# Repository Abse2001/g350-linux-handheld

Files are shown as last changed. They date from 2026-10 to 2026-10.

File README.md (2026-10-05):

# G350 AM3352 Linux handheld — in progress

**Cloud continuation:** start with [the complete handoff](docs/CLOUD_HANDOFF.md),
[the original user-visible chat](docs/CHAT_CONTEXT.md) and [AGENTS.md](AGENTS.md).
The full authored project and hash-indexed ignored routing evidence are preserved;
restore with `python3 scripts/restore-cloud-evidence.py`. Ubuntu cloud setup is
`bash scripts/setup-cloud.sh`, followed by `source cloud/env.sh` in each shell.
The checked default is still the eleven-signal byte0 subset. Latest byte1 source
replays and native failures are preserved separately; their aggregate/remaining
independent checks are pending. This transfer does not make the PCB order-ready.

The selected processor is a **bare TI AM3352BZCZ100**, directly on the main PCB, with **512 MB Micron MT41K256M16TW-107:P DDR3L** operated in DDR3-compatible mode. The user chose AM3352 for simple games rendered by the CPU; a 3D GPU is no longer required. The design is authored in **tscircuit**, using individually imported JLCPCB components. No complete SBC or processor module is imported.

**The integrated handheld is not ready to fabricate or order.** The current checked routing entry is [`experiments/am3352-g350-byte0-complete-bus.circuit.tsx`](experiments/am3352-g350-byte0-complete-bus.circuit.tsx): **280 placed components, four copper layers, a 76 × 118 mm shaped outline and 1.6 mm nominal thickness**. The lower speaker tab is 22 mm wide with a 19 mm extension. This routing entry and its CPU/RAM power replay both match the shared mechanical geometry; run `node scripts/check-g350-mechanical-envelope.mjs` to check them. These are provisional dimensions inside the published exterior envelope; mounting posts, shell ribs and button/port alignment remain unmeasured. The default `index.circuit.tsx` now opens this current shaped handheld. Older 212-component routing fixtures remain historical experiments; their channel counts do not qualify this layout. DDR and other critical routing, Linux provisioning and original-shell fit remain unfinished. The fabrication exporter remains blocked by `design-status.json`.

On the current shaped board, **all 101 CPU/RAM ground and DDR supply terminals** reach their correct filled reference planes through 97 physical vias. **All eleven byte0 signals** use native `bus_lanes` carriers and manually repaired routes, with their complete source-bus definition restored. Byte0 planar skew is **0.207792 mm against 0.635 mm**; strobe-pair skew is effectively zero against 0.127 mm. Numeric-pad connectivity, all-layer Gerber shorts and independent physical DRC pass for this subset. The source has **112 traces and 119 standard through-vias**. There are **38 DDR signals to route**, 403 silkscreen warnings, 818 open-port errors and 108 missing-trace errors. Bypass loops, complete timing and stackup impedance remain unqualified. [Current routing checks](checks/integrated/g350-byte0-complete-bus/check-summary.json), [bottom snapshot](checks/integrated/g350-byte0-complete-bus/g350-byte0-bottom.png), [routing notes](docs/G350_CURRENT_DDR.md). The separate byte1 experiment now has 22 manual package escapes with zero native geometry errors. Its native `bus_lanes` carrier attempt exhausted the strobe-pair search budget; the actual-source fanout replay returned the cached escapes but its implicit completion stage exceeded the external deadline. No completed byte1 source or new connected signals are qualified; the checked default is preserved. [Experimental findings](checks/integrated/g350-ddr-bootstrap/byte1-package-access-findings.json).

The completed handheld must have eleven front buttons, an FPC display, an onboard microSD holder and one USB-C connector for charging and data/provisioning. Components and copper routing are allowed on both sides. There are no analog sticks or rear buttons.

The historical command package-access study independently verifies **all 48 CPU/RAM pad-to-via exits for the 24 command/control signals**, while retaining both data bytes, reset and the clock pair. Shorts, copper/drill clearance and filled RAM reference checks pass. The diagnostic has 25 retained complete DDR channels, 48 dangling terminal-via warnings and 24 unfinished commands. Subsequent phased native routing plans six carriers; manual repair plans five more, leaving 13 unresolved. These carriers still need a combined editable replay and independent checks. The best checked complete-signal subset remains DDR42. [Package-exit evidence](checks/integrated/am3352-command-compatible-fanouts-802-check-summary.json). Fabrication remains blocked; no remote publication was made.

The latest separate **DDR42 checkpoint connects 42/49 DDR signals**, with 144 trace pieces and 187 full-depth through-vias. Independent numeric-pad connectivity, all-layer Gerber shorts and physical clearance/drill checks pass. Both byte groups and all three differential pairs pass relative planar skew. **Seven signals remain open:** A3, RASn, WEn, A2, A12, A11 and CKE. Seventeen command/clock nominal lengths and seven reduced-spacing exposures need repair; complete DDR timing and signal integrity remain unqualified. The updated `bus_lanes` phase preserves the fixed copper and physical pads but has no complete new output. [Checked evidence](checks/integrated/am3352-command-fine-782-replay-check-summary.json), [editable replay](experiments/am3352-command-fine-782-replay.circuit.tsx), [native phase entry](experiments/am3352-command-fine-782-replay-native-phase.circuit.tsx). At that historical checkpoint the default stayed DDR30; fabrication remains blocked.

The previous spacing-repaired **copper checkpoint connects 33/49 DDR signals**, with 135 trace pieces and 169 through-vias. A guarded wire-only D12 shortcut repairs its reduced class-spacing exposure from **32.176112 mm to 28.195190 mm**, within the **31.75 mm allowance**, without changing any holes or other routes. D12 is **50.983197 mm**; byte0/byte1 relative skews are **0.157421/0.496669 mm** and all three pairs retain their relative limits. Fresh native DDR/USB/filled-reference connectivity, all-layer Gerber shorts and physical DRC pass, with 418 presentation warnings, 499 reported/capped host opens and recorded ignored checks. **Sixteen DDR signals remain open**; CK/CKn/CKE/A3/A6 nominal repairs and complete spacing, impedance, return-path, termination and timing qualification remain required. [Checked copper](checks/integrated/am3352-ddr-usbc-d12-spacing-repaired-check-summary.json), [partial spacing audit](checks/integrated/am3352-ddr33-d12-repaired-class-spacing.json), [top](images/am3352-ddr-usbc-d12-spacing-repaired-top.png) and [bottom](images/am3352-ddr-usbc-d12-spacing-repaired-bottom.png). Revalidate with `npm run check:ddr-d12-spacing-evidence` and `npm run check:ddr-class-spacing`. That historical checkpoint retained the 30/49 default; fabrication remains blocked.

A separate **bottom-side RAM placement study** retains all 212 host components, 912 pads and 49 logical DDR connections. RAM references and shared USB-C copper pass fresh independent checks on four layers; fourteen small RAM bypass capacitors move to top, and all 89 existing holes remain standard 18/10 mil through-vias. DDR is entirely unrouted in this study. Native all-channel and ordered-fanout trials **704–709** prepare real endpoints but have no complete output; no partial routes are promoted. An initial eight-USB-via size failure is retained as rejected evidence, followed by a corrected, checked rebuild. [Placement checks](checks/integrated/am3352-ram-bottom-via-style-corrected-check-summary.json), [seven bound terminal trials including D12 repair 703](checks/integrated/am3352-ddr33-d12-ram-bottom-trial-status.json). Revalidate with `npm run check:ram-bottom-evidence` and `npm run check:ddr-d12-ram-bottom-trials`.

The newer bottom-RAM replay has **28/49 connected DDR signals**, comprising **19 retained native bus-lane paths and nine manual paths**. All original 102 host/USB/reference trace pieces and 89 physical holes remain exact; this candidate has 130 trace pieces and 129 through-vias. Independent numeric-pad DDR/USB and filled-reference connectivity, all-layer shorts and physical DRC pass. **21 DDR signals remain open**, both byte groups are incomplete, and command matching/nominal lengths remain unqualified. Its separate placement-derived command target is **40.62 mm**; this does not change the top-RAM target. All 28 connected paths pass the partial reduced-spacing exposure limit, with a maximum of 31.421059 mm; complete spacing and signal integrity remain unchecked. A selected-terminal-via search-model bug was corrected and regression checked. The unsolved native run is retained as provenance, rather than represented as a solved 49-channel output. [Checked replay](checks/integrated/am3352-ram-bottom-flexible-fanout-747-replay-check-summary.json), [electrical review](checks/integrated/am3352-ram-bottom-flexible-fanout-747-replay-spacing-and-nominal-review.json), [38 terminal trials](checks/integrated/am3352-bottom-manual-trial-status.json), [top](images/am3352-ram-bottom-flexible-fanout-747-replay-top.png) and [bottom](images/am3352-ram-bottom-flexible-fanout-747-replay-bottom.png). That historical study retained the 30-signal default and separate 33-signal checkpoint. Nothing was pushed or released for ordering.

The earlier **A6 copper bootstrap connects 32/49 DDR signals** in one source, with 134 trace pieces and 163 through-vias. It supplies the checked prior geometry for the CASn replay. Its A6=51.715840 mm and A3=45.411583 mm nominal failures remain required repairs. [Prior scoped checks](checks/integrated/am3352-ddr-usbc-a6-bootstrap-check-summary.json); `npm run check:ddr-a6-bootstrap-evidence`.

The earlier **A3 copper bootstrap connects 31/49 DDR signals**, with 133 trace pieces and 161 through-vias. It preserves every checked DDR30 trace and hole. Native DDR/USB/reference connectivity, all-layer shorts and physical DRC pass, but **A3=45.411583 mm fails the nominal range**. The wire-only shortcut search could not bring it into range. This checkpoint supplies the checked prior copper for the separate A6 replay. [A3 bootstrap checks](checks/integrated/am3352-ddr-usbc-a3-bootstrap-check-summary.json). Revalidate with `npm run check:ddr-a3-bootstrap-evidence`.

Earlier DQM1/D10 access trials routed native CASn and CSn0 but could not restore the two data routes. Those incomplete stages remain non-exportable and are superseded by the complete D3-coupled replay above. [Historical bound trials](checks/integrated/am3352-ddr32-casn-neighbor-replan-trial-status.json); `npm run check:ddr-casn-neighbor-replan-trials`.

The board must **fit the original G350 shell**. Its listed 81 × 128 × 22 mm outside dimensions do not establish the internal PCB outline. The working G350 outline is **76 × 118 mm**, with chamfered corners and a lower speaker tab; see the [dimensioned drawing](mechanical/g350-provisional-outline.svg). The nominal centered margins from the outside case are 2.5 mm per side and 5 mm per end; the USB-C assembly courtyard projects 0.651 mm past the top PCB edge. These are engineering allowances, not measured internal clearances or a verified original-board replacement. The historical 100 × 124 mm routing fixture does not fit the case and is not the mechanical target. Original screw posts, button centers, port openings and assembly clearances still require verification. [Shell-fit requirements](docs/G350_SHELL_FIT.md).

The historical DDR30 default was `experiments/am3352-ddr-usbc-wen-nominal.circuit.tsx`: **30/49 DDR signals connected**, with **132 trace pieces and 157 through-vias**. A native `bus_lanes` WEn carrier inside the DDR reference bounds and guarded manual package fanouts give **WEn=43.228641 mm**, within the placement-derived 41.75–44.29 mm nominal range. Every checked DDR29 trace and hole remains unchanged. A5 remains **43.020000 mm**, CSn0 **42.800714 mm**, ODT **43.018281 mm** and D14 **50.919109 mm**. Both bytes and all three differential pairs retain their checked relative planar limits. Exact native DDR/USB/reference connectivity passes, with zero all-layer Gerber shorts and reported physical DRC violations, 418 presentation warnings and 499 reported/capped host opens. All 18 RAM supply balls, 21 ground balls and 28 bypass terminals reach the connected filled reference planes. Configured ignored native checks remain recorded. CKE/clock nominal lengths still fail; the **19 remaining address/control signals**, full command matching, package/via delays, coupling/impedance, powered host/Linux and original-shell fit remain unqualified. [Checked evidence](checks/integrated/am3352-ddr-usbc-wen-nominal-check-summary.json); [top](images/am3352-ddr-usbc-wen-nominal-top.png) and [bottom](images/am3352-ddr-usbc-wen-nominal-bottom.png) snapshots. Revalidate with `npm run check:ddr-wen-evidence`. Earlier candidates below are historical evidence.

The historical DDR28 replay is `experiments/am3352-ddr-usbc-csn-joint.circuit.tsx`: **28/49 DDR signals connected**, with **130 trace pieces and 149 through-vias**. A native `bus_lanes` CSn0 carrier and guarded manual package fanouts add **CSn0 at 42.800714 mm**, within the placement-derived 41.75–44.29 mm nominal range. D10 remains unchanged; only D14's CPU prefix is repaired with two vias, giving **D14=50.919109 mm**. All 147 old holes and the other 128 traces remain unchanged. Byte0/byte1 skews remain **0.157421/0.635000 mm**; DQS1/CK skews remain **0.079409/0.076616 mm** against 0.127 mm. Exact native DDR/USB/reference connectivity passes, with zero all-layer Gerber shorts and reported physical DRC violations, 418 presentation warnings and 499 reported/capped host opens. All 18 RAM supply balls, 21 ground balls and 28 bypass terminals reach the connected filled reference planes. The configured ignored native checks remain recorded. CKE/clock nominal lengths still fail; the **21 remaining address/control signals**, complete command matching, package/via delays, coupling/impedance, powered host/Linux and original-shell fit remain unqualified. [Checked evidence](checks/integrated/am3352-ddr-usbc-csn-joint-check-summary.json); [top](images/am3352-ddr-usbc-csn-joint-top.png) and [bottom](images/am3352-ddr-usbc-csn-joint-bottom.png) snapshots. Revalidate with `npm run check:ddr-csn-evidence`.

The historical unmatched **26/49 DDR continuity candidate** adds CKE using a native bus_lanes channel and manually repaired RAM fanouts. All exact DDR/USB and RAM reference connections pass, with zero all-layer shorts and physical DRC violations. A bounded DDR power-plane clearance change restores the RAM supply island while preserving manufacturing minimums and plane boundaries. **DQS1 and byte1 skew still fail at 10.167587/10.584847 mm**, and CKE is longer than the current placement-derived nominal range. This earlier candidate remains separate from the repaired default. [Scoped evidence](checks/integrated/am3352-ddr-usbc-cke-joint-power-plane-bounded-check-summary.json); [top](images/am3352-ddr-usbc-cke-joint-power-plane-bounded-top.png) and [bottom](images/am3352-ddr-usbc-cke-joint-power-plane-bounded-bottom.png) snapshots. Revalidate with `npm run check:ddr-cke-joint-plane-evidence`.

The historical separate **25/49 DDR continuity trial** restores both strobes around a freshly routed native `bus_lanes` clock pair. All 25 exact CPU/RAM pad pairs, shared USB-C copper and RAM plane/bypass connections pass independent checks, with zero physical DRC violations and all-layer Gerber shorts. The clock pair passes its 0.127 mm planar limit at **0.076616 mm**. **Strobe and whole-byte1 matching still fail at 7.145626 mm**; strobe via counts are also unequal. This 127-trace/137-via trial does not replace the checked default. Its 24 address/control signals, full electrical timing, complete host and measured original-shell layout remain unfinished. [Scoped checks](checks/integrated/am3352-ddr-usbc-clock-strobes-unmatched-check-summary.json); [editable source](experiments/am3352-ddr-usbc-clock-strobes-unmatched.circuit.tsx); [top](images/am3352-ddr-usbc-clock-strobes-unmatched-top.png) and [bottom](images/am3352-ddr-usbc-clock-strobes-unmatched-bottom.png) snapshots. Revalidate with `npm run check:ddr-strobe-evidence`.

The newest coordinated diagnostic preserves eleven byte0 channels and independently verifies all **74 remaining byte1/command escape terminals** around them. All-layer shorts and clearance violations are zero, and RAM plane connections pass. Those reservations add no complete channels; byte0 length matching still fails, and dangling copper remains. The separately matched byte1 candidate has not been merged. [Combined reservation checks](checks/integrated/am3352-ram-rotated-180-byte0-fixed-reused-reservations-check-summary.json).

A newer whole-byte-swap alternative routes all eleven byte0 channels with **24 DDR vias**. Independent pad/plane connectivity, shorts and physical DRC checks pass, but whole-byte skew still fails at 13.889 mm against 0.635 mm. Native preparation can reserve the remaining 74 terminals around that copper; byte1 routing remains incomplete. This separate candidate does not replace or add channels to the default layout. [Swapped-byte checks](checks/integrated/am3352-ram-rotated-180-byte-swapped-byte0-pair-check-summary.json).

A separate **212-component USB-C source draft** now adds the shared charging/data socket, USB0 ESD protection, independent CC pull-downs and a VBUS sensing filter/clamp. Generated connections and all 36 exported USB numeric-pad assignments pass. Its existing eleven DDR channels and RAM plane connections pass fresh native checks; shorts and physical DRC violations are zero. **USB traces, charger current policy, VBUS temperature/transient limits and Linux provisioning remain unfinished**, along with the measured original-shell layout. No finished board was imported. [USB-C checks](checks/integrated/am3352-usbc-device-check-summary.json); source: `experiments/am3352-usbc-device-source.circuit.tsx`.

The newer **USB copper replay** routes data from the CPU through ESD protection to both connector orientations, both CC/Rd connections, local VBUS bypass and ground returns. Native `bus_lanes` supplies the pair/CC bootstrap; manual connections and tuning supplement it. Fresh source, KiCad connectivity, physical DRC and all-layer shorts checks pass. Both data orientations have **0.0635 mm planar skew**, with equal via counts within each orientation. The replay adds 23 trace pieces and 12 through-vias while preserving its eleven DDR channels. **The PMIC VBUS feed, CPU VBUS sensing, controlled impedance, current policy, remaining DDR/host routing, Linux provisioning and shell fit remain unfinished.** This candidate remains separate from the default 23-channel DDR source. [Routed USB checks](checks/integrated/am3352-usbc-routed-check-summary.json), [editable source](experiments/am3352-usbc-routed-replay.circuit.tsx), [PCB snapshot](images/am3352-usbc-routed-top.png).

## DDR routing workflow

The [tscircuit DDR routing guide](https://docs.tscircuit.com/guides/routing-ddr) was rechecked on 2026-10-04, including the complete AM3352 example. The native preset is `autorouter="bus_lanes"`. The default circuit uses this preset to generate local dogbones and route the channel. Manual fanouts, placement changes and local trace repairs may supplement it when needed; successful copper still requires independent checks.

The new fixture declares **49 actual shared DDR signals**, two 11-signal byte buses, a 26-signal command/clock timing group, and separate reset. It declares both DQS differential pairs and the CK pair. The 4 Gb x16 memory uses A0–A14; its M7 is NC. CPU DDR_A15 is therefore unused. Numeric port selectors avoid collisions between RAM ball labels such as A3 and address-function aliases with the same name.

All **324 CPU and 96 RAM balls**, functions and nominal 0.8 mm grids have been checked against the manufacturer documents. The supplier import's incomplete CPU aliases and malformed RAM aliases were corrected. CPU pads use TI's 0.4 mm example lands; RAM pads use the Micron TW drawing's 0.42 mm lands. This is a nominal geometry/function check, not complete solder-mask or assembly qualification. See `checks/integrated/am3352-import-validation.json`.

The historical repaired-strobe source connects **25/49 DDR signals**: both complete byte lanes, reset and CK/CKn. Byte0 uses bottom, byte1 top, and inner1 GND/inner2 DDR power remain reference planes. Manual RAM strobe escapes supplement the native bootstrap. Removing a redundant inward CPU/channel turn shortens DQS1 from 53.720144 to 50.953139 mm; DQSn1 is 51.001321 mm. Every other route of the checked clock source remains unchanged. Both bytes, both DQS pairs and CK pass their separate planar limits, while the complete command/clock group correctly fails because its 24 address/control signals are open. All 25 exact CPU/RAM pad pairs are independently verified in KiCad. This does not qualify full electrical timing or fabrication.

A separate fresh native bootstrap now reserves all **96 CPU/RAM breakouts for all 48 synchronous DDR signals together**, retaining the original power copper and four-layer limit. KiCad verifies all 96 pad-to-via connections and the RAM plane/bypass connections. Gerber shorts and clearance errors are zero; all 96 unfinished-via warnings remain. This creates no new complete channel and does not replace the checked 23-signal default. [Joint breakout checks](checks/integrated/am3352-joint-native-breakout-check-summary.json).

The next separate trial has **all 52 natural command/clock fanouts connected to their exact CPU/RAM pads**, with zero all-layer shorts and clearance errors. Its 47 dangling-via and 44 dangling-track warnings remain. [Natural fanout checks](checks/integrated/am3352-natural-command-fanouts-check-summary.json).

A terminal-via diagnostic also passes all 52 pad-to-terminal checks with zero all-layer shorts and clearance violations. It retains 96 dangling-via warnings and completes no new DDR channel. The current repair uses only four added clock-terminal vias, the native `bus_lanes` clock bootstrap and temporary manual bridges on top/bottom. Command-bus crossings and original timing limits must pass before accepting any routes. [Terminal checks](checks/integrated/am3352-dual-layer-command-terminal-check-summary.json).

The separate command/clock replay now connects **all 26 command signals**. Native `bus_lanes` supplies the bootstrap and two clock channels; manual fanout/channel repairs and A2 loop cleanup supplement it. The actual tscircuit source passes all-layer shorts and independent KiCad pad connectivity, RAM reference connectivity and physical DRC at every severity. It has 95 trace pieces and 199 through-vias. **Length matching still fails:** command skew is 53.182 mm against 0.635 mm, and clock skew is 2.898 mm against 0.127 mm. Its two bytes and reset are open. A merge screen finds five via/hole conflicts with the active byte routes, so these separate results do not make a 49-signal DDR board. [Command checks](checks/integrated/am3352-command-unmatched-pruned-check-summary.json), [editable replay](experiments/am3352-command-unmatched-pruned-replay.circuit.tsx).

The newer command-first diagnostic verifies all **44 native CPU/RAM byte breakouts** against that command copper, with zero all-layer shorts and clearance violations. It preserves all 26 command channels but adds no complete byte channel. Its 22 dangling-via and 22 dangling-track warnings remain. A separate local-access trial opens WEn, RASn and ODT to plan compatible byte routing; those nets still require complete rerouting and matching. [Byte-breakout checks](checks/integrated/am3352-command-first-native-byte-check-summary.json).

An earlier placement trial rotates RAM by **180°**, with explicitly transformed and checked supply escapes. Its joint native bootstrap verifies all 96 synchronous pad-to-terminal connections and preserves all 39 RAM supply/ground and 28 bypass-plane connections. The pruned reservation retains 74 dangling-via and 22 dangling-track warnings and adds no complete channel. [Rotated breakout checks](checks/integrated/am3352-ram-rotated-180-pruned-breakout-check-summary.json).

A separate editable replay of that placement now connects **all eleven byte0 signals through native `bus_lanes` channels and manual fanouts**. Actual tscircuit and KiCad checks confirm zero all-layer shorts, zero physical DRC violations, and preserved RAM plane connections. DQS skew is zero, but whole-byte skew is **16.105 mm against 0.635 mm**. It has 80 trace pieces and 99 through-vias; 38 DDR signals remain open. This candidate is separate from the active 23-signal layout, and routes from the old RAM orientation cannot be combined with it. [Rotated byte0 checks](checks/integrated/am3352-ram-rotated-180-byte0-pair-check-summary.json), [editable replay](experiments/am3352-ram-rotated-180-byte0-pair-replay.circuit.tsx).

## Build and verify

Versions reverified against the registry on 2026-10-05: **tscircuit 0.0.2744**, **tsci CLI 0.1.2237**, **capacity-autorouter 0.0.958**, and **core 0.0.2088**, **props 0.0.687** and **checks 0.0.239**. The project pins one core version, Circuit JSON 0.0.515 and React 19.3.0 so clean installs load compatible peers. Both lockfiles are synchronized; use `bun install --frozen-lockfile` or `npm ci --legacy-peer-deps`. The selected byte0 phase completes and typechecking and all-layer Gerber shorts pass. The whole-board build still reports its unfinished connections. The latest core audit preserves all physical records outside the explicitly reviewed D3 bend and sub-picometre handoff-coordinate repairs, and restores all eleven byte0 bus members. Previously checked circuit/board files remain fixed evidence. [Current upgrade and source checks](checks/integrated/g350-byte0-complete-bus/core-upgrade-and-bus-check.json).

Run direct CLI commands with **`node_modules/.bin/tsci`**; npm scripts already select the project binary. The shell's older global `tsci` reports runtime 0.0.2444 and omits the microSD keepouts in KiCad exports. Affected new exports and shorts checks were rerun with the project CLI. Latest-project-CLI builds reproduce every non-metadata record of both new clock/strobe replays; frozen earlier source snapshots remain intact.

```sh
npm ci --legacy-peer-deps
npm run typecheck
npm run check:am3352-imports
npm run check:am3352-swizzle
npm run build:host-netlist
npm run check:power-netlist
npm run check:boot-netlist
npm run check:storage-netlist
node_modules/.bin/tsci build index.circuit.tsx --disable-parts-engine --autorouter-phase G350_BYTE0_MATCHED --autorouter-timeout 180s
npm run check:memory-connectivity
npm run check:shorts
```

The legacy peer option is required by the current upstream packages' circuit-json peer versions. All-layer Gerber shorts, full signal connectivity, end-to-end skew measurements and independent KiCad copper/drill checks must be run on actual exported AM3352 copper. The completed handheld requires fresh checks after power and peripherals are integrated.

`build:host-netlist` disables automatic routing. Source audits accept only the exact documented package reference escapes and bypass loops, including same-net drill separation; they do not approve arbitrary copper. The checks cover voltage domains, power/reset controls, internal-output isolation, DDR VREF/VTP/ZQ, bypass placement, boot straps and the actual microSD pinout/keepouts. The current shaped-board DDR audit reports eleven connections and still fails on 38 open signals. The historical DDR30 audit fails on 19 open signals; the latest separately checked DDR42 replay has seven opens and still fails command nominal lengths and reduced-class spacing. Both completed byte groups pass their relative planar and physical checks. Remaining host copper and full electrical qualification are unfinished. The partial physical summary rejects copper/drill violations even when KiCad reports them as warnings.

## Repositories and records

- [GitHub](https://github.com/Abse2001/g350-linux-handheld)
- [tscircuit: AM3352 experimental source v1.3.3](https://tscircuit.com/abse/g350-linux-handheld?version=1.3.3-integrated-experimental)
- [Current integrated-host record](docs/INTEGRATED_HOST.md)
- [Historical RK3566 host investigation](docs/RK3566_HOST_RECORD.md)
- [Historical RK3566 memory experiments](docs/RK3566_MEMORY_EXPERIMENTS.md)
- [Historical Revision B carrier](docs/REV_B_CARRIER.md)

Work remains local; GitHub and tscircuit are pushed only on a meaningful breakthrough, as requested. Registry publication is not fabrication approval. `tsci push` ignores `.gitignore`; use the tracked source allowlist in `scripts/stage-registry-source.mjs` and verify every published file hash. Reference PDFs, temporary files and historical manufacturing archives are excluded.

Historical RAM180 milestone: a separate RAM180 replay connects **all eleven byte1 signals**, using native `bus_lanes` channels and manually tuned local fanouts. Actual tscircuit and independent KiCad checks pass shorts, copper/drill clearance, correct numeric pad connectivity and every RAM supply/ground/bypass connection. Whole-byte planar skew is **0.000759 mm against 0.635 mm**, and strobe skew is effectively zero against 0.127 mm. This replay has 81 trace pieces and 111 through-vias. Its other 38 DDR signals remain open; full host routing, impedance, Linux startup and original-shell fit are unfinished. It is not order-ready. [Editable replay](experiments/am3352-ram-rotated-180-byte1-matched-replay.circuit.tsx), [checks](checks/integrated/am3352-ram-rotated-180-byte1-matched-check-summary.json), [snapshot](images/am3352-ram-rotated-180-byte1-matched-top-detail.png). Revalidate with `npm run check:rotated-byte1-matched-evidence`. Other candidate channel counts cannot be added to this result.

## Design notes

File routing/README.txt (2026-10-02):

Revision B routing provenance

The local capacity-autorouter 0.0.951 Pipeline 9 generated all three phases using tscircuit 0.0.2715. The original complete run is in initial-autorouter-run.log. Its final geometry had clearance errors, subsequently corrected without lowering any clearance rule.

Manual corrections after that run:
- Moved the DOWN input via to (-0.9,-0.9), clear of adjacent pads, the reset path and the B-button route.
- Jogged the A-button inner2 bridge through y=-1.7 to clear that full-depth via.
- Jogged the CC1 route around the USB data via, with a vertical entry to its fine-pitch connector pad.
- The source reset path crosses the controller above these vias at y=0.
- The source I2S frame-clock path bends around the Pi mounting hole while clearing the FPC anchor.

rev-b-routes.json contains only each phase's own retained solver routes, including those manual corrections. Ground contacts are regenerated from current pads. SavedRouting.ts checks the SHA256 of every full phase input, including earlier copper, and the pinned versions before reuse. A mismatch runs the live solver. No draft-cache bypass exists in the released code. Final native, shorts and independent KiCad checks are in checks/, with the exported artifact hashes in fabrication/SHA256SUMS.

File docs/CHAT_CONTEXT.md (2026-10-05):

# G350 complete user-visible chat context

Exported 2026-10-05T23:45:49.782756+00:00 from the original project task, starting 2026-10-01.
All 1115 recorded human messages and visible assistant replies through
this snapshot are included below in chronological order. The user's structured
question answers are retained verbatim. Later messages from the transfer itself
are recorded separately in the handoff status.

System/developer instructions, private reasoning, raw tool payloads, automatic
goal prompts and machine environment messages are excluded. Engineering sources,
commands, results and remaining work are indexed in [CLOUD_HANDOFF.md](CLOUD_HANDOFF.md)
and the committed project evidence. Historical assistant claims must be assessed
against their matching source and check reports; they do not qualify today's PCB.

## 1. User — 2026-10-01T20:56:00.849Z

Make the G350 Gameboy Linux using tscircuit make sure to import any needed components from jlcpcb use autorouting phases and manual traces if needed but still uses autorouter also make sure it's fabrication ready we don't need the analog sticks or the back buttons make sure to update tscircuit to the latest version use tsci make both github and tscircuit repo for it also make sure to use check shorts and checks

## 2. Assistant — 2026-10-01T20:56:03.576Z (commentary)

I’ll check the workspace and current tscircuit tooling, then identify the G350 hardware requirements and build the board with autorouting, fabrication exports, and electrical checks. I’ll also set up the GitHub and tscircuit repositories.

## 3. Assistant — 2026-10-01T20:56:52.610Z (commentary)

The workspace is empty. The commercial G350 uses an RK3326, but I haven’t found a complete public schematic to reproduce it reliably. I’m checking documented Linux module options while you choose the architecture.

I also found tscircuit’s current workflow for phased autorouting and Gerber-based short checks, and I’m updating the project tooling.

## 4. Assistant — 2026-10-01T20:58:08.724Z (commentary)

Both GitHub and tscircuit logins work with network access. Unless you choose the RK3326 replica, I’ll proceed with a G350-style carrier for a Raspberry Pi Zero 2 W, a documented 3.5-inch display, and front buttons only.

I’m following the [tscircuit design skill](https://github.com/tscircuit/skill/blob/main/SKILL.md). I’ll distinguish checks on the manufactured PCB from hardware and enclosure tests that require a prototype.

## 5. User — 2026-10-01T20:58:31.055Z

If the rocket chip is hard maybe pick another chip that can run Linux and have gpu or maybe we use dual chips instead of gpu like two rp2350 if it's resources can handel it

## 6. Assistant — 2026-10-01T20:58:35.798Z (commentary)

I’ll use the Raspberry Pi Zero 2 W: its quad-core Cortex-A53 processor runs Linux and includes a VideoCore IV GPU. That gives us a documented processor and memory module to design around.

Two RP2350s wouldn’t provide the same Linux and GPU capabilities. I’ll keep the D-pad and front buttons, omit the sticks and rear buttons, and build the carrier with JLCPCB parts.

## 7. Assistant — 2026-10-01T20:59:49.378Z (commentary)

The architecture is set: Pi Zero 2 W for Linux and graphics, an I²C expander for the front buttons, and SPI and I²S connections for the display and audio. I’ve imported the controller, switches, and battery-signal transistor from JLCPCB with exact footprints.

I’m now placing the parts and assigning routing phases before running the netlist, placement, routing, and short checks.

## 8. User — 2026-10-01T21:02:45.815Z

Raspberry Pi Zero 2 W you will use the same chip as Raspberry Pi Zero 2 W: not the whole board right ?

## 9. Assistant — 2026-10-01T21:03:03.934Z (commentary)

I had planned to use the complete Zero 2 W board. Your clarification changes that: I’ll switch to a bare-processor design.

The Pi’s RP3A0 package isn’t a practical choice for this custom PCB. I’ll check a purchasable Linux SoC with a GPU, a public reference design, and JLCPCB availability before replacing the carrier.

## 10. User — 2026-10-01T21:03:55.751Z

you can use the whole board but make it using tsciruit don't import it ready

## 11. Assistant — 2026-10-01T21:04:06.103Z (commentary)

Understood: you want the computer circuitry drawn and laid out in tscircuit, with individual component imports. I’ll build the processor, memory, power, boot storage, display, audio, and front controls as part of the custom design.

I’m checking the H3 reference design because its bare chip is listed by JLCPCB and includes a Mali GPU.

## 12. Assistant — 2026-10-01T21:04:47.437Z (commentary)

The H3 component import is available, but its library labels identify ball locations rather than signal functions. I’m mapping those balls against the processor datasheet and published schematic; that has to be verified before wiring memory or power.

I’m using the PDF skill to inspect the reference drawings while I replace the Pi carrier circuitry.

## 13. Assistant — 2026-10-01T21:08:07.092Z (commentary)

The full computer design is much more involved because the H3 needs DDR memory routing and several power rails. Your latest message may allow a simpler design using a mounted Pi Zero 2 W, so I’m clarifying that before committing the processor layout.

## 14. Assistant — 2026-10-01T21:09:32.160Z (commentary)

I’ll proceed with the mounted Pi Zero 2 W interpretation of “whole board,” using a model we draw in tscircuit. I’m integrating the charger, 5 V boost supply, audio amplifier, and front controls into the custom PCB with JLCPCB component imports.

## 15. Assistant — 2026-10-01T21:11:44.373Z (commentary)

The USB-C input will use a conservative 500 mA limit, and the battery connector will include temperature sensing. The Pi has its own microSD slot; the custom board will provide eleven front buttons, I2S audio, battery monitoring, and the display connection.

## 16. Assistant — 2026-10-01T21:16:48.075Z (commentary)

The netlist now passes with zero errors and warnings. Placement checks found several overlaps near the Pi header and mounting holes; I’m moving those parts and tidying the schematic before routing.

## 17. Assistant — 2026-10-01T21:19:20.924Z (commentary)

I replaced the generic Pi header footprint with a drawing that explicitly pairs J8’s odd and even pin rows. I’m checking the generated geometry next, then I’ll route the power, display/audio, and control nets in phases.

## 18. Assistant — 2026-10-01T21:22:40.369Z (commentary)

The autorouter is still completing the power phase. It has progressed through routing and repair and is now widening power traces. I’ve also added assembly instructions and a Linux button-input daemon; those will need testing on a physical prototype.

## 19. Assistant — 2026-10-01T21:25:31.819Z (commentary)

The later routing phase failed because it couldn’t fit the remaining connections around fixed ground routes. I’m correcting the phase assignments and routing signals before the broad power nets, then rebuilding. The board will need a clean routing result before I can call it fabrication ready.

## 20. Assistant — 2026-10-01T21:27:52.555Z (commentary)

The new control phase has completed without routing errors, and the display/audio phase is progressing. A new tscircuit release, 0.0.2706, appeared during this work; I’m updating to it and will run the final checks with that version.

## 21. Assistant — 2026-10-01T21:31:23.832Z (commentary)

Every connection is now assigned explicitly to one of the three routing phases. This should eliminate the leftover phase that caused the earlier failure. I’m also preparing the fabrication export to reject unresolved assembly rotations rather than guessing them.

## 22. Assistant — 2026-10-01T21:32:32.290Z (commentary)

I’m moving to four layers to provide a dedicated ground plane and more room for the battery and boost-supply connections. I’m also widening those rails. This changes the PCB stackup, so I’ll rerun routing, placement, and shorts checks.

## 23. User — 2026-10-01T21:43:11.536Z

keep going

## 24. Assistant — 2026-10-01T21:43:14.480Z (commentary)

I’m continuing the routing and fabrication checks. The custom tscircuit carrier uses the complete Pi Zero 2 W, with a connector and mounting layout drawn in the project.

## 25. Assistant — 2026-10-01T21:43:56.014Z (commentary)

I found and corrected an assembly-export issue: the pick-and-place converter needs hand-fitted headers excluded at the PCB-component level. I’m also requiring verified supplier rotations before it can produce an assembly file.

## 26. Assistant — 2026-10-01T21:44:55.683Z (commentary)

The controls phase routed with zero errors, and the current netlist and TypeScript checks pass. The GitHub repository is created; I’m continuing through display/audio routing, power routing, and the copper shorts check.

## 27. Assistant — 2026-10-01T21:45:54.720Z (commentary)

PCB placement passes with no errors or warnings. The pin-specification check found missing electrical-role annotations on the Pi interface, USB connector, and charger; I’m adding those so the checks cover their power and ground pins.

## 28. Assistant — 2026-10-01T21:47:04.300Z (commentary)

Display/audio routing also completed with zero errors. The updated pin-specification check now has zero warnings. Power routing is the last phase before I can run the Gerber-based shorts check and inspect the fabrication outputs.

## 29. Assistant — 2026-10-01T21:49:16.759Z (commentary)

Both repositories now exist, and I’ve published the source as a draft with a clear “do not order yet” status. The power phase is still progressing through the wider supply routes; fabrication files will remain gated on the final checks.

## 30. Assistant — 2026-10-01T21:49:56.599Z (commentary)

The power phase failed because the autorouter found a conflict with an earlier SCL route. I’m inspecting that connection and changing the routing approach; this revision remains unqualified for fabrication.

## 31. Assistant — 2026-10-01T21:55:03.791Z (commentary)

I replaced the Pi-to-fuel-gauge SCL branch with a manual outer-layer trace to remove the conflicting via cluster. The remaining connections still use the three autorouting phases. I’m checking the new trace geometry as the full reroute runs.

## 32. Assistant — 2026-10-01T21:56:42.016Z (commentary)

The new SCL trace lands on the intended pads, but the router is spending excessive time subdividing the plane boundaries. I’m simplifying those constraints and trying another tscircuit routing pipeline, then I’ll rerun the copper checks.

## 33. Assistant — 2026-10-01T21:58:41.218Z (commentary)

The Gerber shorts check caught a contact between the manual SCL trace and an I2C pull-up pad. I’m moving the trace below that pad and rerunning the check before accepting the new routing.

## 34. Assistant — 2026-10-01T22:00:44.800Z (commentary)

The corrected manual traces pass the all-layer Gerber shorts check. The new routing pipeline also completed the controls phase with zero errors. I’m continuing through display/audio and power, then I’ll check the fully routed board.

## 35. Assistant — 2026-10-01T22:04:01.206Z (commentary)

All 44 SMD assembly placements have verified JLCPCB rotation metadata, and the latest placement and pin checks pass. I’ve also added an export gate that rejects fabrication files unless the full three-phase build and final shorts check succeed.

## 36. Assistant — 2026-10-01T22:05:22.777Z (commentary)

The alternate pipeline is spending several minutes redistributing ports without advancing. I’m returning to the latest pipeline with the corrected manual branch and simpler plane constraints, using the clean shorts result as the baseline.

## 37. Assistant — 2026-10-01T22:08:10.732Z (commentary)

The latest pipeline completes controls and display/audio, but power routing still fails when it loads earlier routes as fixed geometry. I’m adjusting how those routes are preserved so later phases can route around them.

## 38. Assistant — 2026-10-01T22:16:28.412Z (commentary)

The large ground net is still slowing power routing. I’m moving its return connections to the ground pours with additional stitching vias, while the autorouter handles the supply rails. The final connectivity check must confirm that every ground pad is connected.

## 39. Assistant — 2026-10-01T22:20:29.851Z (commentary)

The revised layout passes placement checks, and both signal phases have routed cleanly again. I’ve added fiducials for both assembly sides and corrected the input daemon’s charge-state polarity and physical button mapping.

## 40. User — 2026-10-01T22:27:08.837Z

for the display pick a display with a flexbale cable connctor

## 41. Assistant — 2026-10-01T22:27:11.576Z (commentary)

I’ll switch the display to an LCD with an FPC ribbon connector and put the matching connector on the PCB. I’m also resolving the power-routing phase before running the final shorts and manufacturing checks.

## 42. Assistant — 2026-10-01T22:28:28.474Z (commentary)

I found a 3.5-inch Waveshare ST7796S display with an 18-pin, 0.5 mm ribbon connector and imported a matching JLCPCB connector. I’m verifying its power and pin mapping against the manufacturer’s schematic. The project is now on tscircuit 0.0.2709.

## 43. Assistant — 2026-10-01T22:30:15.120Z (commentary)

The display change needs two layout updates: an 18-pin FPC connector and a separate 3.3 V regulator to match the Pi’s logic levels. I’ve widened the carrier to 100 mm so the selected display fits in landscape above the controls.

## 44. Assistant — 2026-10-01T22:31:45.639Z (commentary)

The revised display netlist has no electrical errors or warnings, and TypeScript checks pass. The connector now includes capacitive-touch wiring and holds the unused display microSD slot deselected. Autorouting is running on the updated board; full-board shorts and connectivity checks will follow.

## 45. Assistant — 2026-10-01T22:34:14.332Z (commentary)

The control phase has completed without routing errors. The display/audio phase is now working through the fine-pitch FPC connections. Fabrication export remains gated on a successful full route, the all-layer shorts check, and an independent KiCad DRC.

## 46. Assistant — 2026-10-01T22:35:10.607Z (commentary)

Both signal phases are advancing through the updated layout. I’ve verified the manufacturer’s 18-pin mapping and documented the ribbon’s pitch, thickness, power rail, and GPIO assignments. The display’s power stays separate from the Pi’s 3.3 V output.

## 47. Assistant — 2026-10-01T22:36:40.901Z (commentary)

Both signal phases have completed without routing errors, and power routing has started. A new local issue needs attention: the disk is full. I’m checking this project’s temporary files for space I can safely recover so validation can continue.

## 48. Assistant — 2026-10-01T22:37:57.343Z (commentary)

I recovered about 1.2 GB by clearing npm’s regenerable download cache, so the build can write its results again. Power routing is still progressing. Next I’ll check the resulting copper across all four layers, including ground connectivity.

## 49. Assistant — 2026-10-01T22:41:14.705Z (commentary)

KiCad is running successfully now. A preflight check on the earlier draft found ground copper inside the fiducials’ solder-mask openings, so I’ve added copper keepouts around them. The updated power phase has reached detailed routing; I’ll rebuild with those keepouts before qualifying the final files.

## 50. Assistant — 2026-10-01T22:45:13.782Z (commentary)

Power routing has reached its cleanup and DRC-repair stages. I’ve also turned the FPC connector toward the left edge for cable access and cleaned up labels that overlapped parts. Those changes will go through a fresh build before the final checks.

## 51. Assistant — 2026-10-01T22:47:24.670Z (commentary)

The FPC display source is committed to GitHub. The routing candidate has passed the detailed routing stages and is finishing power-trace expansion. I’m publishing the updated tscircuit draft while final fabrication validation continues.

## 52. Assistant — 2026-10-01T22:48:29.852Z (commentary)

The power routes solved, but my custom routing wrapper was missing a shutdown method required by tscircuit. That prevented the completed routes from being applied to the board. I’ve fixed the wrapper and am rebuilding with the final connector orientation and copper keepouts.

## 53. Assistant — 2026-10-01T22:50:31.925Z (commentary)

The manufacturing-rule check also caught undersized annular rings in tscircuit’s default testpoint footprint. I’ve replaced them with explicit 1.5 mm pads and 0.6 mm drills. The board is rebuilding with that correction and the routing-wrapper fix.

## 54. Assistant — 2026-10-01T22:54:20.583Z (commentary)

The display now uses an 18-pin, 0.5 mm flexible cable connector. I selected Waveshare’s 3.5-inch capacitive LCD and added its connector and 3.3 V supply in tscircuit. Controls and display/audio routing have passed; power routing and manufacturing checks are still running.

## 55. Assistant — 2026-10-01T22:55:15.101Z (commentary)

The geometry check is clear after correcting how tscircuit exports the fiducial keepouts to KiCad. I’m now checking the fully routed board for shorts and disconnected pads; those checks must pass before I release fabrication files.

## 56. Assistant — 2026-10-01T22:58:25.522Z (commentary)

The final source, pin, netlist and PCB placement checks report zero errors and warnings. Power routing is still progressing. I’m keeping the fabrication export gated on the completed routing, all-layer shorts check and independent connectivity check.

## 57. Assistant — 2026-10-01T23:00:54.185Z (commentary)

I’ve also aligned the Gerbers, drill files and pick-and-place file to the same board origin. This is needed so JLCPCB’s assembly positions line up with the copper. The exported KiCad board will be hashed after DRC to catch any later changes.

## 58. Assistant — 2026-10-01T23:03:28.955Z (commentary)

Power routing has reached its repair stage, where it checks the new tracks against the earlier phases. The plot-origin check also confirms that the exported copper coordinates match the assembly datum.

## 59. Assistant — 2026-10-01T23:07:10.261Z (commentary)

All three autorouting phases have completed with zero routing errors. I’m now running the all-layer Gerber shorts check and KiCad’s independent DRC and connectivity checks on the completed board.

## 60. Assistant — 2026-10-01T23:08:42.766Z (commentary)

The completed-board checks found clearance violations around autorouter vias, including two holes overlapping pads. Fabrication export remains blocked. I’m correcting those routes and checking the ground connections, since tscircuit also reports pads connected through copper pours as missing traces.

## 61. Assistant — 2026-10-01T23:15:53.168Z (commentary)

I’m keeping signal and power routing on the outer layers and reserving both inner layers for ground. This makes every routed via a standard through-via. I also found a charger status connection that needs a manual escape trace before the remaining nets can autoroute.

## 62. Assistant — 2026-10-01T23:23:53.436Z (commentary)

The manual charger escapes have let display/audio routing advance past the earlier failures. I’ve also corrected the display capacitors’ schematic orientation and grouping; the revised source checks are running alongside routing.

## 63. Assistant — 2026-10-01T23:31:02.371Z (commentary)

Controls and display/audio routing now pass. Power routing stopped at the amplifier’s small supply and gain pins. I’m drawing short local connections to its bypass capacitors so the autorouter can finish the wider supply network.

## 64. Assistant — 2026-10-01T23:40:48.168Z (commentary)

I’m continuing with the 18-pin flex-cable display. I’m fixing the amplifier’s local power connections and charger routing, then rerunning the routing phases, shorts checks, and manufacturing checks.

## 65. Assistant — 2026-10-01T23:41:57.091Z (commentary)

The display connector and pin map are in place, including leaving the module’s reserved pin 12 open. I’m also giving the amplifier’s bypass capacitor a short return to a ground via; the remaining checks will verify the actual copper connections.

## 66. Assistant — 2026-10-01T23:42:54.391Z (commentary)

The controls phase and display/audio phase have completed without routing errors. The power phase is running now. After it finishes, I’ll check all copper layers for shorts and verify clearances and connectivity in KiCad before releasing fabrication files.

## 67. Assistant — 2026-10-01T23:45:52.135Z (commentary)

Power routing is getting stuck at the charger’s closely spaced pins, where the wide rail traces need short, narrower escapes. I’m drawing those connections to the nearby capacitors and keeping the longer power branches on the autorouter.

## 68. Assistant — 2026-10-01T23:51:43.136Z (commentary)

I’ve moved the critical bypass capacitors closer to the charger and boost converter and added ground vias beside them. I’m checking that local geometry separately first, so the next autorouting run starts from a verified layout.

## 69. Assistant — 2026-10-01T23:53:00.394Z (commentary)

KiCad’s preflight found no copper or clearance violations in the manual geometry. The full autorouter is now rerunning around those connections. The display remains the Waveshare 480×320 module with an 18-pin, 0.5 mm flex-cable connector.

## 70. Assistant — 2026-10-01T23:57:03.304Z (commentary)

The local feedback divider now also passes KiCad’s geometry checks. I’ve connected it manually to keep its sense traces short. The autorouter is rerunning the display/audio phase around the updated power layout.

## 71. Assistant — 2026-10-02T00:00:48.460Z (commentary)

The router diagnostic identified the charger timer connection as the current blockage: the router’s conservative via margin cannot fit beside a ground via. I’m adding a manual trace that meets the board’s declared clearance rules and checking it independently.

## 72. Assistant — 2026-10-02T00:04:02.081Z (commentary)

The new timer and boost-enable traces pass KiCad’s geometry check. The controls phase has progressed through routing and is checking clearances. I’m also checking that the Gerbers, drill files, and assembly coordinates use the same origin.

## 73. Assistant — 2026-10-02T00:06:28.516Z (commentary)

The display/audio phase has finished routing and is checking clearances. The file-origin preflight also passed: all 217 SMT pad centers and 86 current drill features match the tscircuit design, including the USB connector slots.

## 74. Assistant — 2026-10-02T00:10:00.890Z (commentary)

Both signal phases passed. Power routing stopped at a 5 V branch. I’m locating that connection so I can add only the short escape it needs and preserve autorouting for the wider supply network.

## 75. Assistant — 2026-10-02T00:18:34.981Z (commentary)

That branch connects the amplifier’s two bypass capacitors. Its new 0.6 mm manual feed passes the geometry preflight, and both signal phases have passed again. The power phase is now running with that connection completed.

## 76. Assistant — 2026-10-02T00:21:36.224Z (commentary)

I’ve added battery and speaker polarity markings. The release checks now compare actual drill positions, diameters, and USB slot directions with the tscircuit design. The next routing run includes a narrow feed for the battery-alert pull-up, crossing the I2C clock on the opposite outer layer.

## 77. Assistant — 2026-10-02T00:22:48.347Z (commentary)

The preflight caught a crossing before the new trace reached its via. I’ve moved the via so the crossing happens entirely on the bottom layer. I’m checking that correction before restarting the full route.

## 78. Assistant — 2026-10-02T00:25:38.300Z (commentary)

The corrected crossing passes the geometry check, and both signal phases have passed again. Power routing is still stopping on a 3.3 V branch. I’m checking its updated endpoints before making another change.

## 79. Assistant — 2026-10-02T00:28:33.571Z (commentary)

The remaining 3.3 V blockage is at the button controller’s supply pin. I’ve moved its bypass capacitor closer and connected that local path manually. I also found a newer tscircuit release, 0.0.2711, and will update before the next full build.

## 80. Assistant — 2026-10-02T00:32:21.736Z (commentary)

The display now uses an 18-pin FPC connector for its flexible cable. The tscircuit update and TypeScript checks pass; I’m checking the revised layout before running the autorouter again.

## 81. Assistant — 2026-10-02T00:33:13.192Z (commentary)

The revised component placement and manual traces have no physical DRC violations. The full three-phase route is running now; its result still needs shorts and connectivity checks before I can release ordering files.

## 82. Assistant — 2026-10-02T00:34:21.271Z (commentary)

The controls and display/audio routing phases have completed without router errors. The power phase is now running around those traces and the manual connections.

## 83. Assistant — 2026-10-02T00:35:04.860Z (commentary)

All power connections have been routed, and the autorouter is repairing clearances. I’m also rerunning the source, pin and netlist checks against this revision.

## 84. Assistant — 2026-10-02T00:36:05.630Z (commentary)

All three autorouting phases completed without router errors. I’m now checking the resulting copper for shorts, clearance violations and unconnected pads—the checks that determine whether the board can be released for fabrication.

## 85. Assistant — 2026-10-02T00:37:36.601Z (commentary)

The final checks found remaining clearance violations and four disconnected ground regions. I’m correcting those and a supply-feed length check that was incorrectly applied to the controller’s bypass capacitor.

## 86. Assistant — 2026-10-02T00:45:26.625Z (commentary)

The previous route passed the all-layer shorts check, but it still failed clearance and ground-connectivity checks. I’ve added ground vias and moved the USB and battery feeds onto manual paths. The autorouter will continue handling the remaining connections around them.

## 87. Assistant — 2026-10-02T00:47:20.009Z (commentary)

The revised manual paths pass the geometry check, and JLCPCB placement rotations are verified for all 48 assembly parts. The carrier now takes 3.3 V from Pi pin 1 only, removing an unnecessary connection across the GPIO header.

## 88. Assistant — 2026-10-02T00:50:57.938Z (commentary)

I also found a width-format issue: the native checker reads some autorouter width changes more conservatively than the KiCad export. Making those transitions explicit removed five reports in a diagnostic copy while preserving the exported copper widths. The final board will still need fresh checks.

## 89. Assistant — 2026-10-02T00:54:39.052Z (commentary)

The next routing pass failed at the amplifier’s I2S frame-clock connection. I’ve drawn that path manually around the GPIO holes and am checking its geometry before rerunning the remaining routes.

## 90. Assistant — 2026-10-02T00:57:19.249Z (commentary)

The controls phase has completed again with the new manual paths in place. I’ve also added an export check that compares every KiCad track’s position, width and layer with the tscircuit model.

## 91. Assistant — 2026-10-02T01:02:58.022Z (commentary)

The power route is blocked at the fuel gauge’s tiny supply pins. I’m adding narrow local bypass traces and a separate low-current feed from the battery connector so the wide battery rail can clear that area.

## 92. Assistant — 2026-10-02T01:08:46.585Z (commentary)

I’m continuing with the 18-pin flexible-cable display. The latest routing run includes the battery-monitor fixes; I’ll check its copper clearance and shorts before generating fabrication files.

## 93. Assistant — 2026-10-02T01:09:25.805Z (commentary)

The controls and display/audio phases routed successfully. The power phase got stuck joining the LCD supply to its unused microSD select pin. I’m adding manual power connections there and keeping the autorouter for the remaining nets.

## 94. Assistant — 2026-10-02T01:11:54.086Z (commentary)

The new LCD power traces pass the independent geometry check, and the source, pin, netlist and schematic checks pass. The full autorouter is running again. The selected 480×320 SPI display also has a refresh-rate limit, which I’ve documented for game testing.

## 95. Assistant — 2026-10-02T01:13:39.083Z (commentary)

All six source and layout checks pass with zero reported errors or warnings. The completed board still needs the full-route clearance check, all-layer shorts check and independent KiCad connectivity check before it can pass the fabrication gates.

## 96. Assistant — 2026-10-02T01:14:35.557Z (commentary)

The controls and display/audio phases are complete. The power phase is now routing around their copper, including the manual FPC supply connections.

## 97. Assistant — 2026-10-02T01:16:19.076Z (commentary)

The power router hit congestion on the feed to the LCD regulator. I’m drawing that low-current branch manually and moving power routing to the first phase, so the wider supply traces get space before the signal traces.

## 98. Assistant — 2026-10-02T01:18:19.746Z (commentary)

The manual LCD feed passes KiCad’s geometry check. With power routing moved first, the autorouter has reached the final stage of the supply routes; controls and display/audio will route around them next.

## 99. Assistant — 2026-10-02T01:20:36.596Z (commentary)

Power routing completed successfully. The next phase got stuck on the charger’s power-good signal near the GPIO header. I’m drawing that narrow status branch manually, then checking its geometry before rerunning the remaining phases.

## 100. Assistant — 2026-10-02T01:22:07.700Z (commentary)

I found an electrical issue in the button mapping: Microchip’s updated datasheet lists GPA7 and GPB7 as output-only. I’m moving the Y button to GPB3 and updating the Linux input mapping. [Current Microchip datasheet](https://ww1.microchip.com/downloads/aemDocuments/documents/APID/ProductDocuments/DataSheets/MCP23017-Data-Sheet-DS20001952.pdf)

## 101. Assistant — 2026-10-02T01:24:48.682Z (commentary)

The corrected mapping passes TypeScript and a software check for all eleven buttons, including simultaneous presses and ignoring the output-only pins. I’m rebuilding the board with that mapping and the FPC display connections.

## 102. Assistant — 2026-10-02T01:25:55.894Z (commentary)

J_LCD is an 18-pin, 0.5 mm bottom-contact connector with a dedicated 3.3 V supply. The display’s reserved pins stay open, and its unused microSD select pin is held inactive. The routing run is still working through power-clearance repairs.

## 103. Assistant — 2026-10-02T01:27:19.471Z (commentary)

The power-clearance repair stage has finished, and the router is now widening the supply traces. After all three phases finish, I’ll use both tscircuit and KiCad to check the complete copper rather than relying on router success alone.

## 104. Assistant — 2026-10-02T01:28:45.117Z (commentary)

Power routed, but its placement blocked the host-to-button-controller I2C data connection. I’m adjusting the phase order to controls/I2C, then power, then display/audio. That should reserve space for both the sensitive bus and the wider supply traces.

## 105. Assistant — 2026-10-02T01:30:23.328Z (commentary)

The corrected controls and I2C phase completed with zero routing errors. Power is now routing around those connections; display and audio remain after that.

## 106. Assistant — 2026-10-02T01:32:00.118Z (commentary)

The latest blockage is a low-current 3.3 V branch between the controller’s bypass capacitors. I’m turning the bulk capacitor so its power pad faces the feed and reducing that branch to 0.2 mm, which is sufficient for the controller load.

## 107. Assistant — 2026-10-02T01:33:27.675Z (commentary)

The revised controller supply layout passes the independent geometry check. The full build is running again. I’m saving the current source and validation tools to GitHub, with the fabrication status still marked “do not order” until the complete route passes.

## 108. Assistant — 2026-10-02T01:35:03.457Z (commentary)

GitHub now has the revised source, including the corrected button mapping and fabrication checks. The matching tscircuit validation draft is uploading. In the current build, controls have routed successfully and power routing is underway.

## 109. Assistant — 2026-10-02T01:37:08.641Z (commentary)

The router still couldn’t join the controller’s two bypass capacitors, so I’ve drawn that short connection manually. The autorouter will handle the longer 3.3 V feed and the remaining rails. This also gives the controller a direct local bypass path.

## 110. Assistant — 2026-10-02T01:38:45.767Z (commentary)

The manual controller capacitor link passes KiCad’s geometry check. The current build has reached cleanup of the control routes; the complete board still needs the power and display/audio phases and final copper checks.

## 111. Assistant — 2026-10-02T01:40:01.204Z (commentary)

Controls have completed, and power has passed the path-finding stage that blocked the earlier runs. The router is now repairing supply clearances before starting display/audio.

## 112. Assistant — 2026-10-02T01:41:29.330Z (commentary)

Controls and power have both completed with zero routing errors. The final display/audio phase is now running around their copper. Once it finishes, I can check the full board for shorts, clearances and disconnected pads.

## 113. Assistant — 2026-10-02T01:44:24.878Z (commentary)

Display/audio routing stopped on a conflict in an earlier 5 V route. The router had widened a low-current boost-feedback feed as part of the main supply net. I’m replacing the feedback and enable feeds with short manual connections to the nearby capacitors.

## 114. Assistant — 2026-10-02T01:47:16.047Z (commentary)

The geometry check caught a crossing between the new sense feed and the feedback trace. I’m moving the sense feed across the bottom copper with two through-vias, then checking it again before rerouting.

## 115. Assistant — 2026-10-02T01:48:49.296Z (commentary)

The two-via sense bridge passes the geometry check, and TypeScript passes too. I’m rerunning the full board with those local feeds removed from the wide-load autorouting targets.

## 116. Assistant — 2026-10-02T01:51:07.220Z (commentary)

The build found that the capacitor length limits were also being applied to the sense and enable feeds. I’ve given those separate feeds explicit limits while keeping the regulator’s local bypass limits short. I’m rechecking the manual copper at the requested widths before routing again.

## 117. Assistant — 2026-10-02T01:52:20.207Z (commentary)

The manual copper now passes KiCad’s geometry check at the requested widths, including the 0.8 mm battery feed and wider supply connections. The full phased build is running again.

## 118. Assistant — 2026-10-02T01:53:37.541Z (commentary)

Controls have completed again, and power routing is underway. I also rechecked npm: tscircuit 0.0.2711 and capacity-autorouter 0.0.951 are still the latest published versions, and the project pins both.

## 119. Assistant — 2026-10-02T01:54:58.321Z (commentary)

Power has completed with zero routing errors. Display/audio routing is now running with the feedback and enable feeds drawn manually. If it completes, I’ll run the all-layer shorts check and KiCad connectivity check on the full board.

## 120. Assistant — 2026-10-02T01:57:13.143Z (commentary)

The final phase now reaches the audio clock connection, where BCLK is blocked near the amplifier pads. I’m drawing BCLK and audio data alongside each other, with their layer changes placed away from the GPIO status trace. Other display/audio connections will remain autorouted.

## 121. Assistant — 2026-10-02T02:00:24.599Z (commentary)

The check caught a mistake in my first audio-data escape: I used the wrong location for the DIN pad. I’m moving that trace below the amplifier and farther from the BCLK via, then checking the routes again.

## 122. Assistant — 2026-10-02T02:01:54.714Z (commentary)

The corrected I2S routes pass KiCad’s geometry check. I’m checking the manual copper against tscircuit’s routing rules as well, then rerunning the complete board.

## 123. Assistant — 2026-10-02T02:04:05.293Z (commentary)

The control phase completed with the new I2S routes in place. Power routing is next, followed by the remaining display/audio connections. The manual copper passes both native and KiCad geometry checks; the full board remains unqualified until the final checks pass.

## 124. Assistant — 2026-10-02T02:07:01.931Z (commentary)

Power completed successfully, and the remaining display/audio connections are in path-finding. The new I2S routes have also passed both geometry checks. I’ll run the complete-board shorts and connectivity checks when this phase finishes.

## 125. Assistant — 2026-10-02T02:09:21.331Z (commentary)

The remaining routing failure is the battery thermistor connection. I’m drawing it around the charger capacitors and across the other copper side, so it clears the wide battery feed while keeping the NTC connected to the charger’s temperature input.

## 126. Assistant — 2026-10-02T02:13:58.815Z (commentary)

I’m continuing with the 18-pin flex cable display connector. I’m fixing the thermistor route’s clearance, then rerunning the phased autorouter and fabrication checks.

## 127. Assistant — 2026-10-02T02:14:50.262Z (commentary)

The manual traces now pass both native geometry checks and KiCad clearance checks. The full build is running through controls, power, then display/audio routing; afterward I’ll check shorts and electrical continuity.

## 128. Assistant — 2026-10-02T02:15:44.788Z (commentary)

TypeScript, source, pin and netlist checks have passed. The final export will also verify that the Gerbers, drill files and assembly placements agree with the tscircuit board’s coordinates.

## 129. Assistant — 2026-10-02T02:16:20.851Z (commentary)

The controls phase completed with zero routing errors, and placement checks also passed. The power phase is now routing around those connections.

## 130. Assistant — 2026-10-02T02:17:37.514Z (commentary)

The power phase passed with zero routing errors. JLCPCB rotations are verified for all 48 SMD components, and the assembly files now exclude the headers that will be fitted by hand.

## 131. Assistant — 2026-10-02T02:18:39.821Z (commentary)

The remaining routes are in the display/audio phase. The selected screen supports the flex cable connection, though its SPI interface limits full-frame refresh speed; I’ve documented that limit for hardware bring-up.

## 132. Assistant — 2026-10-02T02:20:32.260Z (commentary)

The autorouter could not complete the LCD reset connection in the crowded connector area. I’m adding a manual route across the two outer layers and will rerun the full build.

## 133. Assistant — 2026-10-02T02:23:35.460Z (commentary)

The LCD reset route now uses a short layer crossing near the GPIO header to clear the existing signal traces. I’m checking the generated copper before another full routing pass.

## 134. Assistant — 2026-10-02T02:25:00.863Z (commentary)

The manual LCD reset route passed both geometry checks. The full three-phase rebuild is running again; I’ll qualify the board only after the shorts and continuity checks pass too.

## 135. Assistant — 2026-10-02T02:26:17.855Z (commentary)

The controls phase passed again. I also rechecked npm: tscircuit 0.0.2711 and capacity-autorouter 0.0.951 remain the latest versions.

## 136. Assistant — 2026-10-02T02:27:49.770Z (commentary)

I’ve saved and pushed the manual routing improvements to GitHub. The current board is still marked “do not order” while the full routing and fabrication checks are in progress.

## 137. Assistant — 2026-10-02T02:29:20.411Z (commentary)

The power phase is spending longer on clearance repair around the new route. I’m letting the solver finish before deciding whether the layout needs another adjustment.

## 138. Assistant — 2026-10-02T02:30:27.681Z (commentary)

The power phase completed with zero routing errors. The display/audio phase is now running around the completed power and control routes.

## 139. Assistant — 2026-10-02T02:32:54.665Z (commentary)

The remaining routing failure is at the amplifier enable pins. I also found that the solver narrowed part of the Pi’s 5 V feed to 0.2 mm, so I’m adding a wider manual path for that load connection.

## 140. Assistant — 2026-10-02T02:36:02.581Z (commentary)

The 0.8 mm Pi supply path and amplifier enable routes pass both geometry checkers. The next full autorouting pass is running.

## 141. Assistant — 2026-10-02T02:38:13.757Z (commentary)

The updated controls phase passed, along with source, pin and netlist checks. Power routing is now running with the Pi’s load feed fixed at 0.8 mm.

## 142. Assistant — 2026-10-02T02:39:04.724Z (commentary)

The new routes pass geometry checks, but the full build has exposed a blocked 3.3 V branch. I’m identifying that connection and checking solder-mask clearances before the next pass.

## 143. Assistant — 2026-10-02T02:42:23.861Z (commentary)

JLCPCB’s current rules allow pad-sized solder-mask openings. I’ve kept those openings, raised visible labels to 1 mm, and tightened the drill-spacing check to 0.45 mm. I’m now checking the manual 3.3 V branch.

## 144. Assistant — 2026-10-02T02:44:04.935Z (commentary)

I found an export error in the new supply path: a redundant via was emitted with only one copper layer, so KiCad could not read the board. I’m removing it and making the check script discard old reports before each run. The previous KiCad report did not validate that new path.

## 145. Assistant — 2026-10-02T02:46:06.779Z (commentary)

I’ve adjusted the 3.3 V route to cross the charger and 5 V traces on separate layers. The fresh geometry checks are running now.

## 146. Assistant — 2026-10-02T02:47:26.675Z (commentary)

The corrected manual copper now passes fresh native and KiCad geometry checks, including the tighter drill-spacing rule. The full board is rebuilding; the remaining 43 open connections in the manual-only check are autorouter work.

## 147. Assistant — 2026-10-02T02:49:39.176Z (commentary)

The manual copper passes, but the router’s connection guard stopped because it wasn’t expecting the new manual 3.3 V branch. I’m updating that guard and rerunning the build.

## 148. Assistant — 2026-10-02T02:51:20.332Z (commentary)

PCB placement checks passed with zero errors or warnings, and schematic placement passed too. The connection guard is updated; the three-phase routing rebuild is still running.

## 149. Assistant — 2026-10-02T02:52:45.892Z (commentary)

Control routing is in its final clearance cleanup. The fabrication exporter will stay blocked until the full build, shorts check and KiCad continuity check all pass.

## 150. Assistant — 2026-10-02T02:56:07.283Z (commentary)

The router is blocked on the 3.3 V feed to the charger-status pull-ups. I’m connecting those pull-ups directly to Pi pin 1 with a short manual route, while leaving the other 3.3 V branches for the autorouter.

## 151. Assistant — 2026-10-02T02:57:46.842Z (commentary)

The status pull-up routes passed both geometry checks, and the connection guard passed its precheck. I’m running the complete board build again with those connections fixed.

## 152. Assistant — 2026-10-02T02:58:57.982Z (commentary)

Both repositories now have the routing improvements. The tscircuit upload is labelled `1.0.0-power-routing-draft` and remains marked “do not order” while full validation continues.

## 153. Assistant — 2026-10-02T03:00:41.287Z (commentary)

Controls passed with zero routing errors. The power phase is routing the remaining rail connections, with the Pi supply and status pull-up paths already drawn manually.

## 154. Assistant — 2026-10-02T03:02:19.677Z (commentary)

Controls and power both passed. The remaining failure is the MCP23017 reset pull-up connection. I’m drawing that local trace manually and will keep the remaining display/audio routes on the autorouter.

## 155. Assistant — 2026-10-02T03:04:06.197Z (commentary)

The controller reset trace passed both geometry checkers. The next full build is running; after it completes, I’ll run the all-layer shorts and KiCad checks on that exact board output.

## 156. Assistant — 2026-10-02T03:07:48.818Z (commentary)

The controls and power phases have completed without routing errors. The display uses an 18-pin FPC connector for its flexible cable; I’m checking the remaining display and audio routes before running the full shorts and fabrication checks.

## 157. Assistant — 2026-10-02T03:08:49.743Z (commentary)

The router stopped at the amplifier enable signal. I’m adding a manual trace for that connection, then rerunning routing and both geometry checkers.

## 158. Assistant — 2026-10-02T03:10:54.628Z (commentary)

The amplifier enable trace passes tscircuit and KiCad geometry checks. The full three-phase build is running again. I’m keeping the fabrication export blocked until the complete board passes routing, shorts and connectivity checks.

## 159. Assistant — 2026-10-02T03:11:52.030Z (commentary)

The controls phase is now in its clearance-repair stage. I’m also refreshing the source, pin, netlist and placement checks for the latest traces.

## 160. Assistant — 2026-10-02T03:13:23.291Z (commentary)

Source, pin, netlist, schematic placement and PCB placement checks have passed. The controls routing phase has also completed without errors; power routing is next.

## 161. Assistant — 2026-10-02T03:14:42.640Z (commentary)

All six pre-routing checks have completed successfully. Power routing is still working through the crowded area near the Pi header; the manual amplifier enable trace has already passed both geometry checks.

## 162. Assistant — 2026-10-02T03:15:39.362Z (commentary)

Power routing has completed without errors. The display and audio phase is now running; the main Pi supply remains on the manually drawn 0.8 mm traces.

## 163. Assistant — 2026-10-02T03:17:38.271Z (commentary)

The next routing failure is the LCD chip-select connection at the fine-pitch FPC connector. I’m drawing its escape and checking clearance around the neighboring reset and SD-select traces.

## 164. Assistant — 2026-10-02T03:18:57.658Z (commentary)

The checks found two clearance problems in the FPC escape. I moved the nearby SD-select via and adjusted the LCD chip-select via, and I’m checking the revised geometry before another full build.

## 165. Assistant — 2026-10-02T03:20:27.226Z (commentary)

The revised LCD chip-select escape passes both geometry checkers. I’m rerunning all three routing phases with it in place.

## 166. Assistant — 2026-10-02T03:21:58.134Z (commentary)

The full build is progressing through controls again with the new FPC escape. The display connector and its neighboring supply traces now pass geometry checks, but the complete board is still unqualified.

## 167. Assistant — 2026-10-02T03:22:55.132Z (commentary)

The manual-copper preflight also passes the all-layer Gerber shorts check. The full autoroute is still running; I’ll repeat that check on the completed board.

## 168. Assistant — 2026-10-02T03:24:12.294Z (commentary)

Controls routing has passed again, and power routing is underway. The manual-copper preflight is clear of geometry errors and shorts; the completed autoroute still needs its own validation.

## 169. Assistant — 2026-10-02T03:25:41.005Z (commentary)

Power routing is in its final cleanup stage. Once display and audio routing finishes, I’ll check the complete output for shorts and verify every connection in KiCad.

## 170. Assistant — 2026-10-02T03:27:06.751Z (commentary)

Display and audio routing has advanced past the connection that failed in the previous build. The router is working through the remaining dense routes near the connector and GPIO header.

## 171. Assistant — 2026-10-02T03:28:32.118Z (commentary)

The final routing phase is still searching for a valid solution. I’m leaving it running while I refresh the source and pin checks after the FPC changes.

## 172. Assistant — 2026-10-02T03:29:47.021Z (commentary)

The router has found the remaining paths and is now repairing clearances. The refreshed source, pin, netlist and TypeScript checks also pass.

## 173. Assistant — 2026-10-02T03:30:53.305Z (commentary)

All three autorouting phases have completed without routing errors. I’m now checking the complete board output for native PCB errors, all-layer shorts and independent KiCad connectivity and clearance issues.

## 174. Assistant — 2026-10-02T03:32:07.333Z (commentary)

The complete route has 19 native PCB issues, including two traces crossing unrelated header pads. I’m checking the shorts and KiCad results to locate the faults, then I’ll correct the affected routes before exporting fabrication files.

## 175. Assistant — 2026-10-02T03:34:44.436Z (commentary)

The shorts check confirms faults in the widened audio supply trace and the boost input feed. I’m replacing those power routes with manual copper while retaining phased autorouting for the other connections.

## 176. Assistant — 2026-10-02T03:38:28.066Z (commentary)

The manual power feeds are drawn. I’m checking that their vias stay outside the component pads and that the wide traces clear the battery, USB and GPIO connections.

## 177. Assistant — 2026-10-02T03:41:34.797Z (commentary)

The first power-route preflight found crossings with existing signal traces. I’ve adjusted those paths around the signal bridges and fiducial keepouts, and I’m checking the revised copper now.

## 178. Assistant — 2026-10-02T03:42:41.018Z (commentary)

The revised power routes are down to two clearance faults in the preflight, both near ground vias. I’ve moved those segments and am checking them again before the next full autoroute.

## 179. Assistant — 2026-10-02T03:43:46.696Z (commentary)

The manual power copper now passes both geometry checkers, and KiCad shows no open 3.3 V or charger-output connections. I’m also making earlier-phase routes fixed obstacles so later phases cannot move them during repair.

## 180. Assistant — 2026-10-02T03:45:39.740Z (commentary)

The revised manual copper passes the all-layer shorts check as well as both geometry checkers. The full build is now running with earlier-phase routes preserved as fixed copper.

## 181. Assistant — 2026-10-02T03:47:14.129Z (commentary)

Controls routing is in its clearance-repair stage. The manual power feeds have passed preflight; the remaining validation is whether the autorouted controls and display signals also pass the final checks.

## 182. Assistant — 2026-10-02T03:48:29.405Z (commentary)

Controls passed, but the power phase stopped at a connection guard: it counted a new via as another capacitor or resistor terminal. I’ve corrected that classification and verified the updated guard against the failed build’s input.

## 183. Assistant — 2026-10-02T03:49:41.105Z (commentary)

The new full build is underway. I’m saving the checked manual power changes to GitHub as work in progress; the repository will remain marked “do not order” until the complete-board checks pass.

## 184. Assistant — 2026-10-02T03:51:19.307Z (commentary)

The source changes are now saved to [GitHub](https://github.com/Abse2001/g350-linux-handheld) and published as a new [tscircuit draft](https://tscircuit.com/abse/g350-linux-handheld). Both remain marked as work in progress while the full-board routing and fabrication checks continue.

## 185. Assistant — 2026-10-02T03:52:43.324Z (commentary)

Controls routing has found its paths and is repairing clearances. The next phases will use those completed traces as fixed obstacles, so their repair steps cannot relocate them.

## 186. Assistant — 2026-10-02T03:54:27.782Z (commentary)

Controls routing has passed, and the corrected guard has allowed power routing to proceed. After the final phase, I’ll check that the complete board has cleared the shorts and clearance faults found earlier.

## 187. Assistant — 2026-10-02T03:56:03.579Z (commentary)

Power routing has passed. Display and audio routing is now running around the fixed control and power traces; the complete-board checks will follow when it finishes.

## 188. Assistant — 2026-10-02T03:57:03.562Z (commentary)

The final phase is still finding paths through the fixed copper. I’m checking how the router represents diagonal traces to make sure those obstacles protect the physical copper correctly.

## 189. Assistant — 2026-10-02T03:57:50.478Z (commentary)

The fixed diagonal traces use the router’s own rotated-obstacle model. Display and audio routing has found its paths and is now repairing clearances.

## 190. Assistant — 2026-10-02T03:59:08.381Z (commentary)

All three phases have completed again without routing errors. I’m waiting for the board export to finish, then I’ll rerun the native, shorts and KiCad checks on this exact output.

## 191. Assistant — 2026-10-02T04:00:21.938Z (commentary)

The build no longer reports the power-trace shorts or the supply-length error. It still has 17 native clearance issues around signal traces and vias. I’m running shorts and KiCad checks on this output to identify the remaining corrections.

## 192. Assistant — 2026-10-02T04:02:19.095Z (commentary)

KiCad now reports zero open connections and only clearance violations. I’m checking whether the installed router’s clearance-repair solver can correct the remaining signal routes before adding more manual paths.

## 193. Assistant — 2026-10-02T04:06:33.828Z (commentary)

The remaining failures are clustered around the display signals and a few status lines. I’m separating those routes with manual paths, then rerunning the autorouter and both sets of clearance checks.

## 194. Assistant — 2026-10-02T04:07:26.889Z (commentary)

The display uses an 18-pin, 0.5 mm flexible ribbon connector. The manual power routes now pass clearance and shorts checks; I’m still resolving the complete board’s signal clearances before producing ordering files.

## 195. Assistant — 2026-10-02T04:08:49.373Z (commentary)

The router’s repair pass still leaves violations in the independent checks. I’m addressing the affected nets directly and keeping the release blocked until the full board passes.

## 196. Assistant — 2026-10-02T04:12:18.789Z (commentary)

I’m moving the crowded SPI and display-control routes onto an inner signal layer. Standard through-vias will connect them to the ribbon connector, while the other inner layer provides a continuous ground plane.

## 197. Assistant — 2026-10-02T04:14:22.987Z (commentary)

The new display paths use four short ribbon escapes and standard through-vias. I’m checking their pad clearance and layer transitions before running the complete routing build again.

## 198. Assistant — 2026-10-02T04:18:21.148Z (commentary)

The current tscircuit release creates inner-layer access ports incorrectly for through-vias. I’m adding a small compatibility fix for the display vias, then checking that the exported board still uses ordinary full-depth holes.

## 199. Assistant — 2026-10-02T04:20:31.585Z (commentary)

The through-vias now export correctly on all four layers. I’ve adjusted two crossings with existing copper, and I’m checking the revised manual layout before the next complete autorouting run.

## 200. Assistant — 2026-10-02T04:21:12.589Z (commentary)

The revised manual layout passes native clearance checks and independent KiCad geometry checks. The full three-phase autorouter is running now; its output still needs fresh connectivity, shorts, and fabrication checks.

## 201. Assistant — 2026-10-02T04:22:30.007Z (commentary)

The manual layout passes the all-layer Gerber shorts check too. The refreshed source, pin, schematic, and placement checks are clean. The complete autorouter is still processing the control routes.

## 202. Assistant — 2026-10-02T04:24:04.842Z (commentary)

The display-source update is saved in GitHub and published as a labelled draft in tscircuit. The full-board qualification is still running; it has not produced approved manufacturing files yet.

## 203. Assistant — 2026-10-02T04:26:24.848Z (commentary)

A newer release appeared during the checks: tscircuit 0.0.2715 and tsci 0.1.2220. I’ll update to those versions after this diagnostic run, then rebuild and revalidate the board.

## 204. Assistant — 2026-10-02T04:32:10.226Z (commentary)

The diagnostic run could not finish the last routing phase. I’m completing the remaining ribbon escapes and a few crowded control paths manually so the autorouter has fewer conflicts to resolve.

## 205. Assistant — 2026-10-02T04:36:00.957Z (commentary)

The display now uses an 18-pin flexible cable connector. I’m checking the latest manual routes before rerunning all three autorouting phases; the board still needs to pass the fabrication checks.

## 206. Assistant — 2026-10-02T04:37:19.402Z (commentary)

The checks caught crossings and tight clearances in the new manual routes. I’m correcting those now, including the display’s backlight escape and the button paths near the power rail.

## 207. Assistant — 2026-10-02T04:39:47.040Z (commentary)

The repaired display, I²C clock and button paths now pass the native clearance checks and the all-layer shorts check. I’m also drawing the charger-status path manually to resolve a clearance problem found in the previous autorouted candidate.

## 208. Assistant — 2026-10-02T04:41:39.023Z (commentary)

KiCad found two additional issues: the Select trace touched an unused switch pad, and two vias served only as junctions on one copper layer. I’ve rerouted Select and removed those unnecessary vias. The source, pin, netlist and placement checks have passed.

## 209. Assistant — 2026-10-02T04:44:38.188Z (commentary)

The charger area is tight: its status signal needs to clear both the battery feed and the system power feed. I’m adjusting that local escape and the nearby enable connection, then checking the resulting copper again.

## 210. Assistant — 2026-10-02T04:46:16.669Z (commentary)

The manual layout now has zero KiCad geometry violations and passes the all-layer shorts check. I’ve started the full three-phase autoroute with the latest tscircuit version. The remaining connections will be checked once routing finishes.

## 211. Assistant — 2026-10-02T04:47:52.214Z (commentary)

The autorouter is working through the controls phase. The final manual preflight is clean in both tscircuit and KiCad, with no shorts detected; the complete board remains under validation.

## 212. Assistant — 2026-10-02T04:49:26.759Z (commentary)

The controls phase has reached detailed routing. The manual display connections are already drawn, and the autorouter is placing the remaining button and bus connections around them.

## 213. Assistant — 2026-10-02T04:50:37.598Z (commentary)

Source, pin, netlist, placement and TypeScript checks are all clear. Detailed routing is taking longer on this candidate; once it finishes, I’ll check the complete copper layout for shorts, clearances and connectivity.

## 214. Assistant — 2026-10-02T04:52:30.703Z (commentary)

I’m checking whether projecting the fixed inner traces onto the outer routing layers is constraining the autorouter too much. This protects against misplaced through-vias, but may be making the remaining control routes harder to complete.

## 215. Assistant — 2026-10-02T04:53:46.341Z (commentary)

I found that the latest tscircuit core supports standard full-depth vias when autorouting across all four layers. I’m switching to that approach so outer-layer traces can cross inner-layer signals while the router checks vias against the actual copper.

## 216. Assistant — 2026-10-02T04:55:35.823Z (commentary)

Four-layer routing is progressing. I also added an export check that requires every KiCad via to retain the circuit’s standard through-via span, drill size, diameter and position.

## 217. Assistant — 2026-10-02T04:58:17.166Z (commentary)

The current pass is still building routing corridors. I’m checking the obstacle geometry for avoidable complexity while the build runs, so the router spends less time processing duplicate copper shapes.

## 218. Assistant — 2026-10-02T05:00:10.626Z (commentary)

The routing input contains thousands of small rectangles representing the manual traces. I’m checking whether those repeated shapes are slowing corridor generation, and whether they can be simplified while still covering all existing copper.

## 219. Assistant — 2026-10-02T05:02:11.947Z (commentary)

I verified the simplification against the real routing input: it reduces 3,520 obstacles to 2,173 while fully covering every original obstacle on the same net and layer. Pads, holes, vias and fine-pitch escapes stay unchanged. I’m rerunning the phased autorouter with it.

## 220. Assistant — 2026-10-02T05:03:42.603Z (commentary)

The simplified input is helping: the router has reached corridor point generation sooner than the previous pass. Final acceptance still requires a completed three-phase build and clean shorts, clearance and connectivity checks.

## 221. Assistant — 2026-10-02T05:06:26.264Z (commentary)

The controls phase completed and the power phase has started. I’m checking the completed control routes now while the autorouter continues.

## 222. Assistant — 2026-10-02T05:08:23.755Z (commentary)

The power phase completed and the final display/audio phase has started. An early check found one pair of control vias closer than the 0.2 mm target; I’ll correct that before releasing fabrication files.

## 223. Assistant — 2026-10-02T05:11:38.032Z (commentary)

The remaining phases are continuing. The control issue is localized to the Down and Left inputs near the button controller, so I can fix that escape without moving the connector or changing the button mapping.

## 224. Assistant — 2026-10-02T05:14:21.307Z (commentary)

All three autorouting phases finished. Final checks found five clearance issues, including the charger’s current-setting route and one USB CC via. The KiCad export also duplicated some inner-layer transitions, so I’m correcting the export to preserve their declared full-depth vias.

## 225. Assistant — 2026-10-02T05:17:08.630Z (commentary)

I’ve added manual escapes for the Left input, charger current setting and USB CC2 connection. The rest of the Left-button run will still use the autorouter. I’m checking these changes before the next complete build.

## 226. Assistant — 2026-10-02T05:19:34.649Z (commentary)

The new manual traces pass the native geometry and all-layer shorts checks. KiCad reports one expected unconnected fanout via, which the Left-button autoroute must connect. The next full build is running.

## 227. Assistant — 2026-10-02T05:23:12.506Z (commentary)

The controls phase has finished routing. I’m checking its copper clearances while the power and display phases continue; the finished board will also need to pass shorts and KiCad checks.

## 228. Assistant — 2026-10-02T05:23:51.824Z (commentary)

The clearance check found the Left-button autoroute crossing the manual Up-button trace. I’m moving the Left fanout to the other inner layer and rerunning the phases.

## 229. Assistant — 2026-10-02T05:25:11.725Z (commentary)

The selected display uses an 18-pin, 0.5 mm flexible cable connector. Its JLCPCB footprint, pinout and separate 3.3 V supply are in the design. The corrected routing run is starting; fabrication files remain blocked until it passes validation.

## 230. Assistant — 2026-10-02T05:26:53.242Z (commentary)

The controls phase is still working through the clearances around the button controller. The toolchain is updated and TypeScript passes. I’ll check the routed copper independently before generating the production package.

## 231. Assistant — 2026-10-02T05:27:59.810Z (commentary)

I’m refreshing the source, pin, netlist, schematic and placement checks in an isolated copy while the main board routes. That keeps those checks from overwriting the routed build.

## 232. Assistant — 2026-10-02T05:29:39.650Z (commentary)

All six source and placement checks passed with zero errors. The autorouter is still working on the controls phase. Copper clearances and connectivity are the remaining gates for the fabrication package.

## 233. Assistant — 2026-10-02T05:30:41.106Z (commentary)

The corrected controls phase has finished. I’m checking its copper now. I also added a separate manual-assembly BOM for the Pi, display, cables, headers and mounting hardware.

## 234. Assistant — 2026-10-02T05:31:53.908Z (commentary)

The controls copper check passed with no geometry errors. The power phase is running, followed by display/audio. I also rechecked npm: the installed tscircuit, tsci and autorouter versions are still the latest.

## 235. Assistant — 2026-10-02T05:33:12.345Z (commentary)

The manual and autorouted control paths now pass the geometry check. I’m waiting for the remaining phases before running whole-board shorts and connectivity checks, since they can add copper near those paths.

## 236. Assistant — 2026-10-02T05:34:37.017Z (commentary)

The power phase is complete, and display/audio routing has started. Once that finishes, I’ll run all-layer Gerber shorts detection and KiCad DRC/connectivity checks on the final board.

## 237. Assistant — 2026-10-02T05:35:38.789Z (commentary)

The combined controls and power copper passes the geometry check. The final routing phase is still running. The release exporter will verify the Gerbers, drills and assembly coordinates against the checked board before saving the ordering files.

## 238. Assistant — 2026-10-02T05:36:43.548Z (commentary)

The final routing phase is still running. I also found and fixed a format-handling issue in the KiCad check script so it can read both a fresh export and a board saved by KiCad.

## 239. Assistant — 2026-10-02T05:37:55.462Z (commentary)

The KiCad format fix passed: running preparation twice leaves the saved board unchanged. The final autorouting phase is still in a long solver step. Its result will determine whether the board is ready for the final checks or needs another local trace correction.

## 240. Assistant — 2026-10-02T05:38:36.823Z (commentary)

All three routing phases are complete, and the combined copper geometry check found no errors. The build is now generating the final board exports. Next are the independent shorts and KiCad checks.

## 241. Assistant — 2026-10-02T05:39:40.353Z (commentary)

The full build passed with zero native errors. The board has 123 standard through-vias. Gerber shorts detection and KiCad DRC/connectivity checks are now running on that finished build.

## 242. Assistant — 2026-10-02T05:40:34.551Z (commentary)

The final board passed both independent checks: no shorts on any copper layer, and zero KiCad geometry or connectivity issues. KiCad’s remaining warnings concern the unavailable external footprint library; the footprints are embedded in the board. I’m generating and verifying the fabrication package now.

## 243. Assistant — 2026-10-02T05:41:28.876Z (commentary)

The fabrication package passed export verification: 217 SMT pad positions, 187 drill features and 619 tracks match the circuit model. It includes four-layer Gerbers, drills, a KiCad project and verified placements for 48 SMD components. I’m recording the release status and publishing it to both repositories.

## 244. Assistant — 2026-10-02T05:42:38.157Z (commentary)

The Gerber ZIP and both assembly BOMs are ready, and the released files pass their checksum checks. I’m publishing the checked revision to GitHub and tscircuit. The release notes record the remaining prototype bring-up work, including display drivers, power tests and FFC orientation.

## 245. Assistant — 2026-10-02T05:43:49.588Z (commentary)

GitHub now contains the checked release. The tscircuit upload is underway with the same source, PCB previews and fabrication files.

## 246. Assistant — 2026-10-02T05:45:12.664Z (commentary)

The tscircuit upload is progressing through the fabrication package and its local 3D models. GitHub is already up to date. I’ll verify that tscircuit’s published files match the checked release once the upload finishes.

## 247. Assistant — 2026-10-02T05:47:35.741Z (commentary)

Tscircuit accepted the circuit and fabrication files, but rejected two large STEP models because of its upload limit. I’m compressing those models and adding a restore command, then republishing. Their original files remain available on GitHub.

## 248. Assistant — 2026-10-02T05:48:31.053Z (commentary)

The compressed models restore correctly and match their original checksums. I’m publishing the updated package with the model archives to stay within tscircuit’s upload limit.

## 249. Assistant — 2026-10-02T05:49:43.616Z (commentary)

The compressed model uploads are succeeding so far. I also verified that GitHub’s published Gerber ZIP matches the checked local file byte for byte.

## 250. Assistant — 2026-10-02T05:51:25.114Z (commentary)

Tscircuit published version 1.0.1 successfully: all 113 files uploaded with no failures. I’m checking the published circuit, Gerber ZIP and model archives against the local release.

## 251. Assistant — 2026-10-02T05:52:24.238Z (final_answer)

Completed the custom Pi Zero 2 W carrier with a Waveshare 3.5″ display and **18-pin, 0.5 mm FPC connector**. No analog sticks or rear buttons.

Latest tscircuit/tsci, three autorouting phases and manual traces are used. Native checks, all-layer shorts checks and KiCad geometry/connectivity checks passed.

- [GitHub](https://github.com/Abse2001/g350-linux-handheld)
- [tscircuit v1.0.1](https://tscircuit.com/abse/g350-linux-handheld)
- [Fabrication files](https://github.com/Abse2001/g350-linux-handheld/tree/main/fabrication)

Ready for prototype fabrication. It requires a custom enclosure; hardware and driver bring-up remain untested.

## 252. Assistant — 2026-10-02T05:52:42.384Z (commentary)

I’m auditing the released board against the active “fully routed, zero DRC” goal. I’ll also resolve the remaining footprint-library warnings so the KiCad report can show zero violations without an exception.

## 253. Assistant — 2026-10-02T05:54:03.014Z (commentary)

The routed copper is already passing. The remaining KiCad findings are 141 references to a missing `tscircuit` footprint library. I’m exporting the actual footprints into a project-local library so KiCad can validate those references.

## 254. Assistant — 2026-10-02T05:55:35.655Z (commentary)

I found KiCad’s native footprint serializer in the installed toolchain. I’m testing the local-library export on a copy first, then running DRC before applying it to the release.

## 255. Assistant — 2026-10-02T05:57:25.170Z (commentary)

The trial board passed an unsuppressed KiCad check: **0 violations and 0 unconnected items**. I’m adding the local-library export to the project workflow and removing the old warning exception from the fabrication gate.

## 256. Assistant — 2026-10-02T05:59:08.183Z (commentary)

The library trial preserved all 1,140 physical board records exactly; only library identities and record ordering changed. I’m making that comparison part of the export workflow, then regenerating the package with a strict zero-violation DRC gate.

## 257. Assistant — 2026-10-02T06:01:00.832Z (commentary)

The integrated workflow now reports **0 DRC violations, 0 warnings and 0 unconnected items**, without a warning exception. The native errors and shorts counts remain zero. I’m refreshing the fabrication package and publishing the included footprint library.

## 258. Assistant — 2026-10-02T06:03:59.370Z (commentary)

The refreshed package passed again: 217 pad positions, 187 drill features and 619 tracks match the circuit model. The zero-DRC report and local footprint library are committed. I’m publishing this audited revision to both repositories.

## 259. Assistant — 2026-10-02T06:05:39.956Z (commentary)

GitHub has the zero-DRC revision. Tscircuit is uploading the complete footprint library. I’m checking the saved evidence against every requirement before marking the goal complete.

## 260. Assistant — 2026-10-02T06:07:27.671Z (commentary)

The local audit confirms the routing, shorts, via spans and release checksums. I’m refreshing two CLI checks whose successful output lacks a summary count. Tscircuit is continuing to upload the footprint templates.

## 261. Assistant — 2026-10-02T06:08:24.074Z (commentary)

Both refreshed CLI checks passed. The full local completion audit is now satisfied, including zero DRC warnings. I’m waiting for the tscircuit upload to finish, then I’ll verify the published files.

## 262. Assistant — 2026-10-02T06:10:37.074Z (commentary)

Tscircuit’s upload has finished successfully. I’m verifying the published zero-DRC report, fabrication ZIP and footprint library against the checked files.

## 263. Assistant — 2026-10-02T06:12:05.628Z (commentary)

Tscircuit version 1.0.2 includes the zero-violation DRC report and all 141 footprint templates. The final comparison is checking every released manufacturing file against its checksum.

## 264. Assistant — 2026-10-02T06:14:07.283Z (final_answer)

Goal complete: the board is fully routed using three autorouting phases and manual traces.

Verified **0 shorts, 0 KiCad DRC violations, 0 DRC warnings and 0 unconnected items**.

- [GitHub and fabrication files](https://github.com/Abse2001/g350-linux-handheld/tree/main/fabrication)
- [tscircuit v1.0.2](https://tscircuit.com/abse/g350-linux-handheld)

All 176 audited published artifacts match their checksums. Prototype hardware remains untested.

Tracked goal time: about 1 hour 38 minutes.

## 265. User — 2026-10-02T08:39:24.341Z

is it ready to be ordered as a prototype

## 266. Assistant — 2026-10-02T08:39:31.188Z (commentary)

I’ll check the release status and ordering files once more before confirming.

## 267. Assistant — 2026-10-02T08:41:22.228Z (final_answer)

**Yes—the files are ready for a first prototype PCB order.** Final checks show **0 shorts, 0 KiCad DRC violations, 0 DRC warnings and 0 unconnected items**.

Order a **4-layer, 1.6 mm FR-4 board** using:

- [Gerber ZIP](/Users/abdolsalamallawlabi/Documents/Codex/2026-10-01-make-the-g350-gameboy-linux-using/fabrication/g350-rev-a-gerbers.zip)
- [JLCPCB assembly BOM](/Users/abdolsalamallawlabi/Documents/Codex/2026-10-01-make-the-g350-gameboy-linux-using/fabrication/bom-jlcpcb.csv)
- [Assembly placement file](/Users/abdolsalamallawlabi/Documents/Codex/2026-10-01-make-the-g350-gameboy-linux-using/fabrication/pnp-jlcpcb.csv)

Review component rotations and polarity in the assembly preview before confirming. The Pi Zero 2 W, display, battery and other external parts require separate purchase and fitting.

**The assembled hardware remains untested.** This is ready for prototype fabrication; power, display and controls still need bench validation before production.

## 268. User — 2026-10-02T08:42:16.080Z

show me pcb snapshot

## 269. Assistant — 2026-10-02T08:42:18.198Z (commentary)

I’ll open the latest PCB snapshot.

## 270. Assistant — 2026-10-02T08:42:29.059Z (final_answer)

Latest PCB snapshot — **100 × 124 mm, four layers**, showing copper routing and component placement.

G350 Linux handheld PCB

## 271. User — 2026-10-02T08:43:29.713Z

we don't componnet on the bottom side also make sure we have an sd card holder and a way to install linux using type c or something

## 272. Assistant — 2026-10-02T08:43:33.517Z (commentary)

I’ll move the carrier’s components to the top side, check the microSD slot and Linux installation path, then reroute and rerun the fabrication checks.

## 273. Assistant — 2026-10-02T08:44:50.326Z (commentary)

The Pi Zero 2 W has the boot microSD slot. Raspberry Pi also supports USB provisioning on this model through `rpiboot`; I’m checking how to expose that connection safely. The existing carrier USB-C port is charging-only. [Raspberry Pi USB provisioning documentation](https://github.com/raspberrypi/usbboot)

## 274. Assistant — 2026-10-02T08:47:43.992Z (commentary)

I found nine SMD components and several hand-fitted headers on the bottom side. I’m moving those to the top and correcting their pin escapes and labels. This creates a new revision, so the earlier ordering files won’t qualify this layout until the new checks pass.

## 275. User — 2026-10-02T08:47:49.667Z

<send_user_message_question_reply>
[{"questionItemId":"[\"request_user_input_async\",\"call_NIuKfHNJoPuXiGACWCBWOaaU\",0]","question":"For Linux installation, is a USB-C microSD reader acceptable, or do you want an on-device USB-C data port connected to the Pi?","answer":"i don't understand the sd reader and usbc are spearete things"}]
</send_user_message_question_reply>

## 276. Assistant — 2026-10-02T08:48:12.453Z (commentary)

Yes, they’re separate things: the microSD card stores Linux; USB-C connects the handheld to a computer.

I’ll keep the Pi’s microSD slot accessible and add a USB-C data port for installing Linux. The existing USB-C charging port will stay separate.

## 277. User — 2026-10-02T08:49:09.397Z

cant we make the same usbc for charging and data

## 278. Assistant — 2026-10-02T08:49:53.365Z (commentary)

Yes—we can use one USB-C port for both charging and data. I’ll connect its data lines to the Pi and update the charger’s input-current control so it can share a computer’s USB port safely.

## 279. Assistant — 2026-10-02T08:54:21.617Z (commentary)

The shared USB-C design now has data-line protection and a connection to the Pi’s USB port. Its power goes through the charger, while the Pi stays powered by the regulated 5 V rail. I’m checking the layout and making the charger default to a lower current before Linux configures the USB connection.

## 280. Assistant — 2026-10-02T09:05:00.626Z (commentary)

The carrier now places every component on top. I’m checking the revised manual traces for shorts and clearance violations before running the three autorouting phases. The shared USB-C port will support charging and Linux provisioning; the microSD card remains the Pi’s boot storage.

## 281. Assistant — 2026-10-02T09:14:38.822Z (commentary)

The top-side placement, source, pin and netlist checks pass. Autorouting is running now. The USB-C port uses the charger for power and a short internal data cable to the Pi; the new charger controls default to 100 mA before the configured Linux gadget allows 500 mA.

## 282. Assistant — 2026-10-02T09:18:30.899Z (commentary)

Yes—the same USB-C port can charge the battery and carry data to the Pi. Linux stays on the microSD card; USB-C provides the connection for writing it.

The new routing is still running. The placement check also flagged two items I’m reviewing: a USB resistor orientation and the display connector’s inward-facing cable entry.

## 283. Assistant — 2026-10-02T09:19:51.604Z (commentary)

The display connector deliberately faces inward so its ribbon reaches the screen. The USB resistor recommendation assumes a direct route; its manually drawn route will be checked for clearance and shorts.

The same USB-C port will support first-time Linux installation through Raspberry Pi’s `rpiboot` tool. That process needs a blank microSD card and a charged battery.

## 284. Assistant — 2026-10-02T09:21:28.615Z (commentary)

The control-routing phase finished with zero routing errors. The power phase is running next. I also checked the charger software’s GPIO transitions: they avoid accidentally selecting the higher-current setting while switching modes.

## 285. Assistant — 2026-10-02T09:23:54.181Z (commentary)

The USB-C charging limit will start at 100 mA and rise to 500 mA after the configured Linux USB connection is established. A charger-only connection will charge more slowly.

The routing and manufacturing checks are still underway; Revision B is not ready to order yet.

## 286. Assistant — 2026-10-02T09:25:42.194Z (commentary)

The power router is still working through the dense connector area. Once all three phases finish, I’ll run the all-layer shorts check and independent KiCad clearance and connectivity checks before exporting the new ordering files.

## 287. Assistant — 2026-10-02T09:28:26.786Z (commentary)

The installed Linux software now uses the charger’s USB-power status to connect and disconnect the USB gadget. That matters because the Pi is powered separately by the battery boost circuit.

The microSD holder will be the Pi Zero 2 W’s existing slot, with access kept clear in the enclosure.

## 288. Assistant — 2026-10-02T09:30:49.692Z (commentary)

The power-routing phase finished with zero routing errors. The final display/audio phase is running now. All carrier components and headers are placed on top; bottom copper is still used for routing.

## 289. Assistant — 2026-10-02T09:35:12.039Z (commentary)

The full routing run finished, but it found clearance problems around some new autorouter vias near the button controller. I’m correcting those before exporting Revision B. It is still not ready to order.

## 290. Assistant — 2026-10-02T09:40:11.555Z (commentary)

The independent check confirmed the clearance issues and found zero open connections. I’ll retain the autorouter’s generated routes while adjusting the offending via and traces manually, then rerun both checkers against the corrected copper.

## 291. Assistant — 2026-10-02T09:52:16.108Z (commentary)

I’ll keep going until the corrected Revision B files pass the fabrication checks and are published in both repositories. I’m checking the latest repair build now, including top-only placement and the shared USB-C charging/data connection.

## 292. Assistant — 2026-10-02T09:54:47.559Z (commentary)

The corrected build now reports zero native PCB errors. I’m running the independent KiCad and all-layer shorts checks next, then verifying the Gerbers, drill positions and top-only assembly files.

## 293. Assistant — 2026-10-02T10:04:58.792Z (commentary)

Yes—the same USB-C port can carry charging power and USB data. I’m finishing the checks for that design, including the top-only assembly and Linux installation path, before publishing the prototype files.

## 294. Assistant — 2026-10-02T10:05:27.871Z (commentary)

Revision B now passes the all-layer shorts check and KiCad’s manufacturing and connectivity checks. All 60 carrier components are on top, and the bottom paste layer is empty. I’m updating the order instructions and publishing the checked files; USB flashing and charging still need validation on the assembled prototype.

## 295. Assistant — 2026-10-02T10:08:14.105Z (commentary)

The order bundle is ready: four-layer Gerbers, top-only assembly BOM and placement files, and a separate list of hand-fitted parts. The file checksums and archived 3D models also pass. I’m publishing Revision B to GitHub and tscircuit, then checking the downloaded release files.

## 296. Assistant — 2026-10-02T10:11:10.099Z (commentary)

GitHub now has the checked Revision B release, and the downloaded ordering files match the local files. The microSD card uses the Pi’s own holder; the same USB-C port provides the Linux installation data path. Initial flashing needs a charged battery because charging starts at a conservative 100 mA limit.

## 297. Assistant — 2026-10-02T10:13:40.973Z (commentary)

The tscircuit upload has reached the software and release scripts with no upload failures so far. Charging can rise to 500 mA after the included USB gadget is configured by a computer; a wall charger without data enumeration stays at 100 mA. Those limits are documented in the order notes.

## 298. Assistant — 2026-10-02T10:15:14.273Z (final_answer)

Yes—Revision B now uses **one USB-C port for charging, data and Linux installation**. Linux boots from the microSD card in the Pi’s holder.

The PCB files are ready for a first prototype order:

- All 60 carrier components are on top.
- Phased autorouting and manual corrections are complete.
- Shorts, clearance and connectivity checks passed.
- Both repositories contain the verified release.

[GitHub](https://github.com/Abse2001/g350-linux-handheld) · [tscircuit](https://tscircuit.com/abse/g350-linux-handheld) · [Order notes](https://github.com/Abse2001/g350-linux-handheld/blob/main/fabrication/STATUS.md)

**Hardware remains untested.** Initial USB flashing needs a charged battery; charging starts at 100 mA and can rise to 500 mA after USB configuration.

Revision B PCB

## 299. User — 2026-10-02T10:23:23.787Z

what does the board have rn

## 300. Assistant — 2026-10-02T10:23:48.411Z (final_answer)

Right now it’s a **100 × 124 mm, four-layer carrier PCB**, with all carrier components on top. It has:

- **11 front buttons:** D-pad, A/B/X/Y, Start, Select and Menu.
- **Linux host connection:** GPIO header and mounting holes for a complete Raspberry Pi Zero 2 W, which provides the CPU, GPU, RAM and wireless.
- **Display connector:** 18-pin flexible-cable connector for a 3.5-inch, 480 × 320 touchscreen.
- **One USB-C port:** charging and USB data, with a path for Linux installation.
- **Battery circuitry:** charging, load sharing, temperature sensing, battery monitoring and a regulated 5 V supply.
- **Audio:** I2S speaker amplifier and speaker connector.
- **OFF-switch connector, testpoints and mounting holes.**

Boot storage uses **the Pi’s own microSD holder**. The Pi, screen, battery and speaker are separate parts attached to this PCB.

There are **no analog sticks or rear buttons**. Fabrication checks passed; the assembled hardware is still untested.

## 301. User — 2026-10-02T10:24:27.032Z

no we need to make Pi Zero 2 W on the board  it slef not add connections

## 302. Assistant — 2026-10-02T10:24:47.867Z (commentary)

Understood—you want the Linux computer built directly into the handheld PCB. The current carrier design doesn’t meet that requirement. I’ll check the Zero 2 W chip’s availability and design documentation before changing the board, because that determines whether we can reproduce it reliably.

## 303. Assistant — 2026-10-02T10:26:10.779Z (commentary)

I found a bare-chip RP3A0 prototype, so this is technically possible. It uses a chip harvested and reballed from a donor Pi, and Raspberry Pi’s published schematic is incomplete. I haven’t verified a JLCPCB source for that chip, so I can’t yet qualify a bare-chip version for ordering. [Prototype design](https://github.com/jonny12375/rp3a0), [official schematic](https://datasheets.raspberrypi.com/rpizero2/raspberry-pi-zero-2-w-reduced-schematics.pdf).

## 304. Assistant — 2026-10-02T10:28:59.219Z (commentary)

I’ve updated the GitHub order guidance to say that Revision B is a carrier and does not satisfy the integrated-computer requirement. The processor and power design, on-board microSD holder, USB wiring and all fabrication checks need to be redone for the new architecture.

## 305. Assistant — 2026-10-02T10:30:07.045Z (final_answer)

Understood—you want **the processor, RAM, power circuitry and microSD holder directly on the main PCB**. The existing carrier doesn’t meet that requirement; I’ve updated GitHub’s order guidance accordingly.

For the exact Zero 2 W **RP3A0 chip**, I haven’t verified a JLCPCB source or complete manufacturer design documentation. The known bare-chip prototype uses harvested, reballed Pi chips. [Prototype details](https://github.com/jonny12375/rp3a0).

A possible alternative is **RK3566 with separate RAM chips on your PCB**. It has a GPU and is listed as a bare component by LCSC. [Rockchip specifications](https://www.rock-chips.com/uploads/pdf/2022.8.26/191/RK3566%20Brief%20Datasheet.pdf), [component listing](https://www.lcsc.com/product-detail/Microcontrollers-MCU-MPU-SOC_span-style-background-color-ff0-Rockchip-span-RK3566_C2943786.html).

**Must it use the exact RP3A0, or is a different Linux/GPU chip directly on the PCB acceptable?**

## 306. User — 2026-10-02T11:32:46.856Z

it might be hard to route you can try

## 307. Assistant — 2026-10-02T11:33:11.051Z (commentary)

I’ll try the RK3566 approach we just discussed, with the processor, RAM and power circuitry directly on the handheld PCB. I’ll import the actual parts, verify the power and memory connections, then work through routing. The integrated design will need new checks before it can be called ready to order.

## 308. Assistant — 2026-10-02T11:35:53.325Z (commentary)

The bare RK3566 import succeeded. I’m using the PDF skill to inspect the processor’s ball map and reference power/memory schematics before connecting it. Those connections and the BGA escape routing will determine whether this can become a working prototype.

## 309. Assistant — 2026-10-02T11:36:50.052Z (commentary)

I found published RK3566 designs that use a single LPDDR4 memory chip and RK817-5 power controller. The routing challenge is the memory bus and power delivery; I’ll check those against the reference documents and test the imported BGA geometry with the autorouter.

## 310. Assistant — 2026-10-02T11:38:55.151Z (commentary)

The RK3566 import contains all 565 ball labels listed in the manufacturer datasheet. I also updated tscircuit and tsci to the newest published versions. Next I’m checking the RAM footprint and attempting memory routing; a routed bus will still need timing and signal-integrity checks.

## 311. Assistant — 2026-10-02T11:42:54.229Z (commentary)

The first routing experiment is running with the real processor and RAM footprints and 67 verified memory connections. I’m routing clocks/strobes, data, then address/control signals in separate phases. The assembly stays top-only; inner layers and bottom copper are available for routing.

## 312. Assistant — 2026-10-02T11:45:12.846Z (commentary)

The footprint check caught 18 RAM pads offset from the manufacturer’s specified grid. I’ll correct those coordinates from the datasheet before retrying routing. This is why the supplier import needs its own geometry check.

## 313. Assistant — 2026-10-02T11:49:55.705Z (commentary)

The first memory-routing pass timed out before producing traces. I’ll try explicit BGA escape routes with smaller vias, then let the autorouter connect the escaped signals. The integrated board is still not ready to order.

## 314. Assistant — 2026-10-02T11:51:20.522Z (commentary)

The timeout report shows the router reached its final length-matching step, so I’m giving that pass more time before changing the escape geometry. I’m also importing the top-mounted microSD socket and the separate CPU regulator needed by the RK3566.

## 315. Assistant — 2026-10-02T11:54:49.434Z (commentary)

The manual BGA escape routes are now in the second experiment, and the autorouter has started connecting the clocks and strobes. I moved the RAM closer to the processor. This version uses filled, copper-capped vias in the BGA pads, which would need that fabrication option if we proceed.

## 316. Assistant — 2026-10-02T12:05:11.613Z (commentary)

The clock/strobe phase completed with the manual escapes in place. The autorouter is now routing the 32 data lines and four data-mask signals around that copper. After routing finishes, I’ll check shorts and run independent DRC before judging whether this approach is usable.

## 317. Assistant — 2026-10-02T12:09:45.689Z (commentary)

The data phase timed out while balancing routes for all 36 signals. I’ll split it into four byte groups and keep each completed group fixed for the next pass. I’m also adding the manufacturer’s drill-to-copper clearance requirement to the experiment.

## 318. Assistant — 2026-10-02T12:16:07.710Z (commentary)

The byte-group trial exposed an autorouter error: one data route changed layers without a via. I’m retrying with a fresh autorouter run for each phase, treating earlier copper as fixed obstacles. Routes with missing vias are rejected.

## 319. Assistant — 2026-10-02T12:29:05.205Z (commentary)

Clocks/strobes and both channel A byte groups routed in the fresh-solver trial. That trial also showed two details needing correction: an existing-via traversal was rejected by my validator, and the routing obstacles represented some through-vias on only part of the layer stack. I’ve corrected those checks and started a stricter retry.

## 320. Assistant — 2026-10-02T12:34:55.848Z (commentary)

The clock and first memory byte group have routed with the two plane layers reserved. I’m checking the remaining groups, then I’ll check the exported copper for shorts and disconnected signals. This is still a routing experiment; the integrated Linux board is not ready to order.

## 321. Assistant — 2026-10-02T12:35:50.805Z (commentary)

The plane restriction is working: the completed routes use only the four signal layers. The next byte group timed out. I’m moving some outer-row escape vias outside the processor footprint to give the inner signals more room, then retrying the phased autorouter.

## 322. Assistant — 2026-10-02T12:37:29.157Z (commentary)

The staggered escape routes have completed the clock/strobe phase. Both chips are on the PCB itself, with all parts on top. The RAM signal map and pad-grid checks pass; routing and DDR timing checks still remain.

## 323. Assistant — 2026-10-02T12:39:43.801Z (commentary)

The staggered layout has now routed 30 of the 67 memory signals: clocks/strobes and both channel A byte groups. I also added a connectivity check that correctly rejects the earlier aborted output with no copper, so a “no shorts” result cannot be mistaken for a routed board.

## 324. Assistant — 2026-10-02T12:43:50.763Z (commentary)

Routing has reached 39 of 67 signals. The manufacturing review also found that some 0.30 mm via lands are too large at the processor’s 0.40 mm pitch to meet drill-to-copper clearance. I’m reducing those specific escape lands to JLCPCB’s supported 0.25 mm size and will check the resulting geometry independently. [JLCPCB capabilities](https://jlcpcb.com/capabilities/pcb-capabilities/)

## 325. Assistant — 2026-10-02T12:48:20.456Z (commentary)

The last retry timed out in channel B’s second byte group. I’ve split the data routing into groups of three signals. The escape check also caught an X-coordinate rounding error I introduced; I corrected it before starting this retry.

## 326. Assistant — 2026-10-02T12:54:17.826Z (commentary)

The corrected 134 manual escapes pass the drill-clearance precheck. I’m retrying the signal routing with more solver effort and larger lands for ordinary routing vias. The power and boot circuits are still incomplete, so fabrication export remains blocked.

## 327. Assistant — 2026-10-02T12:57:48.195Z (commentary)

The smaller groups hit the router’s iteration limit. I’m returning to complete byte groups, which reached 39 signals earlier, while keeping the corrected escape clearances and plane restrictions.

## 328. Assistant — 2026-10-02T13:01:18.129Z (commentary)

The retries are failing while planning paths out of the inner ball array. I’m changing the routing order so those signals leave the processor before the outer clock and data routes occupy the available corridors.

## 329. Assistant — 2026-10-02T13:05:40.010Z (commentary)

The new order has routed 18 inner-array signals with the corrected escapes. Both inner data groups and channel A’s inner control group completed. Channel B’s control group is routing now.

## 330. Assistant — 2026-10-02T13:09:43.389Z (commentary)

All 24 inner-array signals routed. The clock phase then failed my existing-via traversal check. I’m inspecting that route to see whether the exported transition is electrically valid, and I’ll run shorts and DRC on the copper from the completed phases.

## 331. Assistant — 2026-10-02T13:20:13.888Z (commentary)

The rejected transition overlaps the existing via once the trace width is included. My check was too strict because it required the trace’s centreline to stay inside the via land. I’ve corrected that check. The diagnostic export now contains the 24 completed signals, and shorts and connectivity checks are running on that copper.

## 332. Assistant — 2026-10-02T13:29:07.617Z (commentary)

The copper check found two shorts in the 24-signal diagnostic. One involves a via near a RAM ground pad; the other involves a via touching a trace on the bottom layer. I’m adding a check for each new via across all six physical layers before the next routing phase can use it.

## 333. Assistant — 2026-10-02T13:33:17.274Z (commentary)

I’m continuing with the chip-level layout. The memory routing has reached 24 of 67 signals, but the copper checks found two shorts. I’ll fix the through-via handling before routing the remaining signals.

## 334. Assistant — 2026-10-02T13:34:49.785Z (commentary)

The KiCad export also adds duplicate vias at a default size that differs from the declared PCB vias. I’m checking that conversion against the source geometry so KiCad’s report reflects the actual layout.

## 335. Assistant — 2026-10-02T13:37:33.312Z (commentary)

The new via check catches both known shorts and six additional via positions that violate drill clearance. I’ve added rerouting retries that reject those positions while keeping the manufacturing clearances unchanged.

## 336. Assistant — 2026-10-02T13:39:47.778Z (commentary)

The first 14 signals now pass the new via check after rerouting. KiCad independently confirmed the two shorts in the earlier layout and reported drill-clearance failures too, so those routes remain rejected.

## 337. Assistant — 2026-10-02T13:44:36.627Z (commentary)

Eighteen signals have passed the updated via-clearance checks. The next group is still routing; I’m also checking the PMIC pin map while it runs. The current board is still a memory test, with power and peripherals yet to be added.
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

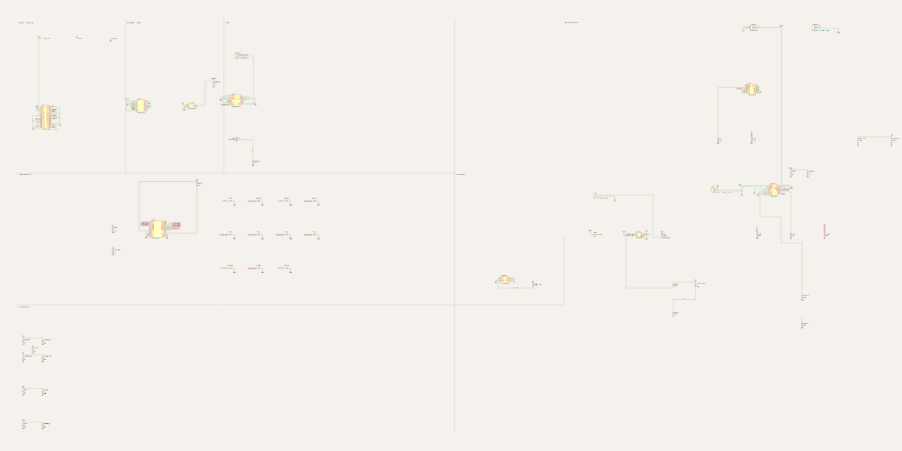
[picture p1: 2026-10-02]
images/schematic-rev-b.png

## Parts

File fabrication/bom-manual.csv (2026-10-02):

Item | Quantity | Specification | Assembly notes
J_PI | 1 | Unshrouded 2x20 male header, 2.54 mm pitch | Fit on top; match silkscreen pin 1
J_BAT | 1 | 1x3 male header, 2.54 mm pitch; battery harness rated at least 3 A | Top; pin 1 battery positive, 2 negative, 3 NTC
J_OFF, J_SPEAKER | 2 | 1x2 male header, 2.54 mm pitch | Fit on top; speaker outputs are both driven
J_USB_LINK | 1 | 1x3 male header, 2.54 mm pitch | Top; pin 1 D-, pin 2 D+, pin 3 GND; no VBUS pin
Pi USB cable | 1 | Shielded micro-B male data-only pigtail with twisted D+/D- pair, nominal 100 mm | Allow routing and plug clearance from the Pi USB port to J_USB_LINK; pin 2 to link 1, pin 3 to link 2, pin 5/shield to link 3; pin 1 VBUS disconnected and insulated, pin 4 ID open
Linux host | 1 | Raspberry Pi Zero 2 W with populated GPIO header | Complete external module on top-side insulating standoffs; preserve microSD insertion/removal access
Boot storage | 1 | microSD card sized for the selected Raspberry Pi OS image | Install in the Pi's own microSD holder; Linux installation via the carrier USB-C data path and rpiboot or a separate card reader
GPIO cable | 1 | Straight-through 40-wire female-to-female GPIO ribbon | Pin 1 to pin 1; preserve both pin rows
Display | 1 | Waveshare 3.5inch Capacitive Touch LCD, ST7796S + FT6336U | 18-pin 0.5 mm FPC host port; use custom GPIO assignments
Display cable | 1 | 18-conductor 0.5 mm pitch, 0.3 mm thick FFC | Choose contact sides for both connectors; verify pin-1 continuity
Battery | 1 | Protected 1S 4.2 V Li-ion/LiPo with attached 10 kOhm 103AT-2-compatible NTC | NTC returns to battery negative; harness rated at least 3 A
Speaker | 1 | 8 Ohm, at least 2 W | Connect between J_SPEAKER pins 1 and 2
Off switch | 1 | External SPST slide switch | Closing J_OFF disables the boost; shut Linux down first
Pi mounting hardware | 4 | Insulating M2.5 nylon screws and standoffs | Choose height to clear the Pi connectors and carrier components

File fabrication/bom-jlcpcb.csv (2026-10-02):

Comment | Designator | Footprint | LCSC Part #
MAX98357AETE+T | U_AUDIO | TQFN-16-EP(3x3) | C910544
100nF | C_AUDIO_HF,C_GAUGE,C_USB_ESD,C_KEYS | 0603 | C14663
10uF | C_AUDIO_BULK,C_BAT,C_SYS,C_BOOST_IN,C_KEYS_BULK | 0805 | C15850
1kΩ | R_AUDIO_EN | 0603 | C21190
100kΩ | R_AUDIO_PD,R_EN,R_FB_LO,R_CHG_PULL,R_GOOD_PULL,R_ALERT_PULL,R_USB_EN1,R_USB_EN2 | 0603 | C25803
TYPE-C-31-M-12 | J_USB | TYPE-C-31-M-12 | C165948
BQ24074RGTR | U_CHARGE | QFN-16-EP(3x3) | C54313
TPS61023DRLR | U_BOOST | SOT-563 | C919459
WPN252012E1R0MT | L_BOOST | 1008 | C370610
5.1kΩ | R_CC1,R_CC2 | 0603 | C23186
3.3kΩ | R_ISET,R_ILIM | 0603 | C22978
68kΩ | R_TIMER | 0603 | C23231
732kΩ | R_FB_HI | 0603 | C23239
1uF | C_USB,C_LCD_IN,C_LCD_OUT | 0603 | C15849
22uF | C_BOOST_OUT1,C_BOOST_OUT2 | 1206 | C12891
220pF | C_FEEDFORWARD | 0603 | C1603
MAX17048G+T10 | U_GAUGE | DFN-8-EP(2x2) | C2682616
USBLC6-2SC6 | U_USB_ESD | SOT-23-6 | C7519
FPC-05F-18PH20 | J_LCD | FPC-0.5-18P | C2856802
AP2112K-3.3TRG1 | U_LCD_PWR | SOT-25-5 | C51118
MCP23017-E/SO | U_KEYS | SOIC-28 | C47023
10kΩ | R_RESET | 0603 | C25804
TS-1187A-B-A-B | SW_UP,SW_DOWN,SW_LEFT,SW_RIGHT,SW_A,SW_B,SW_X,SW_Y,SW_SELECT,SW_START,SW_MENU | SMD-4P | C318884

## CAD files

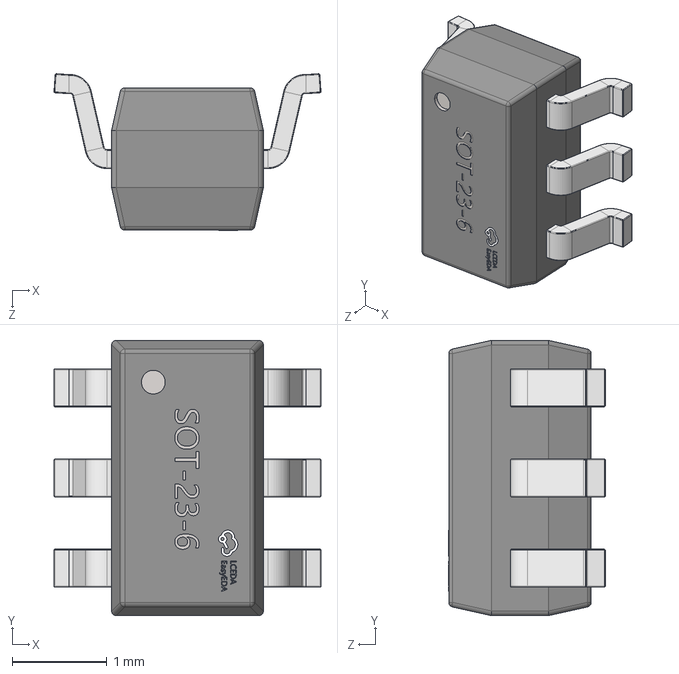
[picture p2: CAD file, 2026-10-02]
imports/USBLC6_2SC6/USBLC6_2SC6.step
2.81 x 2.90 x 1.65 mm

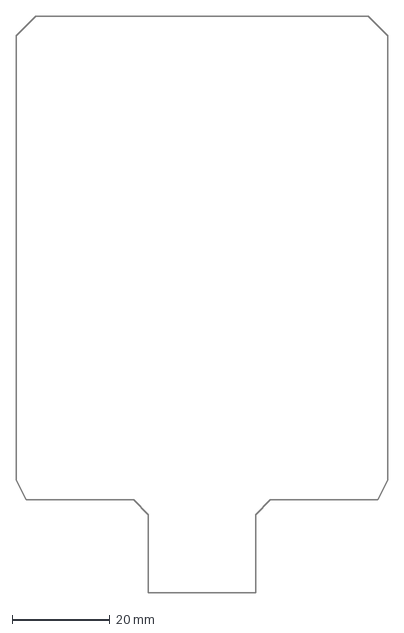
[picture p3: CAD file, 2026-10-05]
mechanical/g350-provisional-outline.dxf
76.0 x 118.0 mm

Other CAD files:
imports/USBLC6_2SC6/USBLC6_2SC6.obj

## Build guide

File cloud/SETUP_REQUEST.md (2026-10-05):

# Requested G350 cloud setup

Name this reusable environment **G350 AM3352 handheld**. This is the continuation
of the existing G350 board, not a new design. Twelve repositories are attached:
Abse2001/g350-linux-handheld plus the eleven upstream repos in
`cloud/repositories.json`.

The authoritative board is on **codex/cloud-handoff**, initially verified remote
commit **a1c21f05b10e2d7951eb153cd972a6406d2a0535**. Fetch that branch and check it
out before inspecting the project. The repository default branch is older.
Read `AGENTS.md`, `docs/CLOUD_HANDOFF.md` and `design-status.json`. The complete
recorded user-visible chat is in `docs/CHAT_CONTEXT.md`.

Setup is verified on Debian 13 with isolated official KiCad 10.0.6 tools; see
`cloud/LINUX_VALIDATION.md`. Debian and Ubuntu setup are supported. Install/run `bash scripts/setup-cloud.sh` in the board repo.
It restores all 25,814 hash-indexed evidence files, installs pinned packages,
Node 25.6.1/Bun 1.3.14/KiCad 10, applies the reviewed native checks correction,
checks out all eleven pinned upstream source references, and verifies typecheck,
native DDR solvers, current Gerber shorts, mechanical checks and KiCad Python.
Source `cloud/env.sh` in each task shell. Keep the published runtime pins and
native check patch; don't upgrade dependencies or substitute upstream HEAD builds
silently. Record the actual Linux KiCad version and fresh verification outputs.

Use the package-manager network preset plus nodejs.org, jscdn.tscircuit.com and
registry.tscircuit.com. Board research also needs docs.tscircuit.com,
tscircuit.com, ti.com, micron.com, jlcpcb.com, lcsc.com and buydisplay.com. No
personal credentials are included or needed for public source installation.

Persist the tested setup as the environment Install script and the shell
initialization/verification instructions as its Start skill. Install setup must
fetch/check out codex/cloud-handoff if the initial checkout uses main. Verify
that newly started tasks have the correct source and restored evidence, rather
than only verifying one temporary setup shell.

This is setup work: do not route hardware or promote an experiment while preparing
the environment. Keep fabricationReady false. The current checked board is
280 parts, four layers, provisional 76 × 118 mm, and only 11/49 DDR connections.
The latest seeded-strobe replay reports 13/49 but independent checks are pending.
Whole-shell fit is unverified. Failed native byte1 outputs remain failed.

The environment was published on 2026-10-06 after setup verification. See
`cloud/transfer-status.json` and the publication screenshot. The human explicitly
requested this transfer and project upload. A new platform board task has not yet
been started or independently verified; use `cloud/CONTINUE_BOARD.md` to continue.

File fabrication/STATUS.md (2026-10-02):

# Revision B fabrication status — carrier only; integrated redesign pending

**Do not order these files for the newly requested integrated-computer handheld. They describe Revision B, which requires an external Pi Zero 2 W. The Linux processor is not on this PCB.** The recorded checks qualify that carrier geometry only; no integrated-computer revision or assembled handheld has been tested. See `../docs/INTEGRATED_HOST.md` for the redesign requirements and unresolved processor sourcing.

The 100 × 124 × 1.6 mm, four-layer FR4 carrier uses a complete Raspberry Pi Zero 2 W through a hand-drawn GPIO interface and mounting layout. All 60 carrier components, including hand-fitted headers, are on top. The Pi and display mount above the carrier on insulating hardware; the carrier's back has copper and through-hole solder joints but no component bodies. The Pi's existing microSD holder supplies accessible Linux boot storage. This carrier requires a custom enclosure and is not a stock G350 replacement.

The Waveshare 3.5inch Capacitive Touch LCD connects through an 18-pin, 0.5 mm FPC host connector. Its ST7796S panel is 480 × 320; FT6336U touch shares I2C with the button controller and fuel gauge. The carrier has eleven front controls, an AP2112 3.3 V display supply, BQ24074 charging/load sharing, TPS61023 5 V boost, MAX17048 monitoring and MAX98357A I2S audio. It has no analog sticks or rear buttons.

One USB-C port carries 5 V charging input and USB 2.0 data. The data path includes an imported USBLC6-2SC6 ESD part and a hand-fitted shielded data-only micro-B pigtail to the Pi. **Disconnect and insulate the pigtail's VBUS wire**: the Pi receives boosted 5 V through J8. Follow the README's wiring and continuity checks. The included Linux gadget services select USB500 only after configuration; initial installation and non-enumerating wall chargers remain at USB100. A charged battery is required for initial USB installation. The battery may discharge while playing or installing.

## Recorded checks — 2026-10-02

- Latest versions verified against npm: tscircuit 0.0.2715, tsci 0.1.2220 and capacity-autorouter 0.0.951. TypeScript, source, pin specification, netlist, schematic placement, PCB placement and routing-difficulty checks pass. PCB placement reports one advisory for the inward-facing LCD connector, deliberately oriented toward the internal display ribbon.
- The qualified CONTROLS, POWER and DISPLAY_AUDIO build passes with **zero native errors**. The actual Pipeline 9 phase routes are retained with documented manual clearance corrections and complete-input/version checks; changed inputs invoke the live autorouter. See `routing/README.txt`. All 148 vias are standard full-depth 0.3 mm drill / 0.65 mm outer diameter; no blind/buried vias are used.
- Final all-layer Gerber-mode shorts check: **no shorts detected**.
- Independent KiCad 10.0.5 check after copper-zone refill: **zero reported DRC violations, zero reported warnings and zero unconnected items**. All 157 exact local footprint templates and `fp-lib-table` are included. Library preparation preserved all 1,253 physical board records. There are no per-item DRC exclusions. KiCad's default ignored checks for missing courtyards, via endpoint centering, tuning profiles and two footprint metadata checks remain listed in `checks/kicad-drc.json`; clearance, shorts, manufacturing geometry and connectivity checks remain enabled.
- Actual exported Gerber flashes match all 226 center-based SMT pads. All 215 drill features match position, diameter and slot direction. All 689 exported tracks match circuit geometry, width and layer within 5 µm. Assembly coordinates use the same lower-left plot datum.
- JLCPCB assembly files contain **23 BOM entries and 52 SMD placements, all on top**, with supplier-verified rotations. The bottom paste Gerber has no drawn or flashed paste. The three top fiducials have explicit 2 mm solder-mask openings and no paste. Hand-fitted headers, Pi, display, cables, battery, speaker, switch and mounting hardware are listed in `bom-manual.csv`.
- USB power software simulation passes configuration permissions, all nine GPIO mode transitions, connection/disconnection binding cases, SIGTERM cleanup and Python/shell syntax. Actual USB enumeration, card flashing, suspend timing and charging are untested on hardware.

Native reference-name, unnamed-trace, schematic-sheet, missing-courtyard and width advisories remain recorded. Width advisories include deliberate 0.15 mm signal escapes and short GND contacts inside pads; filled-zone continuity is verified independently. The release requires 0.15 mm minimum track/clearance rules, standard through-vias, 0.45 mm hole separation, 0.2 mm copper-to-drill clearance and 0.5 mm copper-to-board-edge clearance.

## Order settings and files

Select four layers, 100 × 124 mm, 1.6 mm FR4, green solder mask, 1 oz outer copper, standard 0.5 oz inner copper and top-side SMT assembly. Use the supplier's standard stackup and ordinary plated through-vias. Do not request bottom assembly. Confirm the parsed outline/dimensions, part availability, rotations and polarity in the supplier's order and assembly viewers.

- `g350-rev-b-gerbers.zip`: four copper layers, masks, paste, silk, outline and separate plated/non-plated drills.
- `bom-jlcpcb.csv` and `pnp-jlcpcb.csv`: matching top-only SMD assembly files.
- `bom-manual.csv`: remaining hand-fitted and external items; these are needed for a working handheld.
- `kicad/`: independently checked, refilled board, schematic, rules, exact local footprint library and local 3D models.
- `circuit.json`, `circuit.sha256` and `SHA256SUMS`: released circuit and file integrity records.

The tscircuit registry distributes large local STEP models as lossless `.step.gz` files because of its upload limit. Run `npm run restore:models` in the downloaded project before viewing those models or checking the complete manifest. GitHub also includes the original models. Restoration verifies SHA256 values; Gerbers and assembly files are identical in both repositories.

Circuit SHA256: `c16b7eb122e9d6c722a9fe79981c7c3800c5f57502b41e4af49df3184a85ca7d`.

Checked KiCad board SHA256: `1096c2250e4b74e81be5c1aab48c0d05a665ac2f1f51517aae9764d3931ffaa6`.

## Prototype bring-up

Follow the README's current-limited bring-up sequence, beginning without Pi or display connected. Check rails and dummy-load behavior before adding the Pi, then display, controls and audio. Start with a 1 A total 5 V load ceiling, an 8 Ω speaker and restrained volume. Use a protected 1S 4.2 V cell with its specified attached NTC. Verify FFC pin-1/contact mapping and USB pigtail VBUS isolation before applying power.

Display/touch drivers, SPI refresh performance, USB signal integrity and provisioning, power ripple/load transients, charging, thermal behavior, enclosure/stacked-part fit, cable clearance and wireless performance require hardware bring-up. PCB fabrication readiness does not establish that the assembled handheld functions correctly.

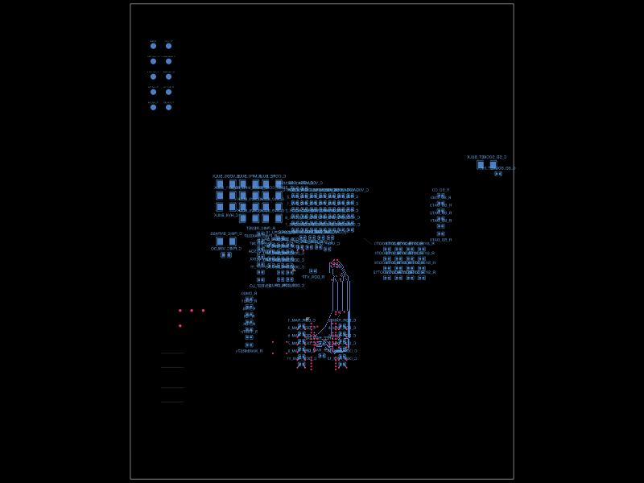
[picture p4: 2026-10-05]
images/am3352-guided-byte0-pair-matched-bottom.png

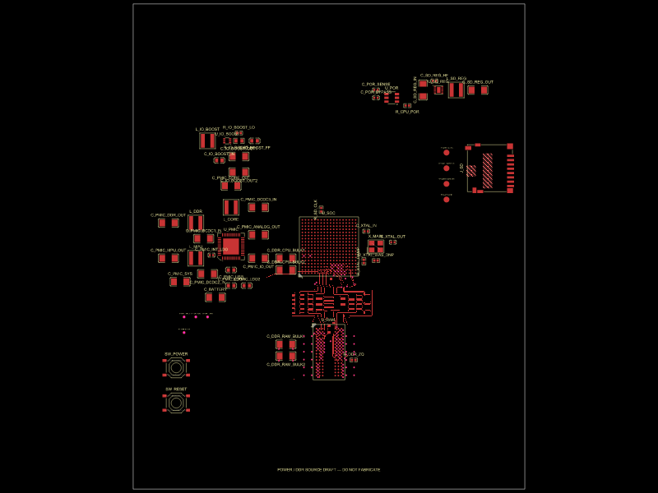
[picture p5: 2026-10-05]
images/am3352-guided-both-bytes-and-reset-top.png

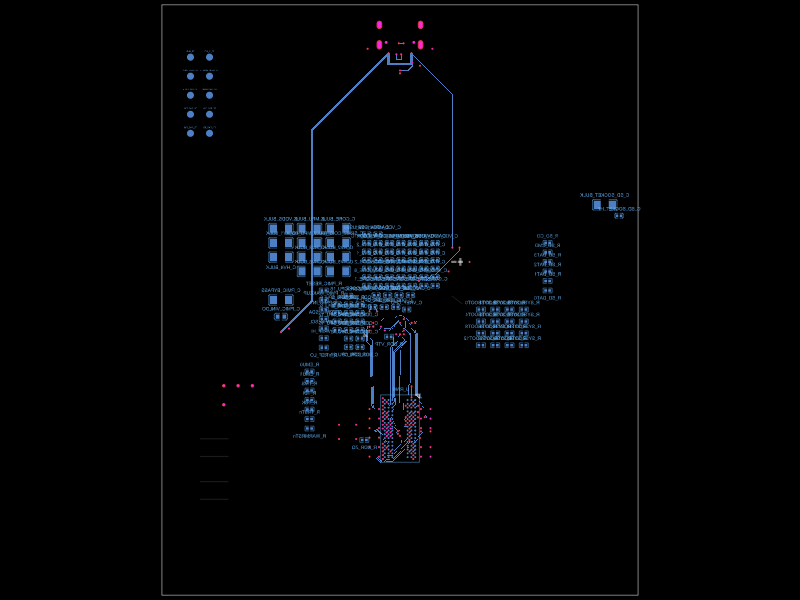
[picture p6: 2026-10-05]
images/am3352-ram-bottom-native19-manual7-replay-bottom.png

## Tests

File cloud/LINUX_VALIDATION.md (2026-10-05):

# G350 cloud Linux validation

Validated 2026-10-06 in **G350 AM3352 handheld**, on Debian 13 x86_64.
The board checkout is `codex/cloud-handoff`; the created-environment transfer
record at `15448a8` was fetched before these setup changes. All eleven attached
upstream checkouts match `cloud/repositories.json` and are inspection sources,
not substitutes for the board's published runtime.

## Tested tools and setup

- Node 25.6.1, Bun 1.3.14, TypeScript 5.9.3; board lockfile unchanged.
- tscircuit 0.0.2744, core 0.0.2088, props 0.0.687, checks 0.0.239,
  capacity-autorouter 0.0.958, CLI 0.1.2237, Circuit JSON 0.0.515,
  React 19.3.0. Shared core identity and native BusLanesSolver,
  BusLanesPipelineSolver and DogboneFanoutSolver exports pass.
- Native checks correction SHA256:
  `50b27442a32befe1fe3f4e83fa082c6efe3e00e6af71e64869778bb68b479805`.
- KiCad CLI 10.0.6 / Python binding 10.0.6+dfsg-1, installed from official
  Debian packages in a Debian sid tool image. Host KiCad 9.0.2 is not used.
  wx 4.2.5 / wxWidgets 3.2.11, Python 3.14.7, reportlab 5.0.0, pypdf 6.19.0.
- Docker 28.4.0 is required. Tool containers are disposable; the 1.5 GiB image
  archive and SHA256 file are retained only under ignored `.cloud-tools`.
  `setup-cloud-kicad.sh` reconstructs it from a digest-pinned official Debian
  base and signed APT packages, or verifies and loads the retained archive.
  It reuses platform Docker proxy settings without saving proxy credentials.

The original Ubuntu-only setup guard now supports Debian through the isolated
KiCad tool image, while retaining the Ubuntu installation path. `cloud/env.sh`
selects local tools and writable caches; `kicad-python.sh` uses headless Xvfb.
Docker `--init` is required so Xvfb can signal readiness. A narrow sitecustomize
alias supplies `SwigPyIterator.next = __next__` for Debian's generated KiCad
binding; iteration, StopIteration, board data and checker assertions are unchanged.
`checkout-cloud-upstreams.mjs` reuses attached checkouts rather than duplicating
all eleven repositories. `verify-cloud.sh` preserves frozen mechanical evidence
and retains the fresh mechanical report under ignored `checks/cloud`.

## Results

- Restored and hash verified all **25,814 evidence files**; repeated restoration
  succeeds without replacing edited evidence.
- `bash scripts/setup-cloud.sh` and the reusable Install script complete the
  pinned install, evidence restoration and cloud smoke checks.
- A fresh task shell sources `cloud/env.sh` and verifies tools, board hashes,
  patched checks, solver exports, all upstream refs and KiCad/Python imports.
- `npm run typecheck`: pass.
- Current all-layer Gerber shorts: **zero**, using the unchanged frozen circuit.
- Mechanical checks: three current outputs preserve the provisional 76 × 118 ×
  1.6 mm outline and four layers. Original-shell fit remains unverified.
- Fresh `tsci export --format kicad_pcb`: pass, output under `checks/cloud`.
- KiCad `pcb drc --refill-zones --save-board --format json --all-track-errors
  --severity-all --exit-code-violations`: executes and saves fresh board/report.
  The unqualified raw export exits **5**, with **1,296 error violations,
  699 warnings and 499 reported/capped opens**. This demonstrates tool operation,
  not physical qualification; the raw export lacks the board's release adapters.
- `prepare-kicad-library.py` on that fresh normalized export: **280 exact local
  footprints**, all **1,052 physical records unchanged**.
- Unchanged existing byte0 plane checker on frozen KiCad 10 evidence: **101
  package terminals, 119 full-depth vias, both filled planes continuous**, pass.
- Frozen DDR connectivity checker: **11/49 connected**, exactly the expected
  partial result. No additional DDR channel is qualified by setup.

Fresh reports/logs are in ignored `checks/cloud`; command logs are in
`/workspace/setup-logs`. Original frozen circuit SHA256 remains
`01815364357e0354de1089af4253e2ce2dc926f822b5f173b7ccb133e459f555`, and the byte0
KiCad board remains
`1b61379e0f651fa99527abd1721de2819ced06adbf4c4fc6269ab6ca8e2c6cfd`.

## Start and continuation

```bash
cd /workspace/g350-linux-handheld
source cloud/env.sh
node scripts/verify-cloud-state.mjs
node scripts/checkout-cloud-upstreams.mjs
kicad-cli version
scripts/kicad-python.sh -c 'import pcbnew, wx; print(pcbnew.GetBuildVersion()); print(wx.version())'
```

To refresh: `bash scripts/setup-cloud.sh`. To rerun the smoke suite:
`bash scripts/verify-cloud.sh`. Use existing checkouts; do not create a worktree
unless explicitly requested. No persistent application service is needed.

The prepared filesystem and tested scripts are ready for environment publication;
publication and restoration into a new platform task are separate user actions
and have not been claimed as completed. The retained image can load in a fresh
Docker runtime; no running container is required to survive the snapshot.

Hardware sources, dependency declarations, lockfiles and frozen evidence are
unchanged. **fabricationReady remains false**: current default is 280 parts,
four layers, 11/49 DDR channels. Seeded-strobe independent qualification, exact
shell fit and all documented release gates remain outstanding. No routing,
experimental promotion or fabrication publication was performed. Continue with
`cloud/CONTINUE_BOARD.md` after publishing the reusable environment.

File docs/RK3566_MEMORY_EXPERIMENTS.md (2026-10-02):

# Historical RK3566 routing — superseded by AM3352

# G350-style integrated Linux handheld — in progress

The Linux/GPU processor, RAM and power management must be directly on the handheld PCB. **The integrated design is not ready to fabricate or order.** The default entry displays a memory-routing experiment. Existing Revision B Gerbers and `rev-b.circuit.tsx` describe an external Raspberry Pi carrier and do not satisfy this requirement. The fabrication exporter blocks release while integration is incomplete.

The architecture under investigation is a bare **Rockchip RK3566**, **1 GB Hynix LPDDR4**, **RK817-5 PMIC** and **RK860-0 CPU regulator**, authored in tscircuit. Individual components were imported with `tsci import --jlcpcb --use-exact-footprint`. No complete computer board or processor module is imported. See [the integrated-host design record](INTEGRATED_HOST.md).

The completed handheld may use components and routing on both top and bottom, following the user's updated placement permission. It must have eleven front buttons, an FPC display, an onboard microSD holder and one USB-C connector for charging and data/provisioning. It has no analog sticks or rear buttons. Imported power ICs and the microSD socket are candidates for integration; the memory fixture does not yet contain those circuits. Existing checked fixtures still place both chips on top; their reports describe that actual geometry.

## Current routing work

`experiments/rk3566-memory.circuit.tsx` tests direct autorouting with the actual 565-ball SoC and 200-ball RAM footprints. Its first clock/strobe phase timed out at 120 seconds. `experiments/rk3566-memory-vip.circuit.tsx` adds 134 explicit full-depth escapes and moves RAM closer to the processor. Some outer-row vias are staggered outside the processor; 25 fine-pitch escapes use 0.25mm lands, and the other escapes use 0.30mm lands. All drills are 0.15mm. The latest manual geometry passes its drill-to-copper/drill-to-drill precheck.

An earlier eight-phase trial routed 39/67 signals before timing out, using escape lands that subsequently failed the drill-clearance review. Three-signal retries reached the planner's iteration limit. The current retry routes the 24 inner-array signals before clocks/strobes and the outer data/control signals. The byte-group trial hit the planner limit; the current experiment uses 31 individual outer-signal phases after six earlier phases, plus two manual fanout stages. Each phase uses the installed local Pipeline 9 autorouter with earlier copper frozen as obstacles. A four-layer routing model maps onto the four signal layers of the physical six-layer board because the current router ignored the bus layer restriction. Physical through-vias remain obstacles on every signal layer; Inner1/Inner4 are reserved for future reference planes.

The earlier 24-signal diagnostic failed Gerber shorts and independent KiCad DRC. Eight local via movements and one wire dogleg repair those routes: the repaired diagnostic passes Gerber shorts and KiCad copper/drill clearances, while retaining 43 unrouted signals and incomplete-fixture warnings. At that stage, only those checked routes were retained under a full input fingerprint. Later routing progress is described below. New vias and wires are checked against actual physical copper/drills. See `checks/integrated/repaired-check-summary.json` and `checks/integrated/phase-via-validation.json`.

The through-via terminal-access retry completed clocks/strobes, reaching 36/67 signals. Seven explicit outer traces now extend the fixture to **43/67**: DQ0_A uses a reviewed path with six points, five further traces use a supplementary constant-layer grid search, and DQ4_A uses a grid-planned detour with one full-depth layer-change via. The six initial phases retain actual Pipeline 9 routing; remaining unmatched phases still use the live Pipeline 9 autorouter. Explicit coordinates are reused only under the complete input fingerprint and fresh wire/via checks.

The actual **43-signal** diagnostic passes Gerber shorts and independent KiCad copper/drill checks. Its connectivity graph confirms 43 signals, with **24 opens and 61 dangling-via warnings** remaining. DQ8_A timed out at 134.4 seconds; bounded one- and two-via grid searches have not found an accepted continuation. See `checks/integrated/memory-43-check-summary.json`, `memory-43-connectivity.json` and `memory-43-phase-validation.json`. This is routing progress, not a manufacturing release.

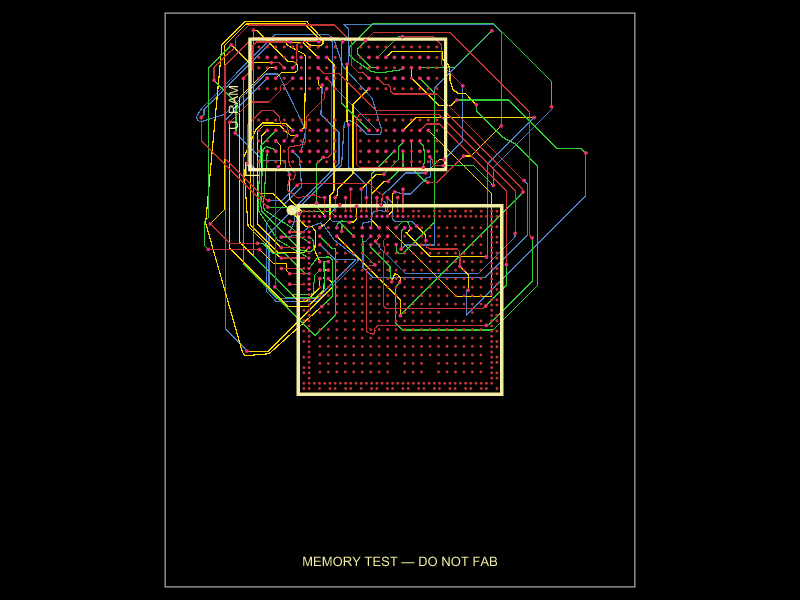
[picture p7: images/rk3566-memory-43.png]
Actual 43-signal memory diagnostic; not the completed handheld


These are **memory-routing feasibility fixtures**, containing 67 datasheet-checked signal connections. They omit host power, decoupling, clock, boot, storage, USB, display, controls and audio circuits. They cannot run Linux. DDR timing, coupled-pair geometry, reference planes, impedance, package flight times and electrical via lengths require qualification on the complete host.

Eighteen imported RAM pads were off the manufacturer's nominal grid and have been corrected. The SoC and RAM grids and all 67 signal functions pass the import checker. All 69 PMIC pin aliases were checked; internal 1.8 V filter rails must be decoupled rather than driven by another regulator. The microSD shell/contact aliases were corrected against its manufacturer drawing; full geometry comparison remains pending. Attempt sources, logs and verification evidence are in `checks/integrated/`.

## Build the memory fixture

Versions verified and pinned on 2026-10-02: **tscircuit 0.0.2727**, **tsci CLI 0.1.2227**, **capacity-autorouter 0.0.951**. The npm lock uses legacy peer resolution because the current upstream CLI and tscircuit packages request different circuit-json peer versions.

```sh
npm ci --legacy-peer-deps
npm run typecheck
npm run check:integrated-imports
npm run build:memory > checks/integrated/memory-vip-build.log 2>&1
npm run check:memory-escapes
npm run check:memory-connectivity
```

`npm run check:shorts` first requires complete memory connectivity, then runs the Gerber shorts checker on that same fixture output. Run independent DRC on the actual exported copper too. Shorts checks on an aborted render with no traces or vias do not prove routed connectivity. None of the fixture's checks qualifies the completed handheld.

The six-layer trial targets ENIG with **filled and copper-capped** 0.15mm drilled vias, no blind or buried vias, and top-only assembly. This is a proposed fabrication process. Final stackup, impedance, drill clearances and manufacturer assembly review remain required. [JLCPCB's capabilities](https://jlcpcb.com/capabilities/pcb-capabilities/) provide the fabrication limits used in this investigation.

## Repositories and earlier revision

- [GitHub](https://github.com/Abse2001/g350-linux-handheld)
- [tscircuit integrated experiment](https://tscircuit.com/abse/g350-linux-handheld?version=1.2.2-integrated-experimental)
- [Historical Revision B carrier documentation](REV_B_CARRIER.md)
- [Historical fabrication status](fabrication/STATUS.md)

Registry v1.1.0 still describes Revision B. **1.2.1-integrated-experimental** contains the checked 36-signal integrated source; all 105 stored files were verified by SHA-256 after recovering an archive-response timeout. The current 43-signal source uses **1.2.2-integrated-experimental**. Experimental versions remain explicitly incomplete; the old carrier's successful checks cannot be reused for Revision C.

`tsci push` currently ignores `.gitignore`. Use `node scripts/stage-registry-source.mjs tmp/registry-source-VERSION` to prepare the reviewed tracked source allowlist, then push from that directory. It excludes local reference PDFs, temporary work and historical fabrication archives. An aborted native render with no copper is never accepted as a shorts/connectivity pass.

The 1.2.2 publication uploaded 120 source/evidence files. `bun scripts/verify-registry-source.mjs tmp/registry-source-1.2.2` reads every file back and compares SHA-256 hashes, then checks the release is non-latest. The registry initially marked the tagged upload latest despite the CLI option; that metadata was corrected and the previous default retained. This explicit version link opens the integrated experiment. Publication does not establish successful full routing or fabrication readiness.

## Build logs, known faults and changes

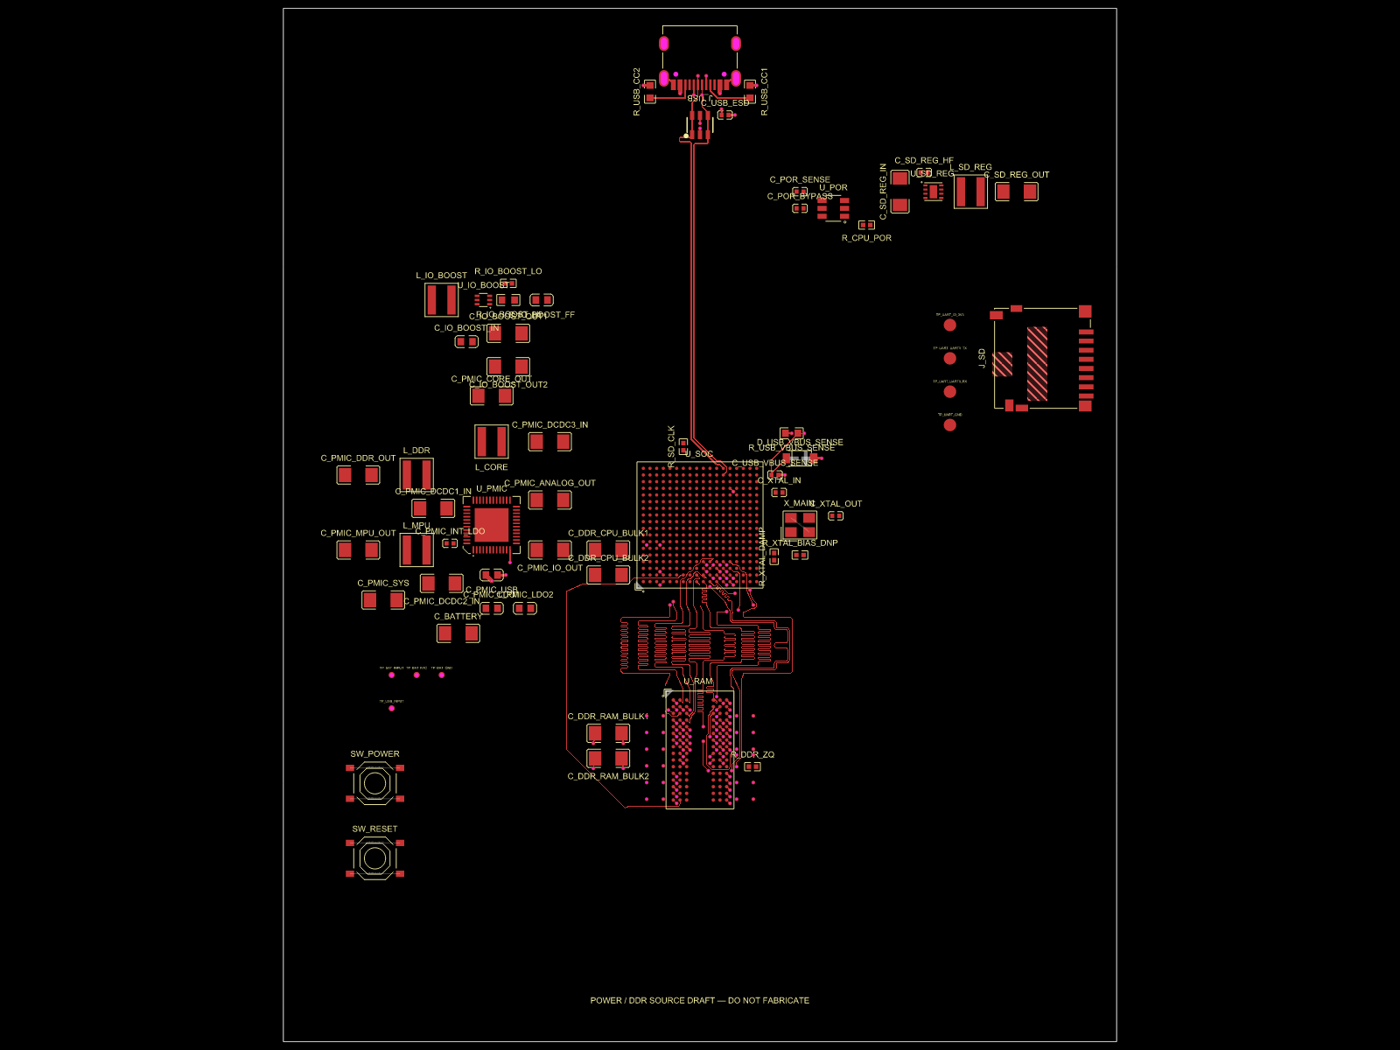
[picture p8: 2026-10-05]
images/am3352-ddr-usbc-repaired-strobes-top.png

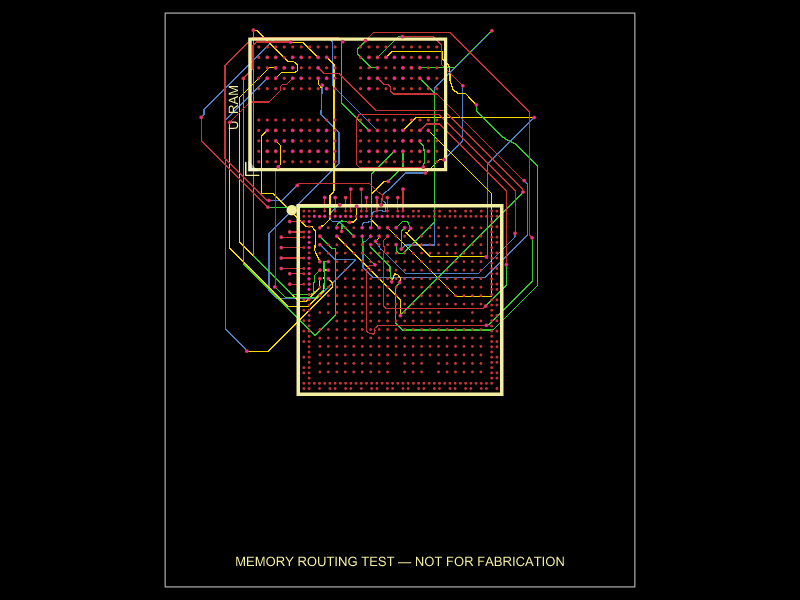
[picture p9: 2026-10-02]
images/rk3566-memory-repaired.png

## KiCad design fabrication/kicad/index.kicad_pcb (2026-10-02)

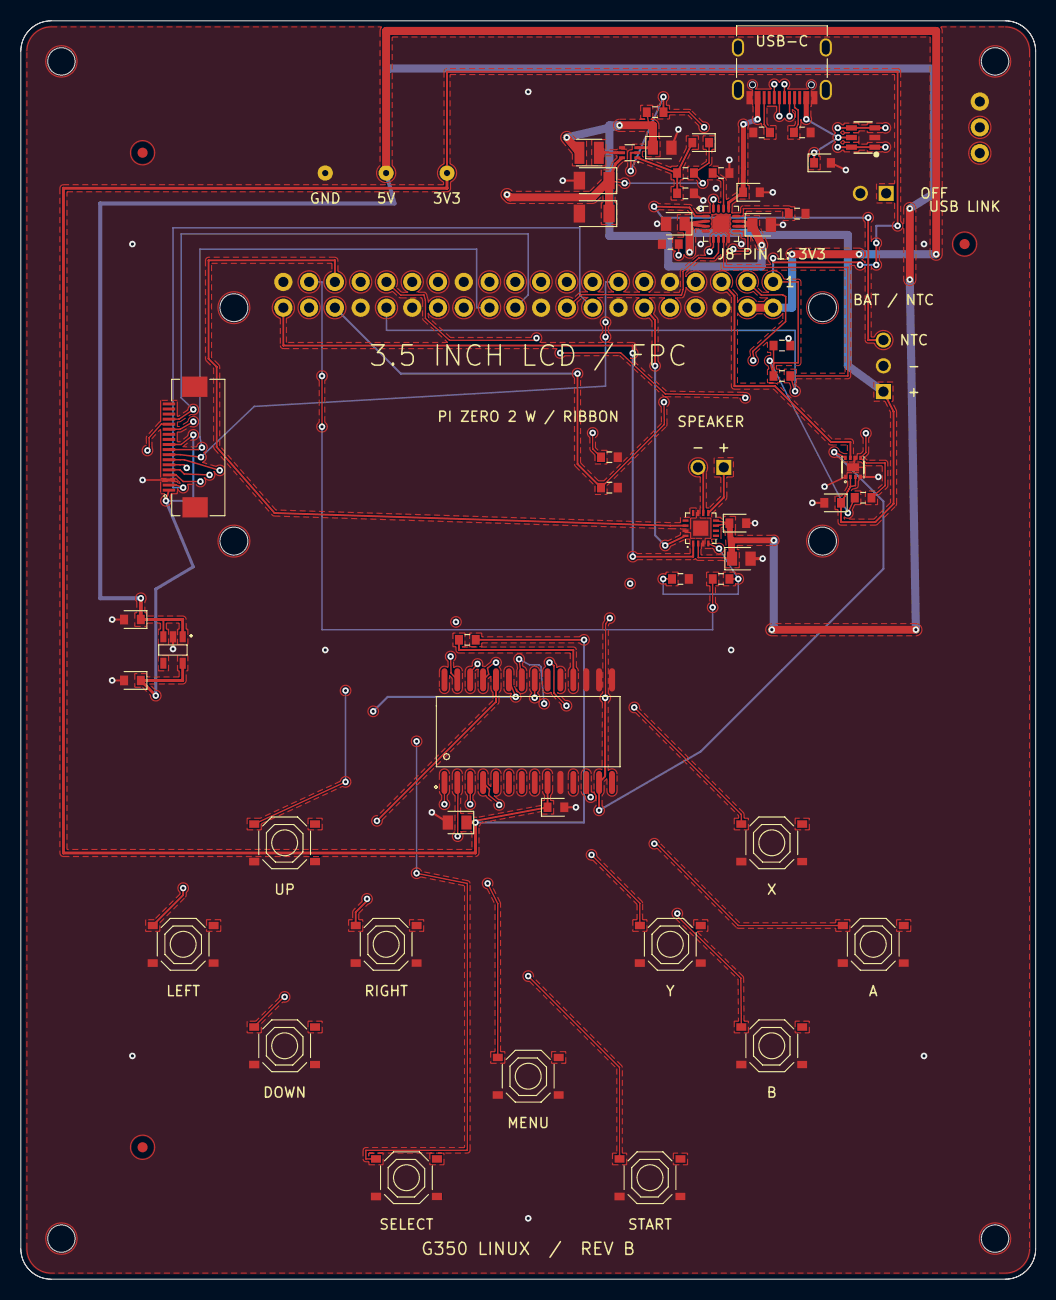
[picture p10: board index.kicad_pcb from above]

Board: 4 copper layers, 100.0 x 124.0 mm, 60 parts (0 on the bottom side), 52 nets.

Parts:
C_AUDIO_BULK: 10uF; g350_C_AUDIO_BULK_6c8053e0121015ff486027e25d2f9a3d
C_AUDIO_HF: 100nF; g350_C_AUDIO_HF_4f8718706f1c09302dbf2ad0139db390
C_BAT: 10uF; g350_C_BAT_47d06ae03787dae1491fdf5e36386663
C_BOOST_IN: 10uF; g350_C_BOOST_IN_5255146047f73ebf3d99691e333b937d
C_BOOST_OUT1: 22uF; g350_C_BOOST_OUT1_7e38f91c406a288400f2b5dc424f943c
C_BOOST_OUT2: 22uF; g350_C_BOOST_OUT2_1b885d80651f5cbf1a38e902666ed13d
C_FEEDFORWARD: 220pF; g350_C_FEEDFORWARD_16c584a07135c2813459ff9e26163e43
C_GAUGE: 100nF; g350_C_GAUGE_07aee08077a9654108fe54fe7659f0c3
C_KEYS: 100nF; g350_C_KEYS_644960c23e17dcbe1f86e5c27d25a842
C_KEYS_BULK: 10uF; g350_C_KEYS_BULK_468ee6ca3a2664ea2dbde30a2155612a
C_LCD_IN: 1uF; g350_C_LCD_IN_5be2f4460c8d09ba74fd07ba2292fa46
C_LCD_OUT: 1uF; g350_C_LCD_OUT_796ff1802c1fd09f2e506d42773f54dd
C_SYS: 10uF; g350_C_SYS_08f8654077af54ff07a8f0c278fec97d
C_USB: 1uF; g350_C_USB_6f7d3200112a883f6e2dbd821279fcbd
C_USB_ESD: 100nF; g350_C_USB_ESD_55af1c004fe0a61f0a8f97c264ffd5a3
J_BAT: J_BAT; g350_J_BAT_1c1b67e03e54d601673aec1e0ccaae3d
J_LCD: FPC-05F-18PH20; g350_J_LCD_023284580e9b06381b038818276c09f8
J_OFF: J_OFF; g350_J_OFF_72356f40335a52df2715eb027e79d71d
J_PI: 2x20 2.54mm GPIO ribbon header; g350_J_PI_45b957de51d6aa22169953de7f0951de
J_SPEAKER: J_SPEAKER; g350_J_SPEAKER_3187528028e8eb617ca6d6be223698dd
J_USB: TYPE-C-31-M-12; g350_J_USB_2a17ef222ac30dde7f9e0ade2b86f822
J_USB_LINK: J_USB_LINK; g350_J_USB_LINK_151b40200abd6a7f005f94de09fe40c3
L_BOOST: 1µH; g350_L_BOOST_162d00c0709d3ea134f2837e257dba63
R_ALERT_PULL: 100kΩ; g350_R_ALERT_PULL_3ed784801b98b9617608f7422f86cadd
R_AUDIO_EN: 1kΩ; g350_R_AUDIO_EN_00256ea05a4acf414b44f2de0f2b4b03
R_AUDIO_PD: 100kΩ; g350_R_AUDIO_PD_59fa59004b95691f0edad4c2694b12a3
R_CC1: 5.1kΩ; g350_R_CC1_1675a34070e5e12134a9e0fe25c65ce3
R_CC2: 5.1kΩ; g350_R_CC2_70956ae034fa573f2575e6a27fe62483
R_CHG_PULL: 100kΩ; g350_R_CHG_PULL_7cb2e42028dcddff31935fe273fc623d
R_EN: 100kΩ; g350_R_EN_2bedbaa0536a8b212d3d2f1e521b16a3
R_FB_HI: 732kΩ; g350_R_FB_HI_577e14c02929a57f562ea0422a7919fd
R_FB_LO: 100kΩ; g350_R_FB_LO_1fea8fa05f6db621213a041e5e1e41a3
R_GOOD_PULL: 100kΩ; g350_R_GOOD_PULL_2f2dc0202b427dc17a4d445e1fdd067d
R_ILIM: 3.3kΩ; g350_R_ILIM_21d596405ed223ff208621c26021987d
R_ISET: 3.3kΩ; g350_R_ISET_2238e4a07ca9228128e69f9e31899e43
R_RESET: 10kΩ; g350_R_RESET_1a8653a074f691813099309e29d70d43
R_TIMER: 68kΩ; g350_R_TIMER_7999bf001f29811f3b46bcc26a49055d
R_USB_EN1: 100kΩ; g350_R_USB_EN1_2d820ae02cee330178a18f1e1e31513d
R_USB_EN2: 100kΩ; g350_R_USB_EN2_18011b8072715961331e68be2751d523
SW_A: SW_A; g350_SW_A_69607ec017473b7f68110a421896affd
SW_B: SW_B; g350_SW_B_732329a00c351c2174729e1e0ae5a7a3
SW_DOWN: SW_DOWN; g350_SW_DOWN_66fbc8fa73644ada7fccccba73cab166
SW_LEFT: SW_LEFT; g350_SW_LEFT_093028fc1598aadc22012cbc2e69ae9c
SW_MENU: SW_MENU; g350_SW_MENU_4553bc603b53fddf440447e23ca3725d
SW_RIGHT: SW_RIGHT; g350_SW_RIGHT_2a1c1df636849fd642ed21b64f55a396
SW_SELECT: SW_SELECT; g350_SW_SELECT_69cf658e5d66e3ae50fe61ce4495dfee
SW_START: SW_START; g350_SW_START_4c2facc034780d7f4ae0384235c781fd
SW_UP: SW_UP; g350_SW_UP_0f36f6001b9f77e02807f9c034707ba0
SW_X: SW_X; g350_SW_X_35f9e5604aadd4df34aa70e24bfd495d
SW_Y: SW_Y; g350_SW_Y_59763d0027317d3f5826c8822880f1bd
TP_3V3: TP_3V3; g350_TP_3V3_7afe24202a919dff2fde9fe275b1223d
TP_5V: TP_5V; g350_TP_5V_19c1e4e0743222c1315d9f5e29129e83
TP_GND: TP_GND; g350_TP_GND_1bb7c0407627fe212f67c3fe2b0879e3
U_AUDIO: MAX98357AETE+T; g350_U_AUDIO_22ebc3c07d5c01a12833c07e323c7d63
U_BOOST: TPS61023DRLR; g350_U_BOOST_1f3f53c079af91a12be0307e2e900d63
U_CHARGE: BQ24074RGTR; g350_U_CHARGE_5486e04005e95da160599b824536269d
U_GAUGE: MAX17048G+T10; g350_U_GAUGE_1b637ee075d3bcc12fbc055e2ab43883
U_KEYS: MCP23017-E/SO; g350_U_KEYS_647741a01ae1042165c6b61e19918fa3
U_LCD_PWR: AP2112K-3.3TRG1; g350_U_LCD_PWR_6bb0e2e01140a4ff492f98e25c60293d
U_USB_ESD: USBLC6-2SC6; g350_U_USB_ESD_7ae7b8e0673f34e15396b0e23fee2ce3

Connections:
AMP_ENABLE: J_PI.37, R_AUDIO_EN.1
AMP_MODE: R_AUDIO_EN.2, R_AUDIO_PD.1, U_AUDIO.4
BAT_ALERT_N: J_PI.31, R_ALERT_PULL.2, U_GAUGE.5
BOOST_SW: L_BOOST.2, U_BOOST.5
BUTTON_LEFT: SW_LEFT.1, U_KEYS.23
BUTTON_MENU: SW_MENU.1, U_KEYS.3
BUTTON_SELECT: SW_SELECT.1, U_KEYS.1
BUTTON_UP: SW_UP.1, U_KEYS.21
CHARGE_ISET: R_ISET.1, U_CHARGE.16
CHARGING_N: J_PI.29, R_CHG_PULL.2, U_CHARGE.9
FB: C_FEEDFORWARD.2, R_FB_HI.2, R_FB_LO.1, U_BOOST.1
GND: C_AUDIO_BULK.2, C_AUDIO_HF.2, C_BAT.2, C_BOOST_IN.2, C_BOOST_OUT1.2, C_BOOST_OUT2.2, C_GAUGE.2, C_KEYS.2, C_KEYS_BULK.2, C_LCD_IN.2, C_LCD_OUT.2, C_SYS.2, C_USB.2, C_USB_ESD.2, J_BAT.2, J_LCD.3, J_LCD.19, J_LCD.20, J_OFF.2, J_PI.6, J_PI.9, J_PI.14, J_PI.20, J_PI.25, J_PI.30, J_PI.34, J_PI.39, J_USB.1, J_USB.2, J_USB.3, J_USB.4, J_USB.13, J_USB.14, J_USB_LINK.3, R_AUDIO_PD.2, R_CC1.2, R_CC2.2, R_FB_LO.2, R_ILIM.2, R_ISET.2, R_TIMER.2, R_USB_EN1.2, R_USB_EN2.2, SW_A.3, SW_B.3, SW_DOWN.3, SW_LEFT.3, SW_MENU.3, SW_RIGHT.3, SW_SELECT.3, SW_START.3, SW_UP.3, SW_X.3, SW_Y.3, TP_GND.1, U_AUDIO.3, U_AUDIO.11, U_AUDIO.15, U_AUDIO.17, U_BOOST.4, U_CHARGE.4, U_CHARGE.8, U_CHARGE.17, U_GAUGE.1, U_GAUGE.4, U_GAUGE.6, U_GAUGE.9, U_KEYS.10, U_KEYS.15, U_KEYS.16, U_KEYS.17, U_LCD_PWR.2, U_USB_ESD.2
I2S_BCLK: J_PI.12, U_AUDIO.16
I2S_DIN: J_PI.40, U_AUDIO.1
I2S_LRCLK: J_PI.35, U_AUDIO.14
J_SPEAKER.pin1 to U_AUDIO.OUTP: J_SPEAKER.1, U_AUDIO.9
J_SPEAKER.pin2 to U_AUDIO.OUTN: J_SPEAKER.2, U_AUDIO.10
J_USB.CC2 to R_CC2.pin1: J_USB.12, R_CC2.1
LCD_BL: J_LCD.2, J_PI.16
LCD_CS: J_LCD.9, J_PI.24
LCD_DC: J_LCD.7, J_PI.15
LCD_RESET: J_LCD.8, J_PI.13
R_CC1.pin1 to J_USB.CC1: J_USB.6, R_CC1.1
R_RESET.pin1 to U_KEYS.N_RESET: R_RESET.1, U_KEYS.18
SCL: J_LCD.13, J_PI.5, U_GAUGE.7, U_KEYS.12
SDA: J_LCD.14, J_PI.3, U_GAUGE.8, U_KEYS.13
SPI_MISO: J_LCD.6, J_PI.21
SPI_MOSI: J_LCD.5, J_PI.19
SPI_SCLK: J_LCD.4, J_PI.23
SW_A.pin1 to U_KEYS.GPA4: SW_A.1, U_KEYS.25
SW_B.pin1 to U_KEYS.GPA5: SW_B.1, U_KEYS.26
SW_DOWN.pin1 to U_KEYS.GPA1: SW_DOWN.1, U_KEYS.22
SW_RIGHT.pin1 to U_KEYS.GPA3: SW_RIGHT.1, U_KEYS.24
SW_START.pin1 to U_KEYS.GPB1: SW_START.1, U_KEYS.2
SW_X.pin1 to U_KEYS.GPA6: SW_X.1, U_KEYS.27
SW_Y.pin1 to U_KEYS.GPB3: SW_Y.1, U_KEYS.4
TOUCH_IRQ: J_LCD.15, J_PI.22
USB_5V: C_USB.1, C_USB_ESD.1, J_USB.15, J_USB.16, U_CHARGE.13, U_USB_ESD.5
USB_DN: J_USB.7, J_USB.9, J_USB_LINK.1, U_USB_ESD.1, U_USB_ESD.6
USB_DP: J_USB.8, J_USB.10, J_USB_LINK.2, U_USB_ESD.3, U_USB_ESD.4
USB_EN1: J_PI.18, R_USB_EN1.1, U_CHARGE.6
USB_EN2: J_PI.36, R_USB_EN2.1, U_CHARGE.5
USB_GOOD_N: J_PI.32, R_GOOD_PULL.2, U_CHARGE.7
U_BOOST.EN to R_EN.pin2: J_OFF.1, R_EN.2, U_BOOST.2
U_CHARGE.ILIM to R_ILIM.pin1: R_ILIM.1, U_CHARGE.12
U_CHARGE.TMR to R_TIMER.pin1: R_TIMER.1, U_CHARGE.14
U_CHARGE.TS to J_BAT.pin3: J_BAT.3, U_CHARGE.1
V3V3: C_KEYS.1, C_KEYS_BULK.1, J_PI.1, R_ALERT_PULL.1, R_CHG_PULL.1, R_GOOD_PULL.1, R_RESET.2, TP_3V3.1, U_KEYS.9
V5V: C_AUDIO_BULK.1, C_AUDIO_HF.1, C_BOOST_OUT1.1, C_BOOST_OUT2.1, C_FEEDFORWARD.1, C_LCD_IN.1, J_PI.2, J_PI.4, R_FB_HI.1, TP_5V.1, U_AUDIO.2, U_AUDIO.7, U_AUDIO.8, U_BOOST.6, U_LCD_PWR.1, U_LCD_PWR.3
VBAT: C_BAT.1, C_GAUGE.1, J_BAT.1, U_CHARGE.2, U_CHARGE.3, U_GAUGE.2, U_GAUGE.3
VSYS: C_BOOST_IN.1, C_SYS.1, L_BOOST.1, R_EN.1, U_BOOST.3, U_CHARGE.10, U_CHARGE.11
V_LCD3V3: C_LCD_OUT.1, J_LCD.1, J_LCD.10, U_LCD_PWR.5

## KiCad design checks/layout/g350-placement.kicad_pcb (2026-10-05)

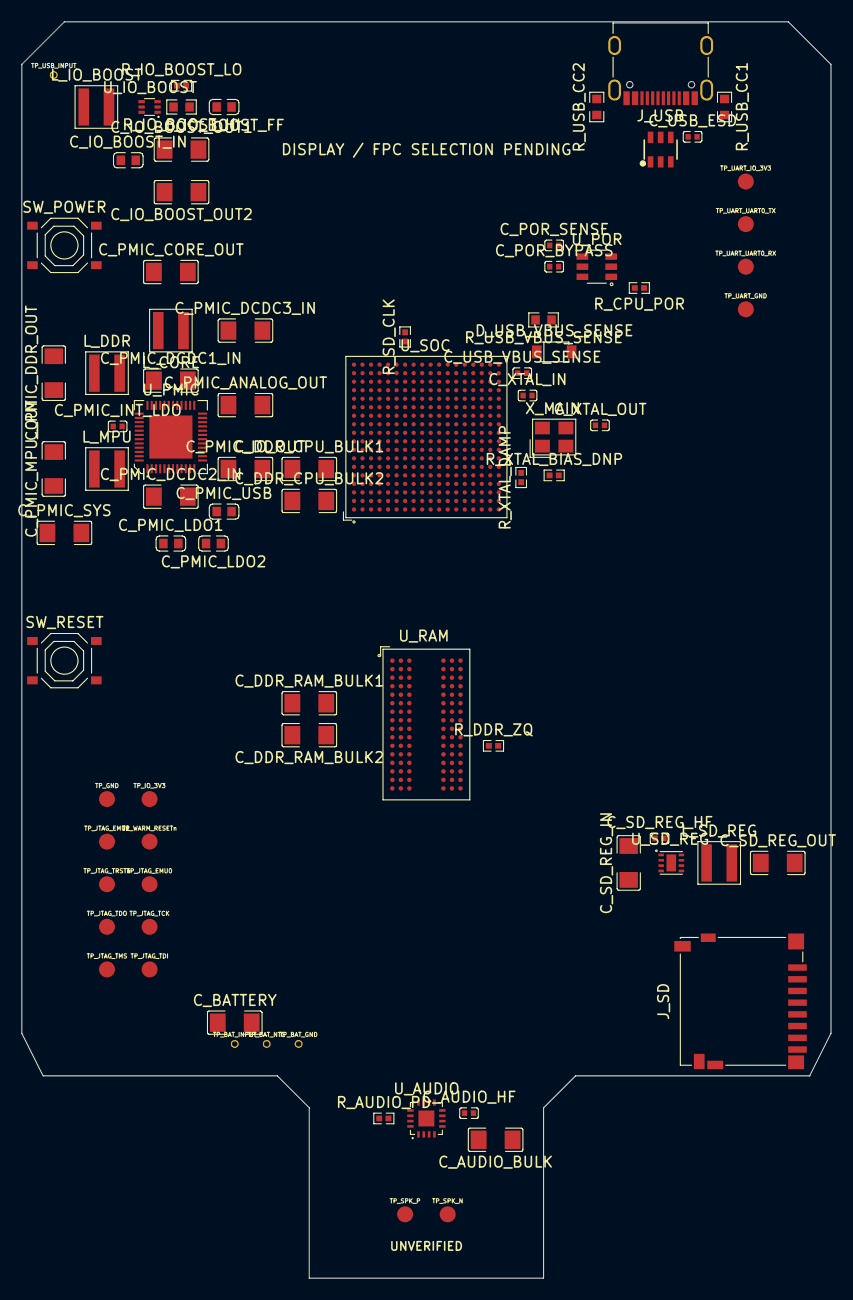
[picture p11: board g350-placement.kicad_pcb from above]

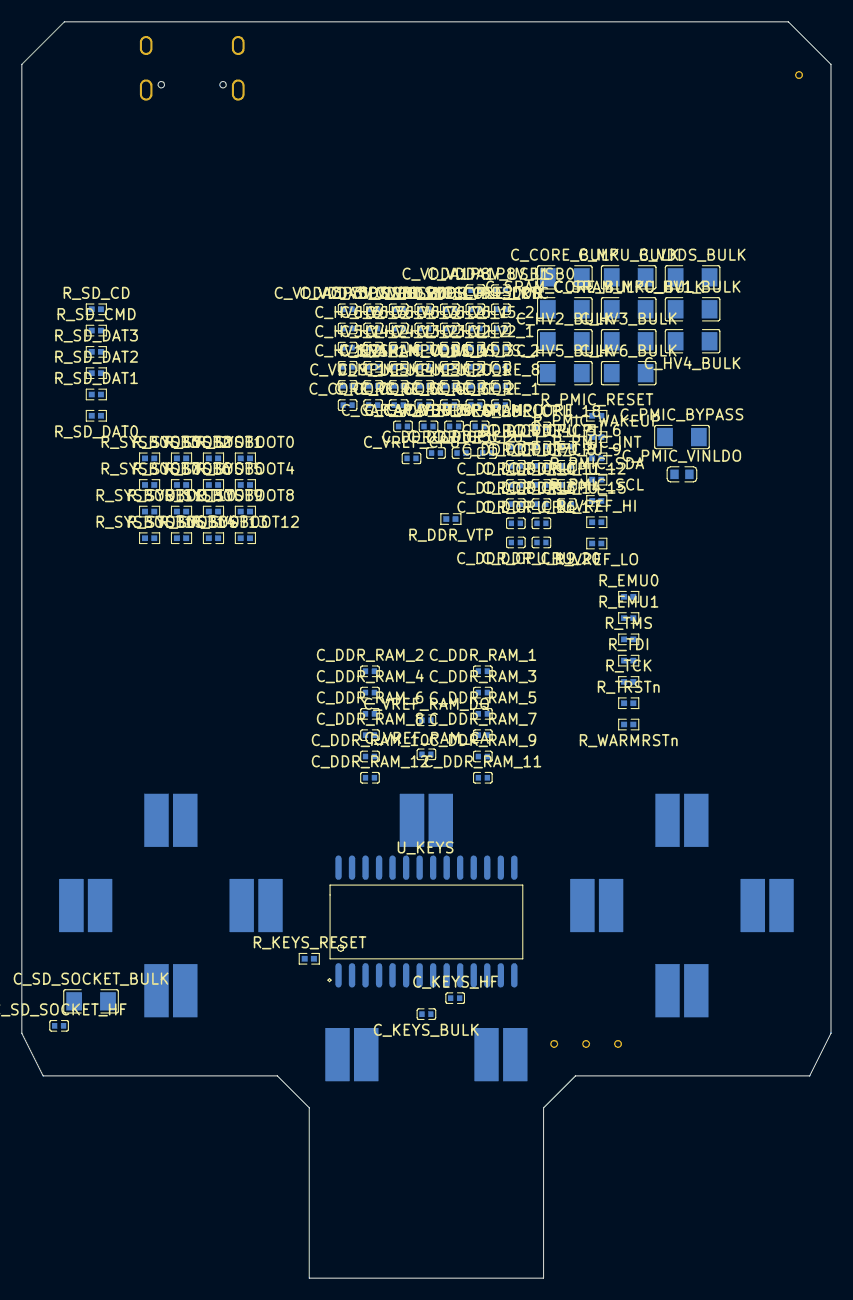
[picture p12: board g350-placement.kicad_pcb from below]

Board: 4 copper layers, 76.0 x 118.0 mm, 233 parts (150 on the bottom side), 148 nets, no tracks yet.

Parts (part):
C_AUDIO_BULK: 22uF; g350_C_AUDIO_BULK_392600202ec82a7f246a54de1a0c7f3d
C_AUDIO_HF: 100nF; g350_C_AUDIO_HF_6961d4c073bfaa617e1d80027784aa5d
C_BATTERY: 22uF; g350_C_BATTERY_017ffda058f040414c9f81de0dd0bc03
C_CAP_VBB_MPU: 1uF; g350_C_CAP_VBB_MPU_2b81a1a053d6a4212cd1161e52872fa3
C_CAP_VDD_RTC: 1uF; g350_C_CAP_VDD_RTC_4f287ad61c87f76a77c796560c172416
C_CAP_VDD_SRAM_CORE: 1uF; g350_C_CAP_VDD_SRAM_CORE_27316bca705e963607ee9836608165ca
C_CAP_VDD_SRAM_MPU: 1uF; g350_C_CAP_VDD_SRAM_MPU_6c5eec801448cdbf6b0f78021598423d
C_CORE_1: 10nF; g350_C_CORE_1_6f95c4740725c674614a378c3645ca74
C_CORE_2: 10nF; g350_C_CORE_2_70f2ffc2648a7de25821fc024bb97a22
C_CORE_3: 10nF; g350_C_CORE_3_3f84b4f44bed36d45855b8b464be3a94
C_CORE_4: 10nF; g350_C_CORE_4_2a3d1800551b2dc12b8c8c7e53cbb943
C_CORE_5: 10nF; g350_C_CORE_5_0628fea07a7ebb9f04d98a227bce301d
C_CORE_6: 10nF; g350_C_CORE_6_2a8fad002fe090e175af313e1b3ef35d
C_CORE_7: 10nF; g350_C_CORE_7_0687dfa078d0662107d7541e7780f1a3
C_CORE_8: 10nF; g350_C_CORE_8_272d43b81ac4c1d80e5c3ff801f3be18
C_CORE_BULK: 22uF; g350_C_CORE_BULK_16fc94be7f6c92be18236f42504c8ebe
C_DDR_CPU_1: 100nF; g350_C_DDR_CPU_1_2898d3a01e3afdff13dd285e097f52bd
C_DDR_CPU_2: 100nF; g350_C_DDR_CPU_2_67dadb807238b1217c9686c2790ba39d
C_DDR_CPU_3: 100nF; g350_C_DDR_CPU_3_04949b0005c93aa1102710421a84e5e3
C_DDR_CPU_4: 100nF; g350_C_DDR_CPU_4_7030576065d281bf5b74ac1e5116d67d
C_DDR_CPU_5: 100nF; g350_C_DDR_CPU_5_695a0ce05efc373f549e619e4a408bfd
C_DDR_CPU_6: 100nF; g350_C_DDR_CPU_6_65b6c060701496017a726ba27b2fbebd
C_DDR_CPU_7: 100nF; g350_C_DDR_CPU_7_382afac04288d0614ce6a60257447ba3
C_DDR_CPU_8: 100nF; g350_C_DDR_CPU_8_4a9f542054fd29c15f5aff6269b8d503
C_DDR_CPU_9: 100nF; g350_C_DDR_CPU_9_19b02160240df7012e6bcca238c9a243
C_DDR_CPU_10: 100nF; g350_C_DDR_CPU_10_13dba440097dce9f00e007020b3ddca3
C_DDR_CPU_11: 100nF; g350_C_DDR_CPU_11_0d0559c002a7841f07b6518212142723
C_DDR_CPU_12: 100nF; g350_C_DDR_CPU_12_3df48c803396b6df2938e13e1edb0b9d
C_DDR_CPU_13: 100nF; g350_C_DDR_CPU_13_6b80522061227c7f56c4a6de4c66d13d
C_DDR_CPU_14: 100nF; g350_C_DDR_CPU_14_64aa07a05a4c31ff4fee5c5e459086bd
C_DDR_CPU_15: 100nF; g350_C_DDR_CPU_15_6a66c5a074c49b417f2270e2767fb97d
C_DDR_CPU_16: 100nF; g350_C_DDR_CPU_16_3cdb00004738d5a15196ab425bf480e3
C_DDR_CPU_17: 100nF; g350_C_DDR_CPU_17_43b14a804e0f2021586cf5c262cacb63
C_DDR_CPU_18: 100nF; g350_C_DDR_CPU_18_49dd50803f7f7adf3521a53e2ac3cf9d
C_DDR_CPU_19: 100nF; g350_C_DDR_CPU_19_7ab837607ae9f2ff708c1d5e662e47bd
C_DDR_CPU_20: 100nF; g350_C_DDR_CPU_20_7e717e207413a87f69b5d2de5f57fd3d
C_DDR_CPU_BULK1: 22uF; g350_C_DDR_CPU_BULK1_42cca9e062c3183f0852da5e521d6383
C_DDR_CPU_BULK2: 22uF; g350_C_DDR_CPU_BULK2_0096cea059d96f414bb652de0eb9eb03
C_DDR_RAM_1: 100nF; g350_C_DDR_RAM_1_569de7843db1a63c2dfecc046650c1bc
C_DDR_RAM_2: 100nF; g350_C_DDR_RAM_2_79d282006f74ac5f6516d6be5ab9011d
C_DDR_RAM_3: 100nF; g350_C_DDR_RAM_3_2c33bcfc3f7cb54454d2d87c16dd99c4
C_DDR_RAM_4: 100nF; g350_C_DDR_RAM_4_26299b80308771213ae546c245431c63
C_DDR_RAM_5: 100nF; g350_C_DDR_RAM_5_50fa9e844354ef3c285b83046bf40abc
C_DDR_RAM_6: 100nF; g350_C_DDR_RAM_6_2e3c382023de627f19808cde0f22b73d
C_DDR_RAM_7: 100nF; g350_C_DDR_RAM_7_72abeb9206fb795264b4f8ee2f9a94d2
C_DDR_RAM_8: 100nF; g350_C_DDR_RAM_8_71bfe5607c1dbb0179846f5e6f2699bd
C_DDR_RAM_9: 100nF; g350_C_DDR_RAM_9_6dbe16442691777c451efac44f3092fc
C_DDR_RAM_10: 100nF; g350_C_DDR_RAM_10_15f529c02052ff612ab0d502350eaaa3
C_DDR_RAM_11: 100nF; g350_C_DDR_RAM_11_15138e3c569ce4043db2a9bc2dfdc884
C_DDR_RAM_12: 100nF; g350_C_DDR_RAM_12_4a0eb8c03fb0e31f35530d7e2af537dd
C_DDR_RAM_BULK1: 22uF; g350_C_DDR_RAM_BULK1_7aedb7fa78a9c6266c4144465fd8c266
C_DDR_RAM_BULK2: 22uF; g350_C_DDR_RAM_BULK2_1ebe593e2b26db1e378f5cfe43f7dede
C_HV1_1: 10nF; g350_C_HV1_1_0829cf40787deaff06da5ac279cd5f7d
C_HV1_2: 10nF; g350_C_HV1_2_4bb8be80415ae8df36fd133e2c9f3d9d
C_HV1_BULK: 22uF; g350_C_HV1_BULK_09e989ca725987ca25367a36433983ca
C_HV2_1: 10nF; g350_C_HV2_1_6bfdecbc5f956adc532ce8fc46c4671c
C_HV2_2: 10nF; g350_C_HV2_2_60320aca341d82f63792ef4a5cbc9e76
C_HV2_BULK: 22uF; g350_C_HV2_BULK_5ffad558087528a870e526a826aadb58
C_HV3_1: 10nF; g350_C_HV3_1_2e8f0aae3d216792572e262e14824c12
C_HV3_2: 10nF; g350_C_HV3_2_53f48fa05e52654168b03ae2730e1083
C_HV3_BULK: 22uF; g350_C_HV3_BULK_1fc34a4648acb3ba4ee34e46198cafba
C_HV4_1: 10nF; g350_C_HV4_1_5b5eeb60510115bf46a3401e3c456a7d
C_HV4_2: 10nF; g350_C_HV4_2_6c0ba120134ca4a16d5b159e11fd3023
C_HV4_BULK: 22uF; g350_C_HV4_BULK_68c4eaca0054ecca681b11362f74f0ca
C_HV5_1: 10nF; g350_C_HV5_1_4789fa803d2c24df32ce4f3e2870799d
C_HV5_2: 10nF; g350_C_HV5_2_54d51658613d98386da61a187a0e9bf8
C_HV5_BULK: 22uF; g350_C_HV5_BULK_255bb616431447ea547bba1613f443ea
C_HV6_1: 10nF; g350_C_HV6_1_03e22f4c67ce42f42c814acc3f2f2774
C_HV6_2: 10nF; g350_C_HV6_2_77bb943e1c93f9824f1c78be45331502
C_HV6_3: 10nF; g350_C_HV6_3_7b2c5be070ce863f6670b09e5c12dafd
C_HV6_4: 10nF; g350_C_HV6_4_2344978018e6c1df0e88ec3e042b169d
C_HV6_5: 10nF; g350_C_HV6_5_558fb60029c88fc156df2a7e28791b43
C_HV6_6: 10nF; g350_C_HV6_6_7058346065fa5ebf5b9c891e513eb37d
C_HV6_BULK: 22uF; g350_C_HV6_BULK_1adbd4fc7cb42d0414442f04542bcefc
C_IO_BOOST_FF: 220pF; g350_C_IO_BOOST_FF_1b9ed2187bf12fe8138131e854eecc18
C_IO_BOOST_IN: 4.7uF; g350_C_IO_BOOST_IN_7caf58521ae0a9ae4d8f54524a00adae
C_IO_BOOST_OUT1: 22uF; g350_C_IO_BOOST_OUT1_4c7931fe4b16d0021d592dfe7a36d402
C_IO_BOOST_OUT2: 22uF; g350_C_IO_BOOST_OUT2_41bf548855d0ad78129f50887b0f4e88
C_KEYS_BULK: 1uF; g350_C_KEYS_BULK_1be086401182b09f0724dafe0338faa3
C_KEYS_HF: 100nF; g350_C_KEYS_HF_44d2b8440375d9e43de7047c7f43e2dc
C_MPU_1: 10nF; g350_C_MPU_1_036722446f1794842537f93c46787904
C_MPU_2: 10nF; g350_C_MPU_2_7f04e5ce154aa7f25665ca4e3de9c372
C_MPU_3: 10nF; g350_C_MPU_3_3d2088e0477e5e8151dc34225c3a09c3
C_MPU_4: 10nF; g350_C_MPU_4_6af7b2c06099dd1f563c077e4bde31dd
C_MPU_5: 10nF; g350_C_MPU_5_0b497340755e46ff09f9fec276adbb7d
C_MPU_BULK: 22uF; g350_C_MPU_BULK_1e96738678f98e7a1089907a57e66d86
C_PMIC_ANALOG_OUT: 22uF; g350_C_PMIC_ANALOG_OUT_0932188471a2168425edeb7c42821284
C_PMIC_BYPASS: 22uF; g350_C_PMIC_BYPASS_1a4338f07d4cc91014dccb10539332f0
C_PMIC_CORE_OUT: 22uF; g350_C_PMIC_CORE_OUT_6a60b6665df83486518fb2a6452730c6
C_PMIC_DCDC1_IN: 22uF; g350_C_PMIC_DCDC1_IN_65068552716f07327dd7891275bff50e
C_PMIC_DCDC2_IN: 22uF; g350_C_PMIC_DCDC2_IN_1351746e06e8f28e057f8f5211e81132
C_PMIC_DCDC3_IN: 22uF; g350_C_PMIC_DCDC3_IN_3347fa3c352803c46267fe3c0607ffc4
C_PMIC_DDR_OUT: 22uF; g350_C_PMIC_DDR_OUT_7cee543a147e563a53f1a7c6439e5a3a
C_PMIC_INT_LDO: 100nF; g350_C_PMIC_INT_LDO_3a6d63b62e029a4a698d67b6011d69b6
C_PMIC_IO_OUT: 22uF; g350_C_PMIC_IO_OUT_4cda1f3c4ab5e2c41dba1b3c79d5e6c4
C_PMIC_LDO1: 2.2uF; g350_C_PMIC_LDO1_48b55ebc4edaa34419955abc7dfaa744
C_PMIC_LDO2: 2.2uF; g350_C_PMIC_LDO2_74cb947622c46d8a45ab907651e4718a
C_PMIC_MPU_OUT: 22uF; g350_C_PMIC_MPU_OUT_4040e684574f1b7c1120e2847990e084
C_PMIC_SYS: 22uF; g350_C_PMIC_SYS_4df5013c1a7afcc47d15053c14a5073c
C_PMIC_USB: 4.7uF; g350_C_PMIC_USB_4f24e4d4486b1d2c2004e0d4778b212c
C_PMIC_VINLDO: 4.7uF; g350_C_PMIC_VINLDO_70be2a746455a89457ed26b44b84a4d4
C_POR_BYPASS: 100nF; g350_C_POR_BYPASS_563d331649d4b1363d6c2f563103ad76
C_POR_SENSE: 10nF; g350_C_POR_SENSE_4b57af6457c031446428b32470913504
C_SD_REG_HF: 100nF; g350_C_SD_REG_HF_5ad8de204517cba12f56b9221995a6a3
C_SD_REG_IN: 22uF; g350_C_SD_REG_IN_19e505e065733fe11b347a5e6423cb63
C_SD_REG_OUT: 22uF; g350_C_SD_REG_OUT_261774605a9045df24c7ffe25bdfba5d
C_SD_SOCKET_BULK: 22uF; g350_C_SD_SOCKET_BULK_2d0df660376bcc0141c9a1a24c277743
C_SD_SOCKET_HF: 100nF; g350_C_SD_SOCKET_HF_0600e8400fc02a3f25813cbe3b424f3d
C_SRAM_CORE_1: 10nF; g350_C_SRAM_CORE_1_4fc5cba05a23a141648176e26edf4c83
C_SRAM_CORE_BULK: 22uF; g350_C_SRAM_CORE_BULK_0e82044076f20240209dffc047d1fe40
C_SRAM_MPU_1: 10nF; g350_C_SRAM_MPU_1_5f8daf60552fd9bf4ad2041e40742e7d
C_SRAM_MPU_BULK: 22uF; g350_C_SRAM_MPU_BULK_50d25cd046bda53021b258d075dda930
C_USB_ESD: 100nF; g350_C_USB_ESD_4c3c73561f73feea74db8ed6092b1c96
C_USB_VBUS_SENSE: 100nF; g350_C_USB_VBUS_SENSE_0ab2960a171b17ea238399ca2fec1baa
C_VDDA1P8V_USB0: 10nF; g350_C_VDDA1P8V_USB0_3863beb22bfb3cd21f92baf2132a3912
C_VDDA1P8V_USB1: 10nF; g350_C_VDDA1P8V_USB1_62180b80323782403978f0005ad69dc0
C_VDDA3P3V_USB0: 10nF; g350_C_VDDA3P3V_USB0_3603f920246c44c17edc82a226b33f7d
C_VDDA3P3V_USB1: 10nF; g350_C_VDDA3P3V_USB1_6b2348001434fdc16c72bc7e12e58943
C_VDDS_1: 10nF; g350_C_VDDS_1_5722c1e04cc4ec3f4267169e380940fd
C_VDDS_2: 10nF; g350_C_VDDS_2_431b75fc36b2f41c2a4a723c1de1f05c
C_VDDS_3: 10nF; g350_C_VDDS_3_415adc0a52f4b1b618bbc08a7b93cd36
C_VDDS_4: 10nF; g350_C_VDDS_4_4307606c28a911d46ba67bec0009f654
C_VDDS_BULK: 22uF; g350_C_VDDS_BULK_30b5957837ba68885fd59978089a6488
C_VDDS_OSC: 10nF; g350_C_VDDS_OSC_480ebc8037498941495e30fe35fa14c3
C_VDDS_PLL_CORE_LCD: 10nF; g350_C_VDDS_PLL_CORE_LCD_668e2be472f6adc47f5f2fa474384e7c
C_VDDS_PLL_DDR: 10nF; g350_C_VDDS_PLL_DDR_49e988d23d8106f23118851224b00332
C_VDDS_PLL_MPU: 10nF; g350_C_VDDS_PLL_MPU_17a8a5e067af9fe118f81a5e66602b63
C_VDDS_RTC: 10nF; g350_C_VDDS_RTC_6966348400f636846779c77c30163a84
C_VREF_CPU: 100nF; g350_C_VREF_CPU_549572043fba1bbc2bf656846859373c
C_VREF_RAM_CA: 100nF; g350_C_VREF_RAM_CA_62637aa06cc15041771f25e27e83047d
C_VREF_RAM_DQ: 100nF; g350_C_VREF_RAM_DQ_5bb33d20661112c1706ee8627accbe03
C_XTAL_IN: 18pF; g350_C_XTAL_IN_7a27b68438cad8240892063c49eee49c
C_XTAL_OUT: 18pF; g350_C_XTAL_OUT_0ec3049e501fe2fe6e833ea22d266042
D_USB_VBUS_SENSE: D; g350_D_USB_VBUS_SENSE_33eeefac27866dcc1b1debec0eb56a0c
J_SD: DM3D-SF; g350_J_SD_4162de604bc0b401561e89a2607c5f43
J_USB: TYPE-C-31-M-12; g350_J_USB_48664640098e047f5b824f3e52896603
KEY_A: g350_KEY_A_37e0d400477771c13930487e4627fd43
KEY_B: g350_KEY_B_25c1e3a05ae5d69f24726f225c354b1d
KEY_DOWN: g350_KEY_DOWN_4cb4b49c404c32bc33e3b0dc277b2efc
KEY_LEFT: g350_KEY_LEFT_4ab0b7923e4835b231dfb3d2257731f2
KEY_MENU: g350_KEY_MENU_417a98403f2d21ff402b23c2407c967d
KEY_RIGHT: g350_KEY_RIGHT_4e00fda041987bc0352ff9e028c77800
KEY_SELECT: g350_KEY_SELECT_61751792550c95b248a413d23c3b91f2
KEY_START: g350_KEY_START_26a91e0059fe9c3f2559a9825b4e10bd
KEY_UP: g350_KEY_UP_0916888e0351f9520fba7b321c22fd12
KEY_X: g350_KEY_X_24e3d1005bc3e93f23945c825d135dbd
KEY_Y: g350_KEY_Y_7d79776001dece617ec8ebde008f59e3
L_CORE: 2.2µH; g350_L_CORE_203d24727752dd8e0ee2df8e598d1e72
L_DDR: 2.2µH; g350_L_DDR_5915dbc043ae1dbf2e465fbe18dea1bd
L_IO_BOOST: 2.2µH; g350_L_IO_BOOST_1c63c1847b2c407c12bc427c55b3bb84
L_MPU: 2.2µH; g350_L_MPU_1f7eddc0781124400fa1264058ced7c0
L_SD_REG: 2.2µH; g350_L_SD_REG_782275006dc49f5f6366c9be5908f41d
R_AUDIO_PD: 100kΩ; g350_R_AUDIO_PD_705229de63e9a7fe5781261e4b18a43e
R_CPU_POR: 100kΩ; g350_R_CPU_POR_0e96d7361aff59162767daf633d05cd6
R_DDR_VTP: 49.9Ω; g350_R_DDR_VTP_62afb6fc0900bb4474b12d841f9e603c
R_DDR_ZQ: 240Ω; g350_R_DDR_ZQ_40decdb82ad1a488697de93802328908
R_EMU0: 4.7kΩ; g350_R_EMU0_2cf14140789e80df1e2e42fe3c41fae3
R_EMU1: 4.7kΩ; g350_R_EMU1_26ad8ce07ee2353f2471f75e35fe4683
R_IO_BOOST_HI: 732kΩ; g350_R_IO_BOOST_HI_3a67717a2e088c866987757a0117777a
R_IO_BOOST_LO: 100kΩ; g350_R_IO_BOOST_LO_382fb6fc30404704674fbafc01204304
R_KEYS_RESET: 10kΩ; g350_R_KEYS_RESET_7fef33c00096edff7ec157c201e6627d
R_PMIC_INT: 10kΩ; g350_R_PMIC_INT_0a53a33e5e1c5ac23973a73e2efc56c2
R_PMIC_RESET: 100kΩ; g350_R_PMIC_RESET_50336474183c998c7f53687416e36a74
R_PMIC_SCL: 4.7kΩ; g350_R_PMIC_SCL_17264e325149afce464652322229abce
R_PMIC_SDA: 4.7kΩ; g350_R_PMIC_SDA_10bcf8b857b305483fdcfcb828930148
R_PMIC_WAKEUP: 100kΩ; g350_R_PMIC_WAKEUP_03ea4dc46485b03c330a51c43565ac3c
R_SD_CD: 10kΩ; g350_R_SD_CD_782b85267b6bf8fa6f03771a629af53a
R_SD_CLK: 33Ω; g350_R_SD_CLK_6b5b0ea0154cab9f6a0b9a22169c201d
R_SD_CMD: 10kΩ; g350_R_SD_CMD_41a93f283540bd4828d83b681c6fb988
R_SD_DAT0: 10kΩ; g350_R_SD_DAT0_380336f0446bb8d050d43ab05d3cbc90
R_SD_DAT1: 10kΩ; g350_R_SD_DAT1_2667e69619ff64b60d96e2d6012e60f6
R_SD_DAT2: 10kΩ; g350_R_SD_DAT2_7b2cfbe4786a823c6c02005c5f997e7c
R_SD_DAT3: 10kΩ; g350_R_SD_DAT3_1cc1de5e292a603e3592e21e41fb63fe
R_SYSBOOT0: 10kΩ; g350_R_SYSBOOT0_77f1a8847ba5d59c6f3d53bc62d4d1dc
R_SYSBOOT1: 10kΩ; g350_R_SYSBOOT1_0701a252136a24321fd2a6122c3b27f2
R_SYSBOOT2: 10kΩ; g350_R_SYSBOOT2_65bec8b6595646d64cedc4f640854316
R_SYSBOOT3: 10kΩ; g350_R_SYSBOOT3_4e46d6185aaf57f86717d9d873805bb8
R_SYSBOOT4: 10kΩ; g350_R_SYSBOOT4_6439765c301617643b9a5adc58b532e4
R_SYSBOOT5: 10kΩ; g350_R_SYSBOOT5_23f8d23247b7a00e4c97edb21f18848e
R_SYSBOOT6: 10kΩ; g350_R_SYSBOOT6_12f805d67ea8781615a715aa56095c96
R_SYSBOOT7: 10kΩ; g350_R_SYSBOOT7_49e8ddde4a66afe22149c25e7305cb62
R_SYSBOOT8: 10kΩ; g350_R_SYSBOOT8_15268114218f02f42df784d43a6006b4
R_SYSBOOT9: 10kΩ; g350_R_SYSBOOT9_5bc9851e4f61033e42f8815e368fff7e
R_SYSBOOT10: 10kΩ; g350_R_SYSBOOT10_37760fda43de91ba5047139a5caf957a
R_SYSBOOT11: 10kΩ; g350_R_SYSBOOT11_354a5b2e28e1d94e1c79576e1010d58e
R_SYSBOOT12: 10kΩ; g350_R_SYSBOOT12_092c996274dd0ba21f72821e4c3df022
R_SYSBOOT13: 10kΩ; g350_R_SYSBOOT13_40256b3e542a228217864fbe7cc93e02
R_SYSBOOT14: 10kΩ; g350_R_SYSBOOT14_771643461d394a7a4e7727c645d865fa
R_SYSBOOT15: 10kΩ; g350_R_SYSBOOT15_51f8e4b219b78d8e7a9800320ee78df2
R_TCK: 4.7kΩ; g350_R_TCK_2eaaa4542242227415d9a09409711eb4
R_TDI: 4.7kΩ; g350_R_TDI_6ba285d65f3a03f652d1821646690036
R_TMS: 4.7kΩ; g350_R_TMS_2069d8807ada16612ab5abbe2fba9223
R_TRSTn: 4.7kΩ; g350_R_TRSTn_0e4d3d2e1ab5bf0e271e40ee3386c2ce
R_USB_CC1: 5.1kΩ; g350_R_USB_CC1_6c2a3bec5fc1ba0c5359382c46f0b64c
R_USB_CC2: 5.1kΩ; g350_R_USB_CC2_7766f5547c3088cc6fc806ec635f850c
R_USB_VBUS_SENSE: 1.2kΩ; g350_R_USB_VBUS_SENSE_38e6c8ac2c7e46cc2015c4ec13ad430c
R_VREF_HI: 10kΩ; g350_R_VREF_HI_49987f021ed77efe78b8830210488502
R_VREF_LO: 10kΩ; g350_R_VREF_LO_02b097ae6b2095ae2c6f6c523c0091ae
R_WARMRSTn: 4.7kΩ; g350_R_WARMRSTn_4b451eb057ada09064162270707ea450
R_XTAL_BIAS_DNP: 1MΩ; g350_R_XTAL_BIAS_DNP_4830bf5a4c1ece661f91a3da74bde9e6
R_XTAL_DAMP: 0Ω; g350_R_XTAL_DAMP_59294d0817cc6ea829906fb86aed4e18
SW_POWER: SW_POWER; g350_SW_POWER_6cca27007dce1aff68665cfe52fe9efd
SW_RESET: SW_RESET; g350_SW_RESET_1b7dd7800f1555a002acd3c009bbae20
TP_BAT_GND: TP_BAT_GND; g350_TP_BAT_GND_4b2787b64c687a4a1c0783b67b887e4a
TP_BAT_INPUT: TP_BAT_INPUT; g350_TP_BAT_INPUT_56e5ca2e40aa37d227c5c62e6fca3bd2
TP_BAT_NTC: TP_BAT_NTC; g350_TP_BAT_NTC_5106a8f24689590e21e6a4f275a95d0e
TP_GND: TP_GND; g350_TP_GND_7357bb6c7fc03d4c73d740d4676ebef4
TP_IO_3V3: TP_IO_3V3; g350_TP_IO_3V3_06da58721342da521fab5c322c13de12
TP_JTAG_EMU0: TP_JTAG_EMU0; g350_TP_JTAG_EMU0_0fb1768c0348f4ac091f8d3415880f14
TP_JTAG_EMU1: TP_JTAG_EMU1; g350_TP_JTAG_EMU1_302df6783c96785848fefa3855677c18
TP_JTAG_TCK: TP_JTAG_TCK; g350_TP_JTAG_TCK_52db3b804672b9a03a0a37c02da1b5e0
TP_JTAG_TDI: TP_JTAG_TDI; g350_TP_JTAG_TDI_263d458a19d4c3aa0d6c41ca0103bfea
TP_JTAG_TDO: TP_JTAG_TDO; g350_TP_JTAG_TDO_19a2277a260aa95a32732b3a3edbad1a
TP_JTAG_TMS: TP_JTAG_TMS; g350_TP_JTAG_TMS_46401d7052a89f505f1121306b79a310
TP_JTAG_TRSTn: TP_JTAG_TRSTn; g350_TP_JTAG_TRSTn_5ccbec6e69346e4e759cf02e7dfa8df2
TP_SPK_N: TP_SPK_N; g350_TP_SPK_N_6f1a1000118daa3f6dca9b8212dd1ebd
TP_SPK_P: TP_SPK_P; g350_TP_SPK_P_623463ce55cbe1ee4963600e3cfade2e
TP_UART_GND: TP_UART_GND; g350_TP_UART_GND_4374da44370c58642aa3d6841e3b54a4
TP_UART_IO_3V3: TP_UART_IO_3V3; g350_TP_UART_IO_3V3_37926c4c2b29ea6c1ec1688c1258e6ac
TP_UART_UART0_RX: TP_UART_UART0_RX; g350_TP_UART_UART0_RX_6f91774e6328f56e56c0738e4a57f1ae
TP_UART_UART0_TX: TP_UART_UART0_TX; g350_TP_UART_UART0_TX_6451eba870ba6d887d22ef6876748eb8
TP_USB_INPUT: TP_USB_INPUT; g350_TP_USB_INPUT_44caabc05a3269c16f9a27c27afe1a3d
TP_WARM_RESETn: TP_WARM_RESETn; g350_TP_WARM_RESETn_3c4f6c822fe6eaa2237e68c21715e6e2
U_AUDIO: MAX98357AETE+T; g350_U_AUDIO_682f4a401728fb81697ebebe15d98703
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

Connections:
ANALOG_1V8: C_HV1_1.1, C_HV1_2.1, C_HV1_BULK.1, C_HV2_1.1, C_HV2_2.1, C_HV2_BULK.1, C_HV3_1.1, C_HV3_2.1, C_HV3_BULK.1, C_PMIC_ANALOG_OUT.1, C_SRAM_CORE_1.1, C_SRAM_CORE_BULK.1, C_SRAM_MPU_1.1, C_SRAM_MPU_BULK.1, C_VDDA1P8V_USB0.1, C_VDDA1P8V_USB1.1, C_VDDS_OSC.1, C_VDDS_PLL_CORE_LCD.1, C_VDDS_PLL_DDR.1, C_VDDS_PLL_MPU.1, U_PMIC.40, U_SOC.113, U_SOC.122, U_SOC.140, U_SOC.149, U_SOC.166, U_SOC.176, U_SOC.177, U_SOC.194, U_SOC.195, U_SOC.212, U_SOC.230, U_SOC.260, U_SOC.283, U_SOC.285
AUDIO_BCLK: U_AUDIO.16, U_SOC.217
AUDIO_DIN: U_AUDIO.1, U_SOC.202
AUDIO_ENABLE: R_AUDIO_PD.1, U_AUDIO.4, U_SOC.235
AUDIO_LRCLK: U_AUDIO.14, U_SOC.218
BAT_NTC: TP_BAT_NTC.1, U_PMIC.11
CAP_VBB_MPU: C_CAP_VBB_MPU.1, U_SOC.165
CAP_VDD_RTC: C_CAP_VDD_RTC.1, U_SOC.94
CAP_VDD_SRAM_CORE: C_CAP_VDD_SRAM_CORE.1, U_SOC.148
CAP_VDD_SRAM_MPU: C_CAP_VDD_SRAM_MPU.1, U_SOC.184
CPU_PORn: R_CPU_POR.2, U_POR.1, U_SOC.254
DDR_1V5: C_DDR_CPU_1.1, C_DDR_CPU_2.1, C_DDR_CPU_3.1, C_DDR_CPU_4.1, C_DDR_CPU_5.1, C_DDR_CPU_6.1, C_DDR_CPU_7.1, C_DDR_CPU_8.1, C_DDR_CPU_9.1, C_DDR_CPU_10.1, C_DDR_CPU_11.1, C_DDR_CPU_12.1, C_DDR_CPU_13.1, C_DDR_CPU_14.1, C_DDR_CPU_15.1, C_DDR_CPU_16.1, C_DDR_CPU_17.1, C_DDR_CPU_18.1, C_DDR_CPU_19.1, C_DDR_CPU_20.1, C_DDR_CPU_BULK1.1, C_DDR_CPU_BULK2.1, C_DDR_RAM_1.1, C_DDR_RAM_2.1, C_DDR_RAM_3.1, C_DDR_RAM_4.1, C_DDR_RAM_5.1, C_DDR_RAM_6.1, C_DDR_RAM_7.1, C_DDR_RAM_8.1, C_DDR_RAM_9.1, C_DDR_RAM_10.1, C_DDR_RAM_11.1, C_DDR_RAM_12.1, C_DDR_RAM_BULK1.1, C_DDR_RAM_BULK2.1, C_PMIC_DDR_OUT.1, L_DDR.2, R_VREF_HI.1, U_PMIC.19, U_RAM.1, U_RAM.3, U_RAM.6, U_RAM.13, U_RAM.15, U_RAM.18, U_RAM.20, U_RAM.24, U_RAM.26, U_RAM.55, U_RAM.65, U_RAM.74, U_RAM.83, U_RAM.84, U_RAM.85, U_RAM.88, U_RAM.93, U_RAM.95, U_SOC.77, U_SOC.78, U_SOC.79, U_SOC.80, U_SOC.81, U_SOC.82, U_SOC.83
DDR_VREF: C_VREF_CPU.1, C_VREF_RAM_CA.1, C_VREF_RAM_DQ.1, R_VREF_HI.2, R_VREF_LO.1, U_RAM.8, U_RAM.76, U_SOC.63
DDR_VTP: R_DDR_VTP.1, U_SOC.45
DDR_ZQ: R_DDR_ZQ.1, U_RAM.75
GND: C_AUDIO_BULK.2, C_AUDIO_HF.2, C_BATTERY.2, C_CAP_VBB_MPU.2, C_CAP_VDD_RTC.2, C_CAP_VDD_SRAM_CORE.2, C_CAP_VDD_SRAM_MPU.2, C_CORE_1.2, C_CORE_2.2, C_CORE_3.2, C_CORE_4.2, C_CORE_5.2, C_CORE_6.2, C_CORE_7.2, C_CORE_8.2, C_CORE_BULK.2, C_DDR_CPU_1.2, C_DDR_CPU_2.2, C_DDR_CPU_3.2, C_DDR_CPU_4.2, C_DDR_CPU_5.2, C_DDR_CPU_6.2, C_DDR_CPU_7.2, C_DDR_CPU_8.2, C_DDR_CPU_9.2, C_DDR_CPU_10.2, C_DDR_CPU_11.2, C_DDR_CPU_12.2, C_DDR_CPU_13.2, C_DDR_CPU_14.2, C_DDR_CPU_15.2, C_DDR_CPU_16.2, C_DDR_CPU_17.2, C_DDR_CPU_18.2, C_DDR_CPU_19.2, C_DDR_CPU_20.2, C_DDR_CPU_BULK1.2, C_DDR_CPU_BULK2.2, C_DDR_RAM_1.2, C_DDR_RAM_2.2, C_DDR_RAM_3.2, C_DDR_RAM_4.2, C_DDR_RAM_5.2, C_DDR_RAM_6.2, C_DDR_RAM_7.2, C_DDR_RAM_8.2, C_DDR_RAM_9.2, C_DDR_RAM_10.2, C_DDR_RAM_11.2, C_DDR_RAM_12.2, C_DDR_RAM_BULK1.2, C_DDR_RAM_BULK2.2, C_HV1_1.2, C_HV1_2.2, C_HV1_BULK.2, C_HV2_1.2, C_HV2_2.2, C_HV2_BULK.2, C_HV3_1.2, C_HV3_2.2, C_HV3_BULK.2, C_HV4_1.2, C_HV4_2.2, C_HV4_BULK.2, C_HV5_1.2, C_HV5_2.2, C_HV5_BULK.2, C_HV6_1.2, C_HV6_2.2, C_HV6_3.2, C_HV6_4.2, C_HV6_5.2, C_HV6_6.2, C_HV6_BULK.2, C_IO_BOOST_IN.2, C_IO_BOOST_OUT1.2, C_IO_BOOST_OUT2.2, C_KEYS_BULK.2, C_KEYS_HF.2, C_MPU_1.2, C_MPU_2.2, C_MPU_3.2, C_MPU_4.2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
I2C0_SCL: R_PMIC_SCL.2, U_KEYS.12, U_PMIC.28, U_SOC.273
I2C0_SDA: R_PMIC_SDA.2, U_KEYS.13, U_PMIC.27, U_SOC.291
IO_3V3: C_HV5_1.1, C_HV5_2.1, C_HV5_BULK.1, C_HV6_1.1, C_HV6_2.1, C_HV6_3.1, C_HV6_4.1, C_HV6_5.1, C_HV6_6.1, C_HV6_BULK.1, C_KEYS_BULK.1, C_KEYS_HF.1, C_PMIC_IO_OUT.1, C_VDDA3P3V_USB0.1, C_VDDA3P3V_USB1.1, R_EMU0.1, R_EMU1.1, R_KEYS_RESET.1, R_PMIC_INT.1, R_PMIC_SCL.1, R_PMIC_SDA.1, R_SD_CD.1, R_SYSBOOT0.1, R_SYSBOOT1.1, R_SYSBOOT2.1, R_SYSBOOT4.1, R_SYSBOOT14.1, R_TDI.1, R_TMS.1, R_WARMRSTn.1, TP_IO_3V3.1, TP_UART_IO_3V3.1, U_KEYS.9, U_PMIC.43, U_SD_REG.3, U_SOC.85, U_SOC.86, U_SOC.104, U_SOC.167, U_SOC.185, U_SOC.203, U_SOC.221, U_SOC.240, U_SOC.241, U_SOC.244, U_SOC.245, U_SOC.265, U_SOC.267
IO_BOOST_FB: C_IO_BOOST_FF.2, R_IO_BOOST_HI.2, R_IO_BOOST_LO.1, U_IO_BOOST.1
IO_BOOST_SW: L_IO_BOOST.2, U_IO_BOOST.5
JTAG_EMU0: R_EMU0.2, TP_JTAG_EMU0.1, U_SOC.237
JTAG_EMU1: R_EMU1.2, TP_JTAG_EMU1.1, U_SOC.236
JTAG_TCK: R_TCK.2, TP_JTAG_TCK.1, U_SOC.199
JTAG_TDI: R_TDI.2, TP_JTAG_TDI.1, U_SOC.182
JTAG_TDO: TP_JTAG_TDO.1, U_SOC.181
JTAG_TMS: R_TMS.2, TP_JTAG_TMS.1, U_SOC.183
JTAG_TRSTn: R_TRSTn.2, TP_JTAG_TRSTn.1, U_SOC.164
KEYS_RESETn: R_KEYS_RESET.2, U_KEYS.18
KEY_A.pin1 to U_KEYS.GPA4: KEY_A.1, U_KEYS.25
KEY_B.pin1 to U_KEYS.GPA5: KEY_B.1, U_KEYS.26
KEY_DOWN.pin1 to U_KEYS.GPA1: KEY_DOWN.1, U_KEYS.22
KEY_LEFT.pin1 to U_KEYS.GPA2: KEY_LEFT.1, U_KEYS.23
KEY_MENU.pin1 to U_KEYS.GPB2: KEY_MENU.1, U_KEYS.3
KEY_RIGHT.pin1 to U_KEYS.GPA3: KEY_RIGHT.1, U_KEYS.24
KEY_SELECT.pin1 to U_KEYS.GPB0: KEY_SELECT.1, U_KEYS.1
KEY_START.pin1 to U_KEYS.GPB1: KEY_START.1, U_KEYS.2
KEY_UP.pin1 to U_KEYS.GPA0: KEY_UP.1, U_KEYS.21
KEY_X.pin1 to U_KEYS.GPA6: KEY_X.1, U_KEYS.27
KEY_Y.pin1 to U_KEYS.GPB3: KEY_Y.1, U_KEYS.4
LCD_DATA0: R_SYSBOOT0.2, U_SOC.15
LCD_DATA1: R_SYSBOOT1.2, U_SOC.33
LCD_DATA2: R_SYSBOOT2.2, U_SOC.51
LCD_DATA3: R_SYSBOOT3.2, U_SOC.69
LCD_DATA4: R_SYSBOOT4.2, U_SOC.16
LCD_DATA5: R_SYSBOOT5.2, U_SOC.34
LCD_DATA6: R_SYSBOOT6.2, U_SOC.52
LCD_DATA7: R_SYSBOOT7.2, U_SOC.70
LCD_DATA8: R_SYSBOOT8.2, U_SOC.17
LCD_DATA9: R_SYSBOOT9.2, U_SOC.35
LCD_DATA10: R_SYSBOOT10.2, U_SOC.53
LCD_DATA11: R_SYSBOOT11.2, U_SOC.71
LCD_DATA12: R_SYSBOOT12.2, U_SOC.36
LCD_DATA13: R_SYSBOOT13.2, U_SOC.54
LCD_DATA14: R_SYSBOOT14.2, U_SOC.72
LCD_DATA15: R_SYSBOOT15.2, U_SOC.88
LDO2_3V3: C_PMIC_LDO2.1, U_PMIC.1
PERIPH_3V3: C_AUDIO_BULK.1, C_AUDIO_HF.1, C_HV4_1.1, C_HV4_2.1, C_HV4_BULK.1, C_POR_SENSE.1, C_SD_REG_OUT.1, C_SD_SOCKET_BULK.1, C_SD_SOCKET_HF.1, J_SD.4, L_SD_REG.2, R_SD_CMD.1, R_SD_DAT0.1, R_SD_DAT1.1, R_SD_DAT2.1, R_SD_DAT3.1, U_AUDIO.2, U_AUDIO.7, U_AUDIO.8, U_POR.5, U_SD_REG.6, U_SOC.242, U_SOC.243
PERIPH_SW: L_SD_REG.1, U_SD_REG.7
PMIC_BUTTONn: SW_POWER.1, U_PMIC.25
PMIC_BYPASS: C_PMIC_BYPASS.1, U_PMIC.47
PMIC_ENABLE: U_PMIC.9, U_SOC.93
PMIC_INT_LDO: C_PMIC_INT_LDO.1, U_PMIC.48
PMIC_INTn: R_PMIC_INT.2, U_PMIC.45, U_SOC.308
PMIC_MAIN_PGOOD: U_PMIC.26, U_POR.3
PMIC_RESETn: R_PMIC_RESET.2, U_PMIC.44
PMIC_WAKEUPn: R_PMIC_WAKEUP.2, U_PMIC.13, U_SOC.75
RTC_PORn: U_PMIC.46, U_SOC.74
SD_CD: J_SD.9, R_SD_CD.2, U_SOC.309
SD_CLK_CARD: J_SD.5, R_SD_CLK.2
SD_CLK_CPU: R_SD_CLK.1, U_SOC.295
SD_CMD: J_SD.3, R_SD_CMD.2, U_SOC.313
SD_DAT0: J_SD.7, R_SD_DAT0.2, U_SOC.277
SD_DAT1: J_SD.8, R_SD_DAT1.2, U_SOC.259
SD_DAT2: J_SD.1, R_SD_DAT2.2, U_SOC.312
SD_DAT3: J_SD.2, R_SD_DAT3.2, U_SOC.294
SPK_N: TP_SPK_N.1, U_AUDIO.10
SPK_P: TP_SPK_P.1, U_AUDIO.9
SW_CORE: L_CORE.1, U_PMIC.31
SW_DDR: L_DDR.1, U_PMIC.20
SW_MPU: L_MPU.1, U_PMIC.23
UART0_RX: TP_UART_UART0_RX.1, U_SOC.257
UART0_TX: TP_UART_UART0_TX.1, U_SOC.275
USB0_DM: J_USB.7, J_USB.9, U_SOC.319, U_USB_ESD.1, U_USB_ESD.6
USB0_DP: J_USB.8, J_USB.10, U_SOC.301, U_USB_ESD.3, U_USB_ESD.4
USB0_VBUS_SENSE: C_USB_VBUS_SENSE.1, D_USB_VBUS_SENSE.1, R_USB_VBUS_SENSE.2, U_SOC.266
USB_5V: C_PMIC_USB.1, C_USB_ESD.1, J_USB.15, J_USB.16, R_USB_VBUS_SENSE.1, TP_USB_INPUT.1, U_PMIC.12, U_USB_ESD.5
USB_CC1: J_USB.6, R_USB_CC1.1
USB_CC2: J_USB.12, R_USB_CC2.1
U_SOC.pin2 to U_RAM.pin30: U_RAM.30, U_SOC.2
U_SOC.pin3 to U_RAM.pin47: U_RAM.47, U_SOC.3
U_SOC.pin4 to U_RAM.pin58: U_RAM.58, U_SOC.4
U_SOC.pin5 to U_RAM.pin77: U_RAM.77, U_SOC.5
U_SOC.pin6 to U_RAM.pin42: U_RAM.42, U_SOC.6
U_SOC.pin7 to U_RAM.pin10: U_RAM.10, U_SOC.7
U_SOC.pin8 to U_RAM.pin62: U_RAM.62, U_SOC.8
U_SOC.pin9 to U_RAM.pin67: U_RAM.67, U_SOC.9
U_SOC.pin10 to U_RAM.pin49: U_RAM.49, U_SOC.10
U_SOC.pin11 to U_RAM.pin51: U_RAM.51, U_SOC.11
U_SOC.pin12 to U_RAM.pin66: U_RAM.66, U_SOC.12
U_SOC.pin13 to U_RAM.pin37: U_RAM.37, U_SOC.13
U_SOC.pin14 to U_RAM.pin38: U_RAM.38, U_SOC.14
U_SOC.pin20 to U_RAM.pin43: U_RAM.43, U_SOC.20
U_SOC.pin21 to U_RAM.pin78: U_RAM.78, U_SOC.21
U_SOC.pin22 to U_RAM.pin57: U_RAM.57, U_SOC.22
U_SOC.pin23 to U_RAM.pin31: U_RAM.31, U_SOC.23
U_SOC.pin24 to U_RAM.pin63: U_RAM.63, U_SOC.24
U_SOC.pin25 to U_RAM.pin32: U_RAM.32, U_SOC.25
U_SOC.pin26 to U_RAM.pin27: U_RAM.27, U_SOC.26
U_SOC.pin27 to U_RAM.pin36: U_RAM.36, U_SOC.27
U_SOC.pin28 to U_RAM.pin35: U_RAM.35, U_SOC.28
U_SOC.pin29 to U_RAM.pin50: U_RAM.50, U_SOC.29
U_SOC.pin30 to U_RAM.pin53: U_RAM.53, U_SOC.30
U_SOC.pin31 to U_RAM.pin40: U_RAM.40, U_SOC.31
U_SOC.pin32 to U_RAM.pin39: U_RAM.39, U_SOC.32
U_SOC.pin38 to U_RAM.pin44: U_RAM.44, U_SOC.38
U_SOC.pin39 to U_RAM.pin29: U_RAM.29, U_SOC.39
U_SOC.pin41 to U_RAM.pin61: U_RAM.61, U_SOC.41
U_SOC.pin42 to U_RAM.pin45: U_RAM.45, U_SOC.42
U_SOC.pin43 to U_RAM.pin90: U_RAM.90, U_SOC.43
U_SOC.pin44 to U_RAM.pin48: U_RAM.48, U_SOC.44
U_SOC.pin46 to U_RAM.pin17: U_RAM.17, U_SOC.46
U_SOC.pin47 to U_RAM.pin19: U_RAM.19, U_SOC.47
U_SOC.pin48 to U_RAM.pin22: U_RAM.22, U_SOC.48
U_SOC.pin49 to U_RAM.pin54: U_RAM.54, U_SOC.49
U_SOC.pin50 to U_RAM.pin70: U_RAM.70, U_SOC.50
U_SOC.pin57 to U_RAM.pin28: U_RAM.28, U_SOC.57
U_SOC.pin58 to U_RAM.pin80: U_RAM.80, U_SOC.58
U_SOC.pin59 to U_RAM.pin46: U_RAM.46, U_SOC.59
U_SOC.pin60 to U_RAM.pin59: U_RAM.59, U_SOC.60
U_SOC.pin61 to U_RAM.pin41: U_RAM.41, U_SOC.61
U_SOC.pin62 to U_RAM.pin64: U_RAM.64, U_SOC.62
U_SOC.pin64 to U_RAM.pin52: U_RAM.52, U_SOC.64
U_SOC.pin65 to U_RAM.pin33: U_RAM.33, U_SOC.65
U_SOC.pin66 to U_RAM.pin72: U_RAM.72, U_SOC.66
U_SOC.pin67 to U_RAM.pin23: U_RAM.23, U_SOC.67
U_SOC.pin68 to U_RAM.pin56: U_RAM.56, U_SOC.68
U_SOC.pin76 to U_RAM.pin79: U_RAM.79, U_SOC.76
VBAT: C_BATTERY.1, TP_BAT_INPUT.1, U_PMIC.4, U_PMIC.5, U_PMIC.6
VDDS_1V8: C_PMIC_LDO1.1, C_POR_BYPASS.1, C_VDDS_1.1, C_VDDS_2.1, C_VDDS_3.1, C_VDDS_4.1, C_VDDS_BULK.1, C_VDDS_RTC.1, R_CPU_POR.1, R_PMIC_RESET.1, R_PMIC_WAKEUP.1, U_PMIC.3, U_PMIC.18, U_POR.6, U_SOC.95, U_SOC.103, U_SOC.112, U_SOC.150, U_SOC.158, U_SOC.226, U_SOC.239, U_SOC.248
VDD_CORE: C_CORE_1.1, C_CORE_2.1, C_CORE_3.1, C_CORE_4.1, C_CORE_5.1, C_CORE_6.1, C_CORE_7.1, C_CORE_8.1, C_CORE_BULK.1, C_PMIC_CORE_OUT.1, L_CORE.2, U_PMIC.29, U_SOC.96, U_SOC.97, U_SOC.100, U_SOC.101, U_SOC.114, U_SOC.115, U_SOC.119, U_SOC.136, U_SOC.137, U_SOC.139, U_SOC.155, U_SOC.157, U_SOC.169, U_SOC.188, U_SOC.192, U_SOC.207, U_SOC.208, U_SOC.211, U_SOC.228, U_SOC.229
VDD_MPU: C_MPU_1.1, C_MPU_2.1, C_MPU_3.1, C_MPU_4.1, C_MPU_5.1, C_MPU_BULK.1, C_PMIC_MPU_OUT.1, L_MPU.2, U_PMIC.24, U_SOC.19, U_SOC.168, U_SOC.186, U_SOC.204, U_SOC.222, U_SOC.223, U_SOC.224, U_SOC.225
VIO_BOOST5V: C_IO_BOOST_FF.1, C_IO_BOOST_OUT1.1, C_IO_BOOST_OUT2.1, C_PMIC_VINLDO.1, C_SD_REG_HF.1, C_SD_REG_IN.1, R_IO_BOOST_HI.1, U_IO_BOOST.6, U_PMIC.2, U_PMIC.42, U_SD_REG.2
VSYS: C_IO_BOOST_IN.1, C_PMIC_DCDC1_IN.1, C_PMIC_DCDC2_IN.1, C_PMIC_DCDC3_IN.1, C_PMIC_SYS.1, L_IO_BOOST.1, U_IO_BOOST.2, U_IO_BOOST.3, U_PMIC.7, U_PMIC.8, U_PMIC.21, U_PMIC.22, U_PMIC.32, U_PMIC.39
WARM_RESETn: R_WARMRSTn.2, SW_RESET.1, TP_WARM_RESETn.1, U_SOC.163
XTAL_DRIVE: C_XTAL_OUT.1, R_XTAL_DAMP.2, X_MAIN.3
XTAL_IN: C_XTAL_IN.1, R_XTAL_BIAS_DNP.1, U_SOC.180, X_MAIN.1
XTAL_OUT: R_XTAL_BIAS_DNP.2, R_XTAL_DAMP.1, U_SOC.197

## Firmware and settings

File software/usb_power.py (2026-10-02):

#!/usr/bin/env python3
"""Select BQ24074 USB100/USB500/suspend for this carrier's own gadget."""
import logging
from pathlib import Path
import signal
import time

GADGET = Path("/sys/kernel/config/usb_gadget/g350")


def charger_mode(state, declared_ma, own_gadget):
    # GPIO24 -> EN1, GPIO16 -> EN2. BQ24074 table 7-2.
    # Never infer a 500 mA allowance just from VBUS or a random UDC.
    if state == "suspended":
        return True, True
    if own_gadget and state == "configured" and declared_ma == 500:
        return True, False
    return False, False


def usb_status():
    try:
        udc = (GADGET / "UDC").read_text().strip()
        if not udc or "/" in udc:
            return "not attached", 0, False
        state = (Path("/sys/class/udc") / udc / "state").read_text().strip()
        ma = int((GADGET / "configs/c.1/MaxPower").read_text().strip())
        return state, ma, True
    except (OSError, ValueError):
        return "not attached", 0, False


def set_charger_mode(en1, en2, mode):
    # Keep EN2 low unless EN1 is already high. This avoids the
    # EN1=0/EN2=1 resistor-limit mode during sequential GPIO writes.
    if mode == (True, True):
        en1.on()
        en2.on()
    elif mode == (True, False):
        en2.off()
        en1.on()
    else:
        en2.off()
        en1.off()


def sync_gadget_connection(has_usb_power):
    """Bind only this gadget, using the charger's real VBUS status on GPIO12."""
    try:
        binding = GADGET / "UDC"
        udc = binding.read_text().strip()
        if not has_usb_power:
            if udc:
                binding.write_text("\n")
            return False
        if not udc:
            controllers = list(Path("/sys/class/udc").iterdir())
            if len(controllers) != 1:
                return False
            binding.write_text(controllers[0].name + "\n")
        return True
    except OSError:
        return False


def main():
    from gpiozero import DigitalOutputDevice, DigitalInputDevice
    def stop_service(signum, frame):
        raise KeyboardInterrupt

    signal.signal(signal.SIGTERM, stop_service)
    logging.basicConfig(level=logging.INFO)
    with DigitalOutputDevice(16, initial_value=False) as en2, \
         DigitalOutputDevice(24, initial_value=False) as en1, \
         DigitalInputDevice(12, pull_up=None, active_state=False) as usb_good:
        previous = None
        try:
            while True:
                connected = sync_gadget_connection(bool(usb_good.value))
                state, ma, own = usb_status()
                mode = charger_mode(state, ma, own) if connected else (False, False)
                set_charger_mode(en1, en2, mode)
                if mode != previous:
                    logging.info("USB state %s; charger EN1=%s EN2=%s", state, *mode)
                    previous = mode
                time.sleep(0.005)
        except KeyboardInterrupt:
            pass
        finally:
            sync_gadget_connection(False)
            set_charger_mode(en1, en2, (False, False))


if __name__ == "__main__":
    main()

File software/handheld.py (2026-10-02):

#!/usr/bin/env python3
"""G350 carrier input daemon. Target hardware only; does not configure display."""
import logging
import time

from evdev import UInput, ecodes as e
from gpiozero import DigitalOutputDevice, DigitalInputDevice
from smbus2 import SMBus

BUTTONS = [e.BTN_DPAD_UP, e.BTN_DPAD_DOWN, e.BTN_DPAD_LEFT, e.BTN_DPAD_RIGHT,
           e.BTN_EAST, e.BTN_SOUTH, e.BTN_NORTH, e.BTN_WEST,
           e.BTN_SELECT, e.BTN_START, e.BTN_MODE]
MASK = (1 << len(BUTTONS)) - 1
# Logical button order follows the PCB; GPA7 and GPB7 are output-only.
BUTTON_PORT_BITS = (0, 1, 2, 3, 4, 5, 6, 11, 8, 9, 10)


def pressed_from_ports(a, b):
    active = (~(a | (b << 8))) & 0xFFFF
    return sum(((active >> bit) & 1) << i
               for i, bit in enumerate(BUTTON_PORT_BITS)) & MASK


def voltage(bus):
    high, low = bus.read_i2c_block_data(0x36, 0x02, 2)
    return ((high << 8) | low) * 0.000078125


def main():
    logging.basicConfig(level=logging.INFO)
    # Physical J8 37 = BCM26. GPIO default low suppresses boot noise.
    with DigitalOutputDevice(26, initial_value=False) as amplifier, \
         DigitalInputDevice(5, pull_up=None, active_state=False) as charging, \
         SMBus(1) as bus, \
         UInput({e.EV_KEY: BUTTONS}, name="G350 front controls") as gamepad:
        # Reset power-on BANK=0 configuration; internal pullups yield active-low keys.
        bus.write_byte_data(0x20, 0x0A, 0x00)
        # Keep the unused output-only bit 7 low on both ports.
        bus.write_byte_data(0x20, 0x14, 0x00)
        bus.write_byte_data(0x20, 0x15, 0x00)
        bus.write_byte_data(0x20, 0x00, 0x7F)
        bus.write_byte_data(0x20, 0x01, 0x7F)
        bus.write_byte_data(0x20, 0x0C, 0x7F)
        bus.write_byte_data(0x20, 0x0D, 0x7F)
        stable = candidate = 0
        changed_at = last_battery = time.monotonic()
        amplifier.on()
        try:
            while True:
                now = time.monotonic()
                a, b = bus.read_i2c_block_data(0x20, 0x12, 2)
                pressed = pressed_from_ports(a, b)
                if pressed != candidate:
                    candidate, changed_at = pressed, now
                if candidate != stable and now - changed_at >= 0.008:
                    changes = stable ^ candidate
                    for i, key in enumerate(BUTTONS):
                        if changes & (1 << i):
                            gamepad.write(e.EV_KEY, key, int(bool(candidate & (1 << i))))
                    gamepad.syn()
                    stable = candidate
                if now - last_battery >= 30:
                    v = voltage(bus)
                    logging.info("Battery %.3f V; charging=%s", v, charging.value)
                    if v < 3.2:
                        logging.warning("Low battery: exit your game and shut Linux down.")
                    last_battery = now
                time.sleep(1 / 150)
        finally:
            amplifier.off()
            for key in BUTTONS:
                gamepad.write(e.EV_KEY, key, 0)
            gamepad.syn()


if __name__ == "__main__":
    main()

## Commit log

2026-10-02 Refine phased routing and correct controller input pins
    [handheld.py]
2026-10-02 Route critical audio, thermistor and display reset connections manually
2026-10-02 Release checked four-layer FPC Linux handheld prototype
    [bom-jlcpcb.csv, bom-manual.csv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]
2026-10-02 Bundle exact footprint library and require zero DRC violations
    [index-B_Cu.gbl, index-B_Mask.gbs, index-B_Paste.gbp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]
2026-10-02 Release top-only Rev B carrier with shared USB-C charging and data
    [USBLC6_2SC6.obj, USBLC6_2SC6.step, bom-jlcpcb.csv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]
2026-10-02 Integrate bare AM3352 power source and verify native DDR byte0 with bypass parts
2026-10-02 Compact integrated DDR diagnostic without changing any circuit records
2026-10-05 Preserve complete G350 board and chat for Codex cloud continuation
    [g350-byte0.kicad_pcb, g350-byte1-escapes.kicad_pcb, g350-converter-placement.kicad_pcb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]
2026-10-05 Record created G350 cloud environment and attached repositories
2026-10-05 Prepare verified Debian cloud setup with isolated KiCad 10
